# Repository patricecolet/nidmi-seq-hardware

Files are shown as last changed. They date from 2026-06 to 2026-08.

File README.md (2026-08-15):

# NiDMI Seq — Hardware

Cible matérielle du séquenceur **NiDMI Seq**. Design actif (branche
`etude/plexi-capacitif`) : **boîtier plexi + clavier piano capacitif 27 touches +
ruban**, **5 encodeurs** (→ 6 demandés, cf. BOM §3), **8 boutons PB86**, **écran 4,0″ 480×320**, LEDs SK6812,
MIDI (TRS), **CV/Gate**, sur **3× ESP32-S3-WROOM-1-N16R8**.

Le firmware embarquera le moteur `nidmi-sequencer-core` ; ce dépôt ne contient
que l'électronique (schéma, PCB, BOM, fabrication).

## Famille de dépôts

```
repo/
  nidmi-sequencer-core/   ← moteur séquenceur (DSP/logique)
  nidmi-seq-vst/          ← prototype VST/AU/Standalone (présentation + host)
  nidmi-seq-hardware/     ← CE DÉPÔT : carte ESP32-S3
```

## Arborescence

```
kicad/      projet KiCad (.kicad_pro / .kicad_sch / .kicad_pcb)
lib/        symboles & empreintes custom (.kicad_sym / .pretty)
scripts/    automatisation pcbnew (placement de grilles, génération)
docs/       architecture, choix de conception, BOM
```

## Docs (design actif)

- [`docs/VARIANTE_CAPACITIVE.md`](docs/VARIANTE_CAPACITIVE.md) — concept & rationale.
- [`docs/BOM.md`](docs/BOM.md) — **BOM figée** (réfs, cotes, implémentation) = source de vérité composants.
- [`docs/CONNECTEURS_MIDI.md`](docs/CONNECTEURS_MIDI.md) — connecteurs + front-end MIDI.
- [`docs/ETUDE_DIFFUSION_LED.md`](docs/ETUDE_DIFFUSION_LED.md) — étude lumière (chantier ouvert).
- [`mechanical/`](mechanical/) — modèle 3D paramétrique coté (OpenSCAD).
- [`docs/ARCHITECTURE.md`](docs/ARCHITECTURE.md) — *legacy* (ancienne archi MCP23017/PB86-touches).
- Ergonomie (source de vérité) : `nidmi-seq-vst/VISION_ERGO_HARMONIE.md`.

## Statut

🚧 Conception avancée : surface de contrôle + BOM figées, **sauf le nombre
d'encodeurs** — la conception en demande 6 au lieu de 5 (cf. [`docs/BOM.md`](docs/BOM.md) §3).
Électriquement acquis, mécaniquement à recaler. **Autre chantier ouvert** :
étude diffusion LED (cellule touche+LED). Ensuite : schéma KiCad.

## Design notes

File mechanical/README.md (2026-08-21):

# Mécanique — modèles paramétriques

> ## ⚠️ Deux fichiers sont PÉRIMÉS, gardés pour mémoire
> - **`facade.scad`** — implantation d'origine. Noires à espacement **régulier**
>   (ce n'est pas un clavier de piano), 5 encodeurs, écran 4,0″. Remplacé par
>   **`implantation.scad`**. Reste utile pour une seule chose : c'est le seul
>   modèle qui esquisse le **boîtier** (`show_box`).
> - **`cellule_plexi.scad`** — électrode dans une **poche fraisée** du plexi épais,
>   membrane de 1–1,5 mm. Concept **abandonné** : la pollution lumineuse mesurée
>   acceptable a permis de revenir au bloc plein, et l'électrode est passée sur une
>   plaque avant distincte. Remplacé par **`coupe_cellule.scad`**.
>
> Leurs rendus ont été supprimés du dépôt : une image fausse coûte plus cher
> qu'une image absente.

# Modèle d'origine (périmé) — façade plexi capacitive

Modèle **paramétrique OpenSCAD** de l'empilement façade :
**plexi** (couvercle) + **grille espaceur** (puits de lumière) + **PCB**
(électrodes capacitives en anneau + SK6812 centrale). Sert à visualiser
l'intégration LEDs / touch et à exporter STL (impression 3D, découpe).

## Fichier
- `facade.scad` — modèle. Tous les paramètres sont en tête de fichier
  (dimensions façade, pad, pitch, épaisseurs, trou LED, écran, encodeurs).

## Pré-requis
OpenSCAD (installé via `brew install --cask openscad`). Binaire : `openscad`.

## Rendu (images)
```sh
cd mechanical

# Vue de dessus + côtes (layout façade)
openscad -o facade_top.png --imgsize=1900,1050 --projection=p \
  --camera=184,75,0,0,0,0,650 -D 'show_dims=true' -D 'explode=0' facade.scad

# Vue éclatée (montre les 3 couches), sans côtes
openscad -o facade_explode.png --imgsize=1500,1100 \
  --camera=184,72,10,60,0,22,640 -D 'show_dims=false' -D 'explode=26' facade.scad

# Boîtier fermé (parois + fond + connecteurs)
openscad -o facade_box.png --imgsize=1700,1200 \
  --camera=160,80,-6,62,0,205,560 -D 'show_box=true' -D 'show_dims=false' -D 'explode=0' facade.scad

# Vue arrière (connecteurs : USB-C | MIDI IN/OUT | CV GATE CLK RST)
openscad -o facade_rear.png --imgsize=1800,900 \
  --camera=160,150,-8,74,0,180,360 -D 'show_box=true' -D 'show_dims=false' -D 'explode=0' facade.scad
```
`explode` : 0 = assemblé, >0 = écarte les couches en Z.
`show_dims` : true = affiche les côtes paramétriques (auto-lues des variables).
`show_box` : true = ajoute parois + fond + connecteurs (objet fermé).

## Cellule plexi épais (branche etude/plexi-epais-grave)
`cellule_plexi.scad` — coupe d'une cellule touche (électrode dans le plexi).
Deux variantes d'électrode via `elec_mode` :
- `"ring"` — anneau **cuivre** opaque + trou central, LED par le trou (membrane percée).
- `"ito"` — film **ITO transparent pleine surface**, la LED traverse l'électrode
  (membrane pleine, pas de hot-spot) + languette de contact. Cf. `docs/CONCEPT_PLEXI_EPAIS.md`.
```sh
# Coupe — variante anneau cuivre (cellule.png)
openscad -o cellule.png --imgsize=1500,950 \
  --camera=0,0,5,87,0,182,52 -D 'show_dims=false' -D 'elec_mode="ring"' cellule_plexi.scad
# Coupe — variante ITO pleine surface (cellule_ito.png)
openscad -o cellule_ito.png --imgsize=1500,950 \
  --camera=0,0,5,87,0,182,52 -D 'show_dims=false' -D 'elec_mode="ito"' cellule_plexi.scad
```
Params en tête : `plexi_t` (10), `membrane` (1,5), `wall`, `led_win`, `elec_mode`. `cut`=coupe.

## Clavier piano — géométrie de facteur (`clavier_piano.scad`)

Modèle dédié du clavier 27 touches, avec la **vraie irrégularité du piano** —
`facade.scad` plaçait les noires sur la limite entre deux blanches, ce qui n'est
pas un clavier de piano.

**Le modèle** : dans le groupe **do-ré-mi** (3 blanches, 2 noires) les talons de
blanche sont égaux entre eux ; dans le groupe **fa-sol-la-si** (4 blanches,
3 noires) ils le sont aussi, mais d'une *autre* valeur. D'où les décalages des
noires par rapport à la ligne de pas : **−1,25 / +1,25** pour do♯ et ré♯,
**−1,87 / 0 / +1,87** pour fa♯, sol♯ et la♯. Symétriques dans chaque groupe, et
**sol♯ exactement sur la ligne** — c'est la signature d'un clavier juste.

**Empilement modélisé** (cf. `../docs/ETUDE_DIFFUSION_LED.md`) : plaque acrylique
transparente découpée en 16 blanches séparées (chacune guide de lumière) · plaque
plus fine et sombre découpée en 11 noires, posée dessus · PCB de tranche **avant**
(16 LED, injection dans les blanches) · PCB de tranche **arrière**, moins haut
(11 LED, injection dans les noires) · caches avant/arrière masquant les PCB.

```sh
# Vue de dessus + côtes (décalages des noires, talons, largeur)
openscad -o clavier_top.png --imgsize=1900,900 --projection=p   --camera=145,29,0,0,0,0,430 -D 'show_dims=true' -D 'explode=0' clavier_piano.scad

# Vue éclatée (les 5 couches)
openscad -o clavier_explode.png --imgsize=1700,1150   --camera=147,25,12,60,0,22,640 -D 'show_dims=false' -D 'explode=24' clavier_piano.scad
```

### Échelle : format « mini-touches », pas piano réel

À `pitch_w = 18.5`, le clavier fait **294,8 mm** et tient dans les 320 mm de
façade. Au pas piano réel de 23,5 mm il faudrait **376 mm** — impossible ici.

Le facteur d'échelle est donc **0,787**… ce qui tombe précisément sur le format
**mini-touches** des contrôleurs du commerce (Arturia, Novation, Akai : 18–19 mm).
Ce n'est donc pas un compromis bâtard mais un standard établi, avec lequel les
joueurs sont déjà familiers.

**Largeur des noires — attention à la cote.** Une noire de piano est
**tronconique** : ~9,5 mm au sommet (où le doigt se pose) mais **13,7 mm à la
base**. Vue de dessus, et à plus forte raison sur une façade **plate** sans aucun
fruit, c'est la **base** qui fait la largeur apparente. Cotes normalisées :
blanche 23,5 mm, noire 13,7 mm → `black_ratio` = **0,583**. Prendre la cote du
sommet donne des noires visiblement maigres.

**Talons des blanches** (partie étroite entre les noires). Des talons **tous
égaux sont mathématiquement impossibles** : il faudrait résoudre en même temps
`3W = 3w + 2B` (groupe do-ré-mi) et `4W = 4w + 3B` (groupe fa-sol-la-si), ce qui
n'admet de solution que pour `B = 0`, donc sans noires. L'arrangement optimal des
facteurs de piano, et le défaut du modèle :

| | talon |
|---|---|
| do, ré, mi | `W − 2B/3` |
| fa, sol, la, si | `W − 3B/4` |

L'écart entre les deux vaut `B/12` — c'est le minimum atteignable.
Refs : [mathpages](https://www.mathpages.com/home/kmath043.htm) ·
[quadibloc](http://quadibloc.com/other/cnv05.htm) ·
[PianoReport](https://pianoreport.com/piano-key-size/)

`tails = [...]` permet de forcer les sept cotes pour coller à un clavier
particulier.

> **Contrainte** : somme des 7 talons + 5 × largeur de noire = 7 × pas. Sinon les
> talons dérivent par rapport aux faces avant, qui restent à pas égal. Le modèle
> vérifie et le signale par un `echo`.

### Les deux plaques découpées, et le travail que ça représente

```sh
openscad -o plaque_blanches.png --imgsize=2000,560 --projection=o \
  --camera=147,29,60,0,0,0,330 -D 'vue_plan=true' -D 'piece="blanches"' clavier_piano.scad
openscad -o plaque_noires.png --imgsize=2000,560 --projection=o \
  --camera=147,29,60,0,0,0,330 -D 'vue_plan=true' -D 'piece="noires"' clavier_piano.scad
```

| plaque | matière | pièces | longueur de coupe |
|---|---|---|---|
| blanches | acrylique clair **10 mm** | 16 | **4,03 m** (dont 22 encoches de 36,8 mm) |
| noires | acrylique teinté **5 mm** | 11 | **1,03 m** |
| | | **27** | **5,06 m** |

> **Découpe laser, pas Dremel.** Ces 4 mètres sont des **chants optiques** : ce
> sont eux qui font fonctionner le guide de lumière, donc chacun doit être poli.
> Le laser fond la matière au lieu de l'arracher et sort des chants
> **naturellement polis, de qualité optique** — on obtient gratuitement ce que le
> Dremel imposerait de polir à la main sur 4 mètres. Pour un guide de lumière ce
> n'est pas un confort mais une condition de fonctionnement.
>
> Le Dremel reste l'outil de la **gravure au dos**, qui veut au contraire une
> surface diffusante.

## Édition interactive
Ouvrir `facade.scad` dans l'app OpenSCAD → fenêtre de preview, on tourne/zoome,
on modifie un paramètre, F5 = aperçu, F6 = rendu final.

## Export STL (impression / découpe)
```sh
# Plexi seul, à plat, pour découpe laser ou impression
openscad -o plexi.stl -D 'explode=0' facade.scad   # (puis isoler la couche voulue)
```
> Pour exporter une couche isolée, commenter les deux autres appels en bas de
> `facade.scad` (`layer_pcb(); layer_spacer(); layer_plexi();`).

## À garder en tête (cf. `../docs/VARIANTE_CAPACITIVE.md`)
- Le modèle est **illustratif** (proportions justes, pas un fichier de fab).
- Entrefer `spacer_t` = compromis sensibilité capacitive ↔ logement LED.
- Hauteur LED `led_h` à caler sur le boîtier SK6812 réel (3535 ≈ 1,6 mm).
- Layout façade = format compact 4×4 (~170×262) ; modifiable via les paramètres.

## Implantation de façade — deux variantes (`implantation.scad`)

Toutes les cotes de façade sont **calculées depuis les composants** : changer une
dimension de composant recalcule l'objet, et les totaux sortent en `echo`. Le
clavier est **importé** de `clavier_piano.scad`, pas redessiné.

```sh
openscad -o implantation_complete.png --imgsize=1400,1150 --projection=o \
  --viewall --autocenter -D 'variante="complete"' implantation.scad
openscad -o implantation_modeste.png --imgsize=1400,1150 --projection=o \
  --viewall --autocenter -D 'variante="modeste"' implantation.scad
```

| variante | façade | contenu |
|---|---|---|
| **complete** | **328 × 185 mm** | clavier 27 touches, écran, 6 encodeurs, 8 boutons, ruban 136 mm |
| **modeste** | **230 × 141 mm** | idem **sans clavier** — module de bureau, notes par MIDI externe |

**Le 6ᵉ encodeur passe** (décision 🔴 du BOM §3), en **deux rangées de trois** au
pas de 30 mm. En une seule rangée de six au pas de 33 il fallait 306 mm pour 296
disponibles ; en 2×3 la rangée haute ne fait plus que 206 mm de large.

**Le ruban passe de 180 à 136 mm** : boutons + ruban sur une même rangée
demandaient 340 mm pour 296 disponibles.

> **Place disponible pour l'écran : 206 mm de large**, contre 108 pour le module
> 4,0″ actuel. Un **7 pouces** (≈165 × 100 mm) rentre en largeur sans rien
> déplacer ; il coûte ~38 mm de profondeur (façade complète ~223 mm) et remplit
> le quadrant supérieur droit, actuellement vide.

> **Les deux variantes partagent la même rangée haute** (écran + encodeurs,
> 206 × 62). La modeste = la complète moins la rangée clavier — même
> sous-ensemble électronique et même firmware d'interface possibles.

## Plan global d'encombrement — `implantation.scad -D plan=true`

> 🟢 **2026-08-21 — le boîtier peut être dessiné.** Les cotes du CrowPanel
> Advance 7.0-HMI ont été **fournies par l'utilisateur**, qui a passé la commande
> et relevé les dimensions : elles ne figurent ni sur la fiche produit ni sur
> espboards. C'est la référence du projet — **ne pas chercher à les re-sourcer**.

> ⚠️ **Un seul fichier, pas trois.** Le plan a d'abord été écrit dans un
> `encombrement.scad` séparé, et `boite.scad` traînait encore à côté. Résultat :
> **trois modèles avec trois cotes de clavier différentes** (58+5, 52+18, et un
> ruban placé dans une rangée derrière le clavier). Les deux fichiers en trop ont
> été **supprimés** et tout est revenu dans `implantation.scad`.
>
> **Règle qui en sort : on corrige le modèle existant, on n'en ajoute pas un à
> côté.** Un modèle de plus, c'est une cote de plus à tenir à jour, et c'est comme
> ça qu'on fabrique des contradictions.

```sh
# le PLAN (3 vues 2D cotées)
openscad -o encombrement.png --imgsize=1500,2500 --projection=o \
  --camera=175,-15,0,0,0,0,1900 --colorscheme=Tomorrow -D 'plan=true' implantation.scad

# le modèle 3D de la façade (comportement par défaut, inchangé)
openscad -o implantation_complete.png --imgsize=1400,1150 --projection=o \
  --viewall --autocenter -D 'variante="complete"' implantation.scad
```

Chaque vue **nomme son plan de coupe** — c'est le point d'ambiguïté récurrent :

| vue | plan de coupe |
|---|---|
| **A** dessus | aucun — façade de face, tranche arrière rabattue au-dessus |
| **B** coupe longitudinale | vertical, axe avant-arrière, **au milieu** : traverse le clavier **et** l'écran |
| **C** coupe transversale | vertical, gauche-droite, **au droit de la rangée haute** |

Le clavier **en travers** n'est pas repris — `coupe_cellule.scad` le traite.

### Ce que le plan donne

| | cote |
|---|---|
| façade | **337,26 × 226,36 mm** (hors-tout 342,26 × 231,36) |
| hauteur intérieure | **33 mm** — minimale calculée 32,6 |
| hors-tout | **342 × 231 × 36,5 mm** |

**La largeur est imposée par la rangée haute** (313,26 mm), pas par le clavier
(298,8).

### La façade est un cache, et le plexi passe dessous

Décidé le 2026-08-21. La pièce de plexi n'affleure plus : elle est **sous la
façade**, que le doigt atteint par **deux ouvertures** — une pour les touches,
une pour le ruban. La bande de façade entre les deux **masque le dos du peigne
des noires et la zone de contact du film**, et un bord arrière masque la fin du
dos.

> 🔴 **Conséquence : le dos ne pouvait pas rester à 18 mm.** Il ne loge pas que
> le ruban ; il doit aussi donner à la façade de quoi cacher. Décompte :
>
> | | mm |
> |---|---|
> | cache (entre les deux ouvertures) | **6** 🔴 estimé |
> | jeux d'ouverture (3 × 1) | 3 |
> | ruban | 10 |
> | bord arrière | **5** 🔴 estimé |
> | **dos nécessaire** | **24** — il en manquait **6** |
>
> La pièce de plexi passe donc de 70 à **76 mm**, et la façade de 220,36 à
> **226,36**. Les deux valeurs en rouge sont des estimations : la largeur du cache
> devrait être dimensionnée sur l'encombrement réel de la reprise de contact
> (piste d'argent + connecteur ZIF), qui n'est pas encore arrêtée.

> ⚠️ `clavier_piano.scad` porte `Wh` et `dos` **en dur** (`use <>` n'importe pas
> les variables). Ils doivent valoir ce que calcule `implantation.scad` —
> **76 et 24**. Un echo le vérifie et crie `DESYNCHRONISE` sinon : c'est
> exactement le décalage qui, la fois précédente, avait laissé le ruban hors du
> plexi.

> 🔴 **Le poste dimensionnant en hauteur n'est plus l'écran : c'est le PB86.**
> À 20 mm il dépasse les 16 mm du CrowPanel. Or cette cote est **estimée** — le
> BOM note « hauteur/cap non publiés → STEP GrabCAD (`pb86-switches-1`) ». Tant
> qu'elle n'est pas relevée, l'épaisseur de l'instrument n'est pas figée.
>
> Les **~25 mm** du BOM §11 sont périmés : ils dataient du module 4,0″.

> 🟡 **Pas encore placés** : le PCB principal, les deux ESP32 et le câblage. Leur
> volume est réservé (12,6 mm) mais leur position attend le KiCad. Les zones
> **jaunes** sont ce qui reste libre.

### Les cartes, et la place qu'elles ont

Quatre cartes identifiées, plus l'alimentation qui n'est pas placée.

| carte | taille | note |
|---|---|---|
| **latérale gauche** (ESP32-B) | **71,5 × 131,9 mm** — 94 cm² | double face : boutons + molettes devant, ESP32 derrière |
| **latérale droite** (ESP32-C) | idem | idem |
| **LED avant** | 294,8 × 8 mm, verticale | 16 LED, injection en tranche des blanches |
| **LED du dessous** | 294,8 × 56 mm | posée sur le socle, dans la découpe de la mousse |

**Les latérales sont dimensionnées au maximum utilisable**, pas à l'emprise des
commandes. La rangée de boutons et molettes ne fait que 66 × 108,36 (71,5 cm²) ;
en prenant tout ce qui est libre à cette hauteur on obtient **94 cm², soit un
tiers de plus**. Les limites sont réelles, pas arbitraires :

- **en largeur**, jusqu'au bord de l'écran — au-delà, le CrowPanel descend à
  −16 mm alors que la carte est à −9,6 : elle ne peut pas passer dessous ;
- **en profondeur**, de l'arrière du clavier à la paroi arrière — vers l'avant, la
  pièce de plexi descend à −16,3 et barre le passage.

Hauteur disponible : **8 mm au-dessus** de la carte pour les composants
traversants, **23,4 mm en dessous** pour tout le reste. La carte s'arrête à 2 mm
de la paroi arrière, donc l'USB-C et des jacks peuvent y être **en bord de carte**.

**La connectique est en bord de carte**, plus de carte de connectique séparée ni
de fils vers la tranche : les latérales arrivent à 2 mm de la paroi arrière.

| | contenu | occupé / dispo |
|---|---|---|
| **gauche** | USB-C + CV, GATE, CLK, RST | **71** / 71,5 mm |
| **droite** | MIDI IN, MIDI OUT + audio L/R | **62** / 71,5 mm |

La répartition sépare l'**alimentation** (USB-C et les sorties 5 V, à gauche) des
**sorties audio** (à droite, loin du convertisseur à découpage, et du côté où
irait le moteur audio). L'entraxe de 12 mm n'est pas dicté par les embases mais
par le **diamètre des fiches** : une fiche 3,5 fait ~9 mm de corps, il faut
pouvoir la saisir. Le côté gauche est plein à 0,5 mm près.

> ⚠️ **Corrigé au passage** : `n_jack` valait **5** alors que son propre
> commentaire listait six jacks — MIDI IN, MIDI OUT, CV, GATE, CLK, RST. Il
> manquait donc un jack sur la tranche depuis le début.

> 🟡 Reste ouvert : ces deux cartes sont-elles **identiques** ? L'implantation
> étant boutons à l'extérieur et molettes à l'intérieur des deux côtés, la même
> carte tournée de 180° présente le bon ordre de l'autre côté — un seul dessin,
> une seule série. Charger l'une de l'alimentation et l'autre du moteur audio y
> ferait renoncer.

### Trois erreurs de dessin corrigées le jour même

**Les noires étaient tracées en bande pleine.** La position était juste mais la
lecture fausse : la bande coupait le plexi en deux et laissait croire que **la
pièce s'arrêtait avant le ruban**, alors qu'elle est d'un seul tenant — 52 mm de
blanches plus 18 de dos. Les onze noires sont maintenant tracées séparément, aux
décalages de facteur de piano, pour qu'on voie les **talons des blanches** passer
entre elles. C'est l'article 2 du skill `conception-meca` : le relief des noires
est **usiné dans la plaque**, il n'interrompt rien.

**La coupe B montrait un relief de noire qui n'existe pas là.** Prise au milieu,
elle tombe entre **si et do** — deux blanches adjacentes.

**Le clavier était dessiné en un bloc de 16,3 mm**, ce qui le faisait paraître
plus épais que l'écran. Faux : **le plexi ne fait que 10 mm**, donc *moins* que
les 16 de l'écran. Les 6 mm restants sont la **suspension** — mousse et socle.
Les couches sont désormais distinctes et cotées.

### Cotes réconciliées entre les trois modèles

`clavier_piano.scad` portait encore la géométrie d'avant l'architecture arrêtée.
Aligné sur `coupe_cellule.scad` :

| | avant | après |
|---|---|---|
| **pièce entière** (`Wh`) | 58 | **70** |
| dos du peigne (`dos`) | 5 | **18** — il porte le ruban |
| noire (`Bh` / `Lb`) | 36 | **32** |
| noires (`t_noires`) | plaque teintée 5 mm | **relief usiné de 1 mm** |
| caches | affichés | **supprimés** — c'est la boîte qui fait cet office |

> 🔴 **Le piège qui a fait rater le clavier deux fois : `Wh` est la longueur
> TOTALE de la pièce, dos inclus** — et non la partie avant. C'est
> `y_dents = Wh - dos` qui donne la fin des touches. En lisant `Wh` comme « la
> blanche » et en posant `Wh = 52, dos = 18`, on obtient une pièce de **52 mm**,
> pas de 70 : le plexi s'arrête alors **16 mm avant le ruban**, qui flotte dans le
> vide. Bon réglage : `Wh = 70`, `dos = 18`.
>
> Deux conséquences ont dû être corrigées dans la foulée :
> - `by0` mesurait la noire **depuis le fond de la pièce**, donc le dos la
>   rognait — avec un dos de 18 il n'en restait que 14 mm au lieu de 32. La noire
>   part maintenant de `y_dents - Bh` : elle fait `Bh` et **bute sur le dos**.
> - `noires_2d()` **inclut `dos_2d()`**, héritage de l'époque où les noires
>   étaient une plaque teintée rapportée avec son propre dos. Utilisé tel quel, le
>   dos sortait tout noir et le ruban disparaissait dessous. Le modèle 3D appelle
>   donc `blacks_2d()`, qui ne donne que le relief.
>
> 🟡 **Reste à trancher** : `clavier_piano.scad` sépare les blanches sur toute la
> zone de touche (52 mm), alors que `coupe_cellule.scad` arrête le trait de scie à
> **20 mm**. Les deux ne peuvent pas être vrais.

> ⚠️ `use <>` n'importe **que les modules et fonctions, pas les variables**. Les
> décalages des noires sont donc recopiés dans `implantation.scad` (`noires_plan`)
> pour la vue de dessus du plan, et doivent suivre `clavier_piano.scad`.

## Assemblage du clavier (`coupe_cellule.scad`)

> ### 🟢 2026-08-21 — architecture arrêtée en séance de conception
>
> Trois décisions structurent tout le reste. Elles remplacent le clavier plat et
> le peigne rapporté, tous deux abandonnés le même jour.

**1 — Une plaque continue d'acrylique par-dessus l'ITO**, avec le relief des
noires **usiné dedans**. Elle pince le film sur toute sa surface, protège
l'électrode partout et supprime la colle. Le doigt voit 1 mm sur une blanche,
2 mm sur une noire.

> 🔴 **Le seul chiffre qui verrouille le reste : l'aftertouch à 1–2 mm.**
> Mesuré : à travers **0,125 mm** (PET seul) la marge suffit ; à travers **10 mm**
> le contact est détecté mais l'aftertouch est perdu. L'intervalle n'est pas sondé.
> Se pince en un quart d'heure en empilant des chutes de PET sur une électrode et
> en relevant la dynamique entre effleurement et appui franc.
> **Une noire en relief rapporté de 3 mm était condamnée par là** : aftertouch sur
> les blanches et pas sur les noires, intenable sur un clavier.

**2 — Un seul film ITO pour tout**, touches et ruban gravés d'un seul coup. Un
seul calage, figé par le **masque** et non par le montage.

**3 — Trois éclairages indépendants.** Les blanches par la tranche avant, en
lumière guidée, extraite par la gravure. Les **noires et le ruban par en
dessous**, sur une **même carte horizontale**.

> **L'argument optique qui rend le point 3 possible.** Une LED couplée par
> l'**air** n'émet dans le PMMA qu'à **±42°** — exactement l'angle critique. Tout
> sort donc au premier contact et **rien ne passe en mode guidé** : cette lumière
> ne peut pas voyager horizontalement, donc elle n'interagit pas avec la gravure
> des blanches. Deux corollaires à ne jamais oublier :
> - **ne rien coller sous ces LED** — un indice ~1,5 rouvrirait le cône à 90° et
>   l'isolement disparaîtrait ;
> - **satiner le dessous de la plaque**, jamais la face inférieure du bloc, qui
>   renverrait de la lumière en mode guidé.

### Ce qui a été supprimé, et ce que ça rapporte

| supprimé | pourquoi | gain |
|---|---|---|
| cloison transversale + 2ᵉ symbole | l'écran porte le détail | 16 rainures et 16 lamelles en moins |
| lamelle noire des traits de scie | apportait plus de problèmes que de solutions | 15 pièces en moins |
| fente arrière + PCB partagé par la tranche | les LED sont passées dessous | une lame verticale en moins |

Le trait de scie **s'arrête à 20 mm** au lieu de descendre jusqu'à l'arrière :
plus aucun trait sous les noires ni sous le ruban, le bloc reste continu à
l'arrière, et les dents passent de porte-à-faux de 52 mm à des entailles de 20.
Le peigne cesse d'être la pièce fragile du projet.

Ce que portait le 2ᵉ symbole se répartit : **l'écran** prend le détail, la **LED
de la blanche** porte la grille métrique en fond sous l'état actif, et **un trait
de scie sur quatre** marqué donne le repère au doigt — les 16 blanches sont déjà
une rangée de 16 pas uniformes, il suffit de la marquer.

### Les cinq vues

**A** coupe en travers avant (moins de 20 mm du bord : la seule zone fendue) ·
**B** coupe en travers arrière au droit d'une noire (bloc continu, poche et LED
par en dessous) · **C** coupe en long d'une blanche jusqu'au ruban · **D** vue de
dessus du bloc (ce qui est usiné, et où) · **E** le film à plat.

```sh
openscad -o coupe_cellule.png --imgsize=1500,3000 --projection=o \
  --camera=58,-192,0,0,0,0,1080 --colorscheme=Tomorrow coupe_cellule.scad
```

| couche | ép. | rôle |
|---|---|---|
| **plaque acrylique** | 1 mm | la surface touchée · relief des noires usiné dedans (+1 mm) |
| **PET** | 0,125 mm | porteur du film |
| **ITO gravé** | ~0 | îlots d'électrodes ; la **garde est la mer** autour |
| film d'air | ~0,1 mm | le film est **plaqué** par la plaque, pas collé |
| **bloc PMMA** | 10 mm | guide de lumière des blanches · traits de scie sur 20 mm · poches par le dessous |
| fond sombre | ~0,05 mm | absorbe le halo non extrait · **fenêtre** sous chaque noire |
| mousse | 3 mm | **le ressort** — à faible déformation rémanente |
| socle | 2 mm | référence **rigide** des LED |

### Contact de l'électrode

**On ne contacte jamais l'ITO directement.** L'industrie sérigraphie par-dessus
une piste d'**argent** — le liseré sombre au pourtour des dalles tactiles — et
c'est l'argent qu'on contacte. L'encre d'argent fait ~0,01 Ω/□ contre ~100 Ω/□
pour l'ITO, soit des milliers de fois moins : **la distribution peut donc rester
sur le film** et sortir par une queue unique dans un connecteur à charnière.

Deux règles quelle que soit la solution retenue :

- la contrainte sur l'ITO doit être **uniquement perpendiculaire** à la surface.
  Jamais de cisaillement, jamais de traction : il fissure.
- **ancrer le film au niveau du contact** et le laisser flotter à l'autre bout.
  L'acrylique se dilate ~4× plus que le PET — **0,3 mm** sur la longueur du
  clavier pour 20 °C — et un film pincé aux deux bouts se met en tension.

> 🟡 L'argent migre sous tension continue en milieu humide. Parade proportionnée :
> surimpression diélectrique laissant les plages nues, ou vernis de tropicalisation
> sur la jonction. Le risque reste faible ici — plages espacées de millimètres,
> 3,3 V, boîtier clos, et pilotage en charge-décharge plutôt qu'en continu.

### La carte LED du dessous, et la découpe de la mousse

🔴 **La carte LED est POSÉE SUR LE SOCLE, et la mousse est découpée pour elle.**
Point rappelé par l'utilisateur le 2026-08-21 après avoir été perdu une fois —
il ne doit plus l'être. Trois conséquences :

- **Elle ne s'ajoute pas à l'empilement.** Elle vit *dans* l'épaisseur de la
  mousse, pas entre le bloc et elle. Le clavier reste à 16,3 mm sous la face
  touchée.
- **La mousse est le ressort ; la découper lui retire de l'appui** là où la carte
  passe, c'est-à-dire sous les noires et sous le ruban — donc sur presque toute la
  largeur. Il faut vérifier ce qu'il reste comme surface d'appui, et où, sinon le
  bloc s'appuie sur une couronne et fléchit au milieu.
- **La cote tombe juste, mais sans marge** : carte ENIG 0,6–0,8 + SK6812 3535
  ~1,9 = **~2,7 mm** au-dessus du socle, pour **3 mm** de mousse. La LED affleure
  sous le bloc sans entrer dans la poche — l'air est conservé, ce qui est
  exactement ce qu'on veut pour garder le cône à ±42°.

### Serrage

**Ne jamais serrer du rigide sur du rigide** : la pression devient imprévisible et
l'acrylique fissure. La **mousse est le ressort** ; les vis ne fixent qu'une
position, la mousse la convertit en force. Elle pousse le bloc contre la lèvre du
cadre supérieur, ce qui référence la face touchée sur une pièce **rigide** — c'est
ce qui garantit que la distance LED↔surface, donc le **diamètre des taches**,
reste identique d'une touche à l'autre.

On dimensionne donc un **écrasement**, pas un couple. Vis M3 dans des écrous logés
en poches usinées, jamais de taraudage dans l'acrylique, un point tous les 50 à
80 mm, et des **trous de passage surdimensionnés** à cause de la dilatation.

### Ruban

Sur le dos du peigne, même pièce de plexi — 24 mm de profondeur de façade libérés
puisqu'il n'a plus de rangée propre. **5 canaux**, interpolation spatiale, cotes
d'AT11805 : segments de bout **33,75 mm**, de milieu **56,25 mm** sur 180, zone
morte ramenée de 10 % à **3 %**, dents **4 mm** max et **0,25 mm** mini en pointe.

C'est un **témoin**, pas un vu-mètre : peu de LED et **interpolation lumineuse**
entre voisines, le recouvrement des halos faisant glisser la tache. Critère de
choix du pas : **pas ≤ largeur du halo**, à mesurer au banc. Le fondu ne sera pas
linéaire (le PWM l'est, la perception non) — la courbe se règle à l'œil.

> 🟡 **`clavier_piano.scad` modélise encore les noires en plaque teintée de 5 mm**
> — à réconcilier quand les cotes seront figées.

## Coupe d'une cellule (`coupe_cellule.scad`) — ⛔ **VERSION PÉRIMÉE, gardée pour mémoire**

> ⛔ **Ce qui suit décrit l'architecture d'AVANT le 2026-08-21** : deux plaques séparées
> par un entrefer de 1,5 mm, plaque avant de 2 mm, noires en relief rapporté de 3 mm,
> 18,7 mm d'empilement. **Remplacée** par « Assemblage du clavier » plus haut — plaque
> continue de 1 mm, relief usiné dedans, film plaqué sur le bloc.
>
> 🟡 **Un point de cette section reste ouvert et n'a pas été rejugé** : l'argument optique
> qui justifiait l'entrefer. L'ITO plaqué contre la face du guide met celui-ci en
> **réflexion totale frustrée** (l'indice du PET est proche de celui du PMMA) — la lumière
> sortirait sur tout le trajet au lieu de sortir aux points gravés. L'architecture actuelle
> a ramené l'entrefer à un **film d'air de ~0,1 mm**. Est-ce suffisant ? **À trancher.**

Coupe **en travers du clavier** : deux blanches et la noire posée à cheval.
Dessinée **explicitement en 2D** plutôt que découpée dans un modèle 3D — ce qu'on
voit est exactement ce qu'on a voulu montrer.

```sh
openscad -o coupe_cellule.png --imgsize=2000,900 --projection=o \
  --camera=50,-10,0,0,0,0,142 coupe_cellule.scad
```

| couche | ép. | rôle |
|---|---|---|
| plaque avant PMMA | 2 mm | surface touchée, rainures peu profondes côté doigt |
| ITO + bus bar | 0,125 mm | **électrode, découpée par touche** + garde à la masse |
| **entrefer** | 1,5 mm | garde la réflexion totale **et** loge les fils de bus bar |
| guide de lumière | 10 mm | LED en tranche, gravure (points, gradient) au dos |
| fond sombre | ~0,05 mm | absorbe le halo non extrait → contraste + anti-pollution |
| mousse | 3 mm | répartit la pression vers l'avant |
| plaque arrière | 2 mm | vissée **en périphérie** — aucune fixation visible |
| | **18,7 mm** | + 3 mm de relief pour les noires |

**Pourquoi deux plaques et pas un bloc.** Le guide ne fonctionne que si ses faces
sont au contact de l'**air**, et le capacitif veut l'électrode **près du doigt**.
Deux arrangements plus simples ont été écartés :

- **électrode derrière le guide** (doigt → 10 mm) : 1 % de signal mesuré, pas
  d'aftertouch, et l'ITO plaqué contre la face gravée met le guide en réflexion
  totale frustrée — la lumière sort partout au lieu de sortir aux points ;
- **électrode sur la face avant du guide** : capacitif excellent, mais l'indice du
  PET est proche de celui du PMMA → la lumière s'échappe sur tout le trajet.

L'entrefer résout les deux : il maintient la réflexion totale et sépare l'ITO de
la face gravée. Il sert en plus de logement aux fils de bus bar.

**Ce que la coupe montre au droit d'une noire.** L'électrode de la noire (violet)
est **dans le même plan** que celles des blanches : un seul film ITO porte le
**dessin complet du clavier**. Et les électrodes des blanches **s'arrêtent de part
et d'autre** — c'est l'équivalent électrique exact du talon de blanche sur un
piano. Sans cette troncature, toucher une noire déclencherait les deux blanches
sous elle. La géométrie de facteur de piano n'est donc pas qu'une affaire
d'apparence : **c'est le dessin de l'électrode**.

La noire est par ailleurs **son propre guide de lumière**, gravure sur sa face
inférieure, injection par la tranche arrière (invisible en coupe transversale).

> ⚠️ **Les noires sont pénalisées deux fois** : le doigt est à **5 mm** au lieu de
> 2 (3 mm de relief + 2 de plaque), **et** l'électrode est plus petite (~8,4 × 36
> contre ~16 × 45). Le signal variant en gros comme surface/distance, une noire
> est de l'ordre de **six fois moins sensible** qu'une blanche. La détection passe
> largement — seuils par canal, marge de plusieurs centaines. L'**aftertouch**, lui,
> devient douteux sur les noires.
>
> L'épaisseur de la plaque teintée n'est donc **pas** un simple choix
> d'approvisionnement, c'est un **paramètre capacitif** : à 2 mm au lieu de 3, le
> rapport tombe de 6 à ~4,5.

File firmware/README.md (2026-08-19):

# firmware — bancs de test

Croquis Arduino de mesure, pas de code produit. Compilés avec `arduino-cli`
(core `esp32:esp32` 3.3.1, IDF 5.5).

## `test_touch_ito/` — sensibilité capacitive d'une électrode ITO

Lit N canaux *touch*, calibre une ligne de base + son bruit au démarrage, puis
sort en continu du CSV `t_ms,ch,raw,delta,snr` sur le port série à 115200.
`delta` est normalisé **positif au toucher** sur les deux générations de touch
(v1 ESP32 : la valeur descend ; v2 S2/S3 : elle monte).

Broches par défaut (à ajuster en tête du `.ino`) :

| Cible | Canaux | GPIO |
|---|---|---|
| ESP32-S3 (touch v2) | TOUCH4–7 | 4, 5, 6, 7 |
| ESP32 classique (v1) | T0, T4, T6, T7 | 4, 13, 14, 27 |

Sur S3 tout GPIO1–14 est touch-capable ; on évite 0 / 45 / 46 (strapping).

### Compiler et téléverser

```sh
cd firmware/test_touch_ito

# ESP32-S3-WROOM-1 N16R8, via le port USB-UART de la carte
arduino-cli compile -b esp32:esp32:esp32s3:PSRAM=opi,FlashSize=16M .
arduino-cli upload  -b esp32:esp32:esp32s3:PSRAM=opi,FlashSize=16M -p /dev/cu.usbXXXX .

# variante : port USB natif du S3 (série sur l'USB de la puce)
arduino-cli compile -b esp32:esp32:esp32s3:PSRAM=opi,FlashSize=16M,CDCOnBoot=cdc .

# ESP32 classique
arduino-cli compile -b esp32:esp32:esp32 .
```

Trouver le port : `ls /dev/cu.usb*` (ou `arduino-cli board list`).

### Lire les mesures

```sh
arduino-cli monitor -p /dev/cu.usbXXXX -c baudrate=115200   # brut
scripts/touch_log.py --secs 10 --out mesures/ito_25mm_plexi15.csv \
                     --label "ITO 25x25 / membrane 1,5 mm"   # + résumé stats
```

Commandes série : `b` = refaire la ligne de base (main éloignée), `h` = aide.

### Observer en direct pendant un test

```sh
scripts/touch_scope.py --port /dev/cu.usbmodemXXXX   # puis http://localhost:8765
```

Sert une page locale qui se rafraîchit toute seule : **histogramme** des valeurs
brutes (vue principale), chronogramme, stats par canal, et un bouton qui envoie
la recalibration à la carte.

L'histogramme est la bonne vue ici, et pas la moyenne : un contact intermittent
apparaît comme **plusieurs pics séparés** — broche nue / électrode au repos /
doigt posé — là où une moyenne afficherait une valeur intermédiaire qui ne
correspond à aucun état réel. C'est ce qui a permis de voir que l'électrode
décrochait, et pas seulement qu'elle était « bruitée ».

**Le scope redémarre la carte en s'y connectant**, et c'est nécessaire : sur l'USB
natif du S3, une carte déjà en marche dont l'hôte précédent s'est déconnecté
**n'émet plus rien** pour le suivant. Le reset garantit aussi une entête (donc la
correspondance canal→GPIO) et une ligne de base fraîches. Compter ~10 s de
préchauffage et de calibration, main éloignée. `--no-reset` pour s'attacher sans
perturber une mesure en cours — mais la carte peut alors rester muette.

> Un seul programme à la fois peut ouvrir le port série : arrêter `touch_log.py`
> avant de lancer `touch_scope.py`, et inversement. Le scope reprend tout seul
> si la carte est débranchée puis rebranchée.

> Commandes série du croquis : `b` = recalibrer · `i` = réimprimer l'entête
> canal→GPIO (sans toucher à la ligne de base) · `h` = aide.

Protocole d'essai complet : [`docs/ESSAI_ITO_ESP32.md`](../docs/ESSAI_ITO_ESP32.md).

## `banc_cellules/` — cellule complète : 4 touches + 4 LED appairées

Le banc à utiliser pour tester une implantation réelle. Reprend la mesure tactile
de `test_touch_ito` (même format CSV, donc `touch_scope.py` et `touch_log.py`
fonctionnent tels quels) et y ajoute 4 LED, **une par canal**.

| | broches |
|---|---|
| électrodes | GPIO **8, 9, 10, 12** |
| LED | GPIO **15, 16, 17, 18** → `100 Ω` → anode ; cathodes au GND commun |

**Modes LED** (boutons dans le client, ou touche série) : `t` tactile — la LED *n*
s'allume quand la touche *n* est touchée · `r` rampe 5 s · `c` clignotement ·
`f` fixe · `x` éteint. Luminosité au curseur (ou `L0`…`L255` en série).

Détection : seuil = `max(8σ, 150 counts)` au-dessus de la ligne de base, avec
**hystérésis à 60 %** pour éviter le battement quand le doigt effleure la limite.
Les seuils calculés sont affichés à la calibration, et chaque passage touché ⇄
relâché est annoncé sur le port série.

> **Les oranges, rouges et vertes traditionnelles (seuil ~2 V) se pilotent
> directement depuis un GPIO** en 3,3 V : (3,3 − 2,0)/100 = ~13 mA. Une **bleue**
> ou une **blanche** (seuil ~3 V) n'y arriverait pas — ~2 mA, invisible. Pour
> celles-là, rail 5 V et montage où le GPIO tire le courant (logique inversée).

## `scan_touch/` — quelles broches touch sont réellement utilisables

À passer **avant** de figer un brochage, et à chaque recâblage. Fait deux choses :

1. **Intégrité électrique** de GPIO1–14 (`INPUT_PULLUP` puis `INPUT_PULLDOWN`) :
   `pu=1 pd=0` = broche libre · `pu=1 pd=1` = tirée au 3V3 · `pu=0 pd=0` = à la
   masse. Une broche tirée d'un côté ou de l'autre **ne peut pas mesurer** : le
   pad ne se charge plus et le canal part en timeout.
2. **Balayage touch** des 14 canaux. Un canal qui rend `4194303` (0x3FFFFF) ne
   mesure pas — ce n'est pas une capacité énorme, c'est une mesure qui n'aboutit
   pas. Compter ~2 s par canal en échec.

**GPIO4 et GPIO5 sont le bus I2C de la carte** (SDA/SCL), avec leurs pull-ups de
10 kΩ montées d'origine — mesuré 9 kΩ vers 3V3, carte hors platine, contre 500 kΩ
sur GPIO6. Elles ne peuvent pas servir au tactile, et le BOM les réserve déjà à
l'I2C (MCP23017, MCP4728).

Mesuré sur la carte ESP32-S3-WROOM-1 N16R8 du proto : seules **GPIO8, 9, 10, 12**
donnent des valeurs exploitables (~30 000 counts, bruit σ = 8 à 104). Les autres
saturent, y compris des broches électriquement libres. Ne pas supposer qu'une
broche marche parce que la doc la dit touch-capable.

> Le message `touch_sensor_trigger_oneshot_scanning: Wait for measurement done
> timeout` du core 3.3.1 apparaît sur **tous** les canaux, y compris ceux qui
> rendent ensuite des valeurs valides. Ce n'est pas un critère d'échec.

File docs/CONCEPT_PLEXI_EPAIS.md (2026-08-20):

# Concept — électrodes DANS le plexi épais (proto Dremel)

> **Branche `etude/plexi-epais-grave`.** Alternative à la branche capacitive
> `etude/plexi-capacitif` (où l'électrode, portée par un PCB sous l'entrefer des
> encodeurs + 2 PCB, était à **5-9 mm** du doigt → capacitif trop faible).
> Ici l'électrode est **portée par le plexi lui-même**, à ~1,5 mm de la surface.
> Le reste de l'archi (3× ESP32-S3, écran, MIDI, CV, encodeurs, PB86, LED) est
> **réutilisé** depuis la branche capacitive ([`BOM.md`](BOM.md)).

## Problème résolu
Capacitif : sensibilité ∝ **surface électrode / épaisseur diélectrique**. Avec un
PCB loin sous le plexi, le diélectrique = entrefer (air) + plexi → trop épais.
→ On amène l'électrode **juste derrière la face avant**, dans le plexi.

## Principe
- **Plexi épais** (~**8-12 mm**, acrylique coulé) = panneau **et** substrat. Se
  perce / fraise / rainure **à la Dremel** (rotary tool), sans CNC.
- Au **dos**, par cellule : **poche fraisée** laissant une **membrane avant ~1-1,5 mm**.
- **Électrode** = feuille / ruban **cuivre** (ou peinture conductrice) collée au
  **fond de la poche** → ~1,5 mm du doigt → capacitif sensible.
- **LED** SK6812 dans une poche/perçage, éclaire via une zone **dépolie**.
- **Rainures** au dos pour le **câblage** (fils → pins *touch* ESP32).
- **Électronique** (3 ESP32, écran, expandeurs, alim…) sur une **petite carte** au
  dos, câblée aux électrodes (pas de grand PCB de façade).

## Coupe (principe)
```
   doigt
 ───────────────────────  face avant (lisse)
 ▓ membrane ~1,5 mm ▓▓▓▓   plexi (diélectrique fin devant l'électrode)
 ▓▓▓▒▒▒▒▒▒▒▒▒▒▒▒▓▓▓▓▓▓▓   ← électrode cuivre au fond de la poche
 ▓▓▓                 ▓▓▓   poche fraisée (Dremel) + rainure câblage
 ▓▓▓   ~8-12 mm plexi épais (structure)   ▓▓▓
 ═══════════════════════  dos → carte électronique câblée
```

## Ce qui change vs la branche capacitive
- **Plus de "spacer" ni de double PCB** pour les touches : le plexi est le support.
- Encodeurs / boutons PB86 / écran : **traversent** le plexi (perçages Dremel).
- LED : poches dans le plexi (au lieu de puits dans une grille espaceur).

## À tester sur proto (outils main)
- Sensibilité capacitive à travers **1-1,5 mm** de membrane (la valider en premier).
- **Précision Dremel à la main** : profondeur de poche régulière → gabarit/guide de
  profondeur ? fraise sur colonne ?
- Diffusion LED à travers plexi dépoli.
- Tenue de l'électrode (adhésif cuivre vs peinture conductrice) + fiabilité du contact câblé.

## Électrode transparente (ITO) — option pleine surface
Une électrode cuivre est **opaque** → elle force l'anneau + trou central (point chaud
au centre, électrode amputée). Alternative : **film ITO sur PET** (transparent conducteur,
~80 % de transmission, 5–100 Ω/□). On colle une électrode **pleine cellule** au dos de la
membrane → max de surface capacitive **et** la LED RGB **traverse** l'électrode (plus de
trou, plus de hot-spot). Se **coupe aux ciseaux** ; **ne se soude pas**.

### Procédure de contact ITO → circuit
On ne soude jamais sur l'ITO (couche de qqs 100 nm, détruite par la chaleur, l'étain ne
mouille pas). On fait un contact méca/adhésif sur une **languette** d'ITO, et on soude le
fil sur le **métal rapporté**.

1. Découper l'ITO avec une **languette d'amenée** au bord de la cellule (vers la rainure
   de câblage du dos).
2. Presser du **ruban cuivre à adhésif _conducteur_** (3M 1181 — pas du cuivre à adhésif
   isolant courant !) sur la languette, **surface généreuse** (R de contact ∝ 1/aire).
3. **Renforcer** le joint d'un point de **peinture/époxy argent** (anti-arrachement + baisse R).
4. **Souder le fil sur le cuivre**, jamais sur l'ITO. Vérifier la continuité ITO↔fil à
   l'ohmmètre : dizaines/centaines d'Ω = **normal et suffisant** pour le tactile.

> **L'ITO se fissure si on le plie.** C'est une couche céramique de quelques centaines de
> nanomètres sur un PET souple : le support plie, la couche conductrice non. Une pliure ou une
> marque d'ongle sur la languette crée des micro-fissures et un contact **intermittent** — le
> défaut se manifeste comme des décrochages francs vers la valeur « broche nue », pas comme du
> bruit. Garder la languette **plate**, y compris dans la pince.

### Contact de banc (sans matériel spécifique)
Avant d'avoir le 3M 1181, un contact provisoire suffisant pour mesurer :
souder le fil sur un **bout de feuille de cuivre** (ou de tresse à dessouder aplatie) **d'abord**,
loin du film ; poser ce cuivre **à plat** sur la face conductrice de la languette ; **serrer à la
pince** (pince double-clip, crocodile, ou bornier à vis avec le cuivre en interposition).
Vérifier à l'ohmmètre fil ↔ électrode : **dizaines/centaines d'Ω**, et **stable quand on remue
la jonction** — c'est la stabilité qui compte, pas la valeur.

> Ruban cuivre **ordinaire** (adhésif isolant) : la colle ne conduit pas. Le replier **par-dessus
> le bord** de la languette pour que le cuivre touche l'ITO directement, la colle ne servant qu'à
> tenir mécaniquement. Le 3M 1181, lui, conduit à travers l'adhésif — d'où son intérêt.

> **Pourquoi ça marche** : le self-cap (ESP32-S3) tolère **plusieurs kΩ** en série → la R
> de contact ITO n'est pas critique. Mais l'ITO est résistif (5–100 Ω/□) → **garder l'ITO
> limité à l'électrode**, repartir en **cuivre** dans les rainures vers les pins *touch*.

```
   ┌──── électrode ITO pleine cellule (dos de la membrane, LED traverse) ────┐
   └──── languette ITO ──┐
                         │  ← ruban cuivre adhésif CONDUCTEUR (3M 1181)
                         │     + renfort époxy/peinture Ag
                         ●  ← fil soudé SUR LE CUIVRE
                         └──→ rainure de câblage (dos) → pin touch ESP32
```

Variante **démontable** (carte au dos déconnectable) : languette ITO + **ruban Z-axis
3M 9703** + pad sur la carte, pincés par pression — aucune soudure sur la cellule.

### Réfs à commander (échantillons proto)
| Rôle | Réf | Format / note |
|---|---|---|
| **Film ITO/PET** | Adafruit #1309 | 100×200 mm, découpe ciseaux, ~80 % transm. |
| Film ITO (alt. plus grand) | MTI 14 Ω/□ (115 nm) · Thorlabs · Huanyu (Amazon) | 300×1000 mm si besoin de surface |
| **Ruban cuivre adhésif _conducteur_** | 3M 1181 | largeurs 6,35 / 50,8 mm × 16,5 m (~5–60 € selon largeur) |
| **Époxy argent** (joint robuste) | MG Chemicals 8331S | seringue 14 g, bi-composant |
| **Peinture argent** (renfort/rattrapage) | MG Chemicals 842AR | pot 15/150 ml, ou **stylo 842AR-P** 8,6 g |
| Ruban Z-axis (option démontable) | 3M 9703 | conduction par pression, axe Z uniquement |

> Distributeurs EU : RS, Digi-Key, shop-sks (DE). Prix indicatifs à confirmer à la commande.

## Bascule de design (2026-08-19, après mesure)

La mesure a validé le capacitif **avec une marge telle** que la contrainte d'origine tombe :
repos 47 000 → doigt 300 000, soit **×6,4**, sur un contact provisoire à la pince croco
(détail dans [`ESSAI_ITO_ESP32.md`](ESSAI_ITO_ESP32.md)). On n'a donc plus besoin que le plexi
serve de diélectrique mince.

**Nouvelle direction** : électrode ITO **près de la surface** sous un revêtement transparent fin,
**pourtour métallique** autour de chaque touche, et le **plexi dédié à la LED** (diffusion) plutôt
qu'au capacitif. Ça supprime le point le plus risqué du concept : la poche fraisée au Dremel avec
une membrane régulière à 1–1,5 mm, dont la faisabilité à la main restait douteuse.

**Le revêtement est déjà là.** L'ITO est déposé sur un **PET de ~0,125 mm**. En orientant le film
**PET vers le doigt, ITO vers l'intérieur**, le PET fait revêtement de protection : le doigt ne
touche jamais la couche conductrice, et le diélectrique ajouté est négligeable devant le ×6,4
mesuré. (Inverse la consigne « face conductrice vers le doigt », qui ne valait que pour compenser
l'épaisseur de plexi.)

**Pourtour métallique = bus bar de l'électrode** (pas une garde). C'est la technique standard des
dalles ITO et des panneaux EL : ceinturer l'électrode d'un conducteur en laissant le centre libre
pour la lumière. Deux effets :

- **Résistance de contact effondrée** : elle varie en 1/surface, et un pourtour complet en offre
  bien plus qu'une languette. Plus de point de fragilité unique, plus de languette à plier — donc
  plus de fissuration de l'ITO, la cause des décrochages mesurés.
- **Uniformité du potentiel** : l'ITO fait 5–100 Ω/□. Alimenté par un seul coin, le centre de la
  cellule voit plusieurs centaines d'ohms ; alimenté par tout le pourtour, la distance maximale au
  bus tombe à la moitié de la cellule. C'est la raison d'être des bus bars argent sérigraphiés.

**Il s'emboîte avec l'orientation PET-vers-le-doigt** : l'ITO étant tourné vers l'intérieur, le
pourtour se pose sur la face interne → **caché derrière le film, inaccessible au doigt** (plus de
souci d'ESD ni d'abrasion sur du métal exposé), et sans contrainte d'affleurement.

> **Conséquence à ne pas manquer** : ce pourtour est **au potentiel de mesure**, il fait partie de
> l'électrode. Le métal se couplant bien mieux que l'ITO, le **cross-talk se joue entre pourtours
> voisins** — c'est l'écart entre cadres, et non entre zones ITO, qui fixera le pas du clavier.
> Si l'écart seul ne suffit pas, prévoir une **piste de masse distincte entre les cellules**
> (là serait la vraie garde).

Réalisation proto : cadre au **ruban cuivre conducteur 3M 1181**, tracé au **stylo argent
842AR-P**, ou **broches de résistance** logées dans des rainures fraisées au Dremel (cf. coupon
ci-dessous). Vérification : résistance fil ↔ **centre** de l'électrode, à comparer au montage à
languette unique — c'est là que le gain doit se voir.

## Coupon d'essai 3 cellules (rainures Dremel + broches de résistance)

Cadres et garde réalisés en **broches de résistance** logées dans des rainures fraisées au dos du
plexi. Conductivité largement suffisante : même en acier cuivré, la broche est négligeable devant
les 5–100 Ω/□ de l'ITO. **Décaper les broches** (papier de verre fin) — vernis ou oxyde suffisent
à ruiner un contact par pression.

> ⚠️ **Deux conducteurs de nature opposée, physiquement semblables, dans des rainures voisines :**
> le **cadre** de chaque cellule est **au potentiel de mesure** (→ broche touch) ; la **broche
> entre cellules** est **à la masse** (la vraie garde). Les inverser sur une cellule la rend
> muette, et le symptôme imite un défaut de contact plutôt qu'une erreur de câblage.

**Contact fil rond sur film plat = une ligne, pas une surface.** Remède géométrique : creuser la
rainure **moins profonde que le diamètre du fil**, pour que la broche dépasse de 0,1–0,2 mm. Le
film plaqué par-dessus est alors pressé contre le fil sur tout le pourtour. Cadre plus simple à
réaliser en **4 segments droits soudés aux angles** qu'en rectangle plié, fil de liaison soudé sur
un coin.

### Assemblage : pression par l'arrière (aucune fixation visible)

**Contrainte dominante : l'esthétique.** Une plaque de serrage vissée en face avant, avec des vis
entre les touches, est mécaniquement correcte et visuellement inacceptable sur un contrôleur.
→ La pression vient de **derrière**, la face avant reste une plaque continue sans perçage.

```
   doigt
 ─────────────────────────   face avant = plaque plexi CONTINUE, sans perçage
 ▓▓▓▓▓▓▓▓▓▓▓▓▓▓▓▓▓▓▓▓▓▓▓▓▓   (1,5–2 mm : la surface qu'on voit et qu'on touche)
 ░░░░░░░░░░░░░░░░░░░░░░░░░   film ITO, couche ITO tournée vers l'arrière
 ══╡                   ╞══   cadres en broches, dans les rainures du support
 ▓▓▓▓▓▓▓▓▓▓▓▓▓▓▓▓▓▓▓▓▓▓▓▓▓   mousse de repartition
 ═════════════════════════   plaque arriere, vissee EN PERIPHERIE, dans le boitier
```

- **Aucune fixation visible** : les vis passent au pourtour de la façade, à l'intérieur du boîtier.
- **Le PET n'est plus la surface de contact** — c'est le plexi. Le problème de rayure disparaît,
  et avec lui la raison d'être d'une plaque de serrage frontale.
- **La mousse répartit la pression** bien mieux que des vis ponctuelles (montage classique des
  claviers à membrane) et absorbe les tolérances d'un usinage à la main.
- **Les rainures Dremel vont dans le support arrière**, que personne ne voit : la précision
  d'usinage n'est plus un enjeu esthétique.

> **Conséquence : plus besoin de plexi épais sculpté.** Le bloc épais n'était nécessaire que
> lorsqu'il devait être structure **et** diélectrique mince. Ici la face avant est une simple
> plaque plate de 1,5–2 mm : **la poche fraisée à membrane régulière — le point le plus risqué du
> concept — disparaît**.

**Cadres visibles par transparence → impression en seconde surface.** Décor imprimé ou peint au
**dos** de la plaque avant : un bandeau opaque dessinant le contour de chaque touche, avec des
fenêtres claires pour la LED. Les broches et les bords du film se cachent derrière ce bandeau,
l'encre est protégée par le plexi lui-même, la face avant reste parfaitement lisse — c'est la
construction des façades d'appareils du commerce. Alternative assumée : laisser les cadres
visibles comme un liseré net autour de chaque touche (sur un clavier piano, une séparation
franche entre touches peut être un parti pris).

Mise en œuvre :

- **Fil dépassant de 0,1–0,2 mm**, pas plus : sous une plaque rigide la pression se concentre sur
  les lignes de fil (ce qu'on veut) sans tendre le film au point de le marquer.
- **Cyano aux angles des rainures seulement**, jamais dans la zone de contact — de la colle entre
  fil et ITO et le contact est mort.
- **Ne pas serrer fort** : au-delà du contact établi la pression n'apporte plus rien. Serrer en
  surveillant l'histogramme du scope : dès que le pic « broche nue » disparaît, c'est bon.
- **Centre des cellules libre** de colle et de vis : c'est le chemin de la LED.

> Alternative **permanente** pour la version finale : **adhésif optique transparent** (3M 468MP /
> OCA) laminant le film au dos de la plaque avant — c'est la construction des écrans de téléphone.
> La question de la pression disparaît pour le film ; il ne reste qu'à plaquer les broches contre
> l'ITO par la mousse arrière.
>
> À éviter : simple **ruban adhésif en périphérie**. Pression faible et inégale au niveau des
> fils = retour des décrochages.

**Trois mesures à tirer du coupon :**

1. **Écarts inégaux entre cellules** (p. ex. 2 / 5 / 10 mm) plutôt qu'uniformes → c'est le
   cross-talk qui fixera le **pas du clavier 27 touches**, donc la largeur de façade.
2. **Coût de la garde** : Δ avec la broche de masse connectée, puis débranchée. Elle capte des
   lignes de champ qui allaient au doigt et ajoute de la capacité à la ligne de base — l'A/B dit
   ce qu'elle coûte en sensibilité pour ce qu'elle rapporte en cross-talk.
3. **Budget d'épaisseur en façade** : empiler des chutes transparentes sur le coupon et relever le
   Δ à chaque épaisseur. La question n'est plus « est-ce que ça passe » (réglé, ×6,4) mais
   « combien d'épaisseur puis-je m'offrir avant de descendre sous SNR 10 ». Nécessaire parce que
   **le PET exposé se raiera** sous les doigts — un clavier, ça se joue.

**Protection ESD.** Avec 0,125 mm de diélectrique au lieu de 1,5 mm de plexi, une décharge
statique atteint bien plus facilement la broche. Le self-cap tolérant plusieurs kΩ en série, une
**résistance série de 1–10 kΩ par canal** ne coûte rien en signal → à porter au schéma KiCad.

## Points ouverts
- **Électrode** : **ITO/PET transparent pleine surface** (cf. section ci-dessus) ·
  ruban cuivre adhésif · feuille cuivre · peinture conductrice (Bare/MG) ?
- **Membrane** : épaisseur mini fiable au Dremel (1 mm risqué à la main ?).
- **Fixation** de la carte électronique au dos + passage des fils.
- Garde de masse / blindage entre cellules (éviter le cross-talk) — faisable en cuivre aussi.

---

# Technique d'électrode — arrêtée le 2026-08-21

Aboutissement de la séance : le montage tient en **une feuille et un bloc**.

## Le principe : graver le motif, ne pas découper le support

**Une seule feuille d'ITO/PET continue** couvre tout le clavier. Pour séparer deux électrodes,
il suffit d'**interrompre la couche d'ITO** (~100 nm) ; le PET reste entier. C'est la
construction des dalles tactiles du commerce : un substrat, un conducteur **gravé en motif**.

**Les électrodes sont des îlots, la garde est la mer.** On ne grave que des **traits fins** ;
tout ce qui reste autour forme la garde, avec **une seule liaison à la masse**. Minimum de
gravure, couverture de garde maximale entre cellules.

> ⚠️ **Contrepartie** : une garde étendue près des électrodes **charge le capteur** (capacité
> permanente vers la masse) et dégrade le rapport signal/ligne de base. Le paramètre d'arbitrage
> est la **largeur du trait de séparation** — étroit protège mais charge, large fait l'inverse.
> Ordre de grandeur courant : ~1 mm. **À mesurer sur le banc** (deux cellules, deux écarts).

## Orientation : PET vers le doigt

Le film est posé **PET vers le doigt, ITO vers le plexi**. Le PET (0,125 mm) devient la
protection : la couche conductrice n'est jamais touchée. Trois bénéfices d'un seul geste —
protection contre l'**abrasion** (une rayure coupe le conducteur), barrière **ESD** de plusieurs
kV vers la broche de l'ESP32, et surface qui se **nettoie**.

✅ **Aftertouch vérifié à travers le PET** : la marge reste suffisante (essai 2026-08-21).

## Séparation entre touches : trait de scie + lamelle noire

Trait de scie **traversant** entre blanches, bloc uni dans la partie cachée (peigne).
Mesuré : trait nu → « un tout petit peu » de lumière passe ; **trait + lamelle noire → rien**.
Détails et théorie : `ETUDE_DIFFUSION_LED.md`.

**Placer les traits de gravure de l'ITO juste au-dessus des coupes de scie.** Un motif d'ITO
gravé reste légèrement visible en lumière rasante (la réflectance change là où le conducteur a
disparu — d'où les couches d'adaptation d'indice des dalles du commerce). En faisant coïncider
les deux, le problème disparaît sans traitement.

## Comment graver

| voie | procédé | note |
|---|---|---|
| **Masque + chimie** *(recommandée)* | masque adhésif découpé à la CNC, puis **HCl dilué ~5 %, ~1 min** à température ambiante. Variante au pinceau : pâte **zinc + HCl** | le PET n'est pas attaqué |
| Ablation laser | tracé direct des lignes, sans masque ni chimie | développée précisément pour éviter la photolitho |

Contrôle : **ohmmètre** de part et d'autre d'un trait. Infini = gravé ; quelques kΩ = pont restant.
Sécurité : ventilation, gants, lunettes ; zinc + HCl dégage de l'**hydrogène**.
Réfs : [Tech Briefs](https://www.techbriefs.com/component/content/article/2552-ksc-12828) ·
[laser scribing ITO, ScienceDirect](https://www.sciencedirect.com/science/article/abs/pii/S016943321001158X)

### Précision requise — ce n'est pas là qu'on croit

- **XY : ±0,1 mm largement suffisant.** Les traits font ~1 mm, le plus petit détail (largeur
  d'une noire) fait ~8 mm.
- 🔴 **Z : ne pas piloter en profondeur.** Retirer 100 nm d'ITO sans entamer 125 000 nm de PET,
  c'est un rapport de 1 à 1250 — ni le film ni la plaque ne sont plats à ce niveau. Il faut une
  **pression contrôlée** (outil sur ressort, principe du couteau traînant), pas une cote de
  profondeur. **La voie masque + chimie est totalement insensible au Z** : c'est ce qui la rend
  recommandable.
- 🔴 **La vraie difficulté est le REPÉRAGE.** Les traits gravés doivent tomber au-dessus des
  coupes de scie : il faut faire coïncider film et bloc à mieux de **0,5 mm sur 300 mm**. Ce
  n'est pas une affaire de précision machine mais de **références de montage** — perçages de
  repérage communs, ou usinage des deux pièces dans le même bridage. C'est classiquement là que
  ce type d'assemblage échoue : chaque pièce est juste, et elles ne se superposent pas.

## Tenue mécanique du film : pincé, pas collé

**Le pourtour du film est capturé sous les caches** avant et arrière. Un bord pincé ne se décolle
pas — il n'y a plus d'arête où un ongle s'insère, et c'est toujours par là que ça commence.
L'adhésif ne fait que positionner.

**Bénéfice décisif : le film devient un consommable.** Deux vis, on change la pièce d'usure. Sur
un instrument joué des années, ça vaut mieux que de chercher la colle parfaite.

**La colle nuit par deux mécanismes distincts :**

1. **Capillarité dans les fentes** — aspirée dans le trait de scie, elle en fait un milieu
   d'indice voisin du PMMA et **pontifie optiquement** les deux touches. → **la lamelle noire
   bloque aussi la colle** : deux fonctions pour une pièce.
2. **Adaptation d'indice sur la face avant** — une colle acrylique (~1,4–1,5) supprime la
   réflexion totale et la lumière ressort **partout** au lieu de sortir aux points de gravure.
   → **ne coller qu'au pourtour et dans la zone cachée**, laisser un film d'air sur les zones
   tactiles.

> **Dilatation différentielle** : PMMA ~70 × 10⁻⁶/K contre nettement moins pour le PET. Sur
> 300 mm et 20 K, ~0,2 mm de différentiel. Un film rigidement collé sur tout son pourtour
> **gondole** — cloques au milieu, là où le doigt se pose. Capture mécanique + adhésif **souple**
> (mousse acrylique) pour absorber le glissement.
>
> Le **PET non traité est une surface à basse énergie** : face arrière traitée corona ou primaire,
> sinon la tenue est de quelques mois.
>
> Usure : seule vraie parade, le **PET traité anti-rayure**.

## Résistance des liaisons

Chaque électrode rejoint son contact dans la zone cachée, **en ITO**, donc résistif. Une piste de
2 mm × 100 mm = 50 carrés ≈ **5 kΩ** à 100 Ω/□. Le self-cap l'encaisse (il tolère plusieurs kΩ),
mais c'est le haut de la fourchette → **pistes aussi larges que la place le permet**, contacts
**regroupés au plus près**.

Rappel utile : une électrode de blanche alimentée par un seul bout ne fait que ~2,8 carrés, soit
**~280 Ω**. **Un seul contact par touche suffit** — pas de cadre périphérique.

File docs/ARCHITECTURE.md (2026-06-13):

# Architecture matérielle — NiDMI Seq

> ⚠️ **LEGACY / divergente.** Ce doc décrit l'**ancienne** archi (boutons mécaniques
> PB86 lus en MCP23017, 4 encodeurs, 5 transport, pads 4×4 silicone), antérieure à la
> refonte ergo 2026-06. Le **design actif** = clavier piano **capacitif** + ruban +
> 5 encodeurs + 8 PB86 + écran 4,0″ : voir [`VARIANTE_CAPACITIVE.md`](VARIANTE_CAPACITIVE.md)
> (concept) et [`BOM.md`](BOM.md) (specs figées). Garder ce doc pour l'historique et la
> section Écran (à jour). Ne pas s'y fier pour la surface de contrôle.

> Document vivant. Décisions actées avec l'utilisateur ; certaines restent à
> trancher (marquées **À FIGER**).

## Schéma bloc

```
                              ┌─────────────────────────┐
                              │      ESP32-S3            │
                              │  (dual-core, USB natif)  │
                              └─────────────────────────┘
        I2C (2 fils) ────────────┤ SDA/SCL          SPI ├──── TFT 4,0″ 480×320 ILI9488 (SCK,MOSI,CS,DC,RST,BL)
             │                   │                       │
    ┌────────┼────────┐          │              UART TX ├──── MIDI OUT (TRS-A ou DIN5)
    │        │        │          │              UART RX ├──── MIDI IN (via opto 6N138/H11L1)
 MCP23017 MCP23017 MCP23017      │                       │
  (0x20)   (0x21)   (0x22)       │           1 GPIO data├──── SK6812 RGB (1 bus, ≥16 → 27+)
   37 entrées (sur 48)           │                       │
    │        │        │          │     8 GPIO (PCNT A/B) ├──── 4 encodeurs (quadrature)
 28 touches  5 transport         │                       │
 (16+11+⇧)   4 push-encodeurs    └── INT ────────────────┘  (réveil sur appui)
```

## Décisions actées

### Module : ESP32-S3-WROOM-1-N16R8 (16 Mo flash + 8 Mo PSRAM octale)
- **La PSRAM additionnelle est non-négociable** (banque de patterns, cahier §11.2) :
  s'en passer risquerait de bloquer le projet. On garde donc les **8 Mo**.
- 8 Mo ⇒ **PSRAM octale (R8)** ⇒ réserve en interne **GPIO 26-37** (flash + PSRAM).
- **Sans conséquence ici** : les 37 boutons sont sur I2C, donc seuls ~20 GPIO sont
  requis pour ~25 exploitables sur le N16R8 → marge confortable (voir budget GPIO).

### Budget GPIO ESP32-S3 (N16R8, pins 26-37 réservés exclus)
| Fonction | GPIO | Nb |
|---|---|----|
| I2C (3× MCP23017) | SDA, SCL | 2  |
| TFT SPI | SCK, MOSI, CS, DC, RST, BL | 6  |
| MIDI UART | TX, RX | 2  |
| SK6812 data | 1 ligne | 1  |
| Encodeurs quadrature A/B  | 4× (A+B) | 8  |
| MCP INT (chaîné) | 1 ligne | 1  |
| **Total requis** | | **20** |
| USB-MIDI | D-/D+ (19,20 natifs) | (2)|
| **Exploitables N16R8** | hors 0/3/45/46 (strap), 19/20 (USB), 43/44 (UART0) | **~25** |

Affectation provisoire (à figer avec le contrôleur TFT exact) — éviter strapping
(0,3,45,46), flash/PSRAM (26-37), USB (19,20) :
- I2C : SDA=8, SCL=9 · TFT(FSPI) : SCK=12, MOSI=11, CS=10, DC=13, RST=14, BL=21
- MIDI : TX=17, RX=18 · SK6812 : 47 · INT MCP : 38
- Encodeurs A/B : 1,2,4,5,6,7,15,16 · USB-MIDI : 19,20

### Lecture des touches : expandeurs I2C MCP23017 (×3)
- Bus I2C = 2 fils ; jusqu'à 8 MCP23017 (adr. 0x20→0x27 via leurs broches A0/A1/A2).
- **3× MCP23017 = 48 entrées** pour 37 boutons → marge confortable (0x20/0x21/0x22).
- **Pull-ups internes** → boutons câblés `pin → bouton → GND`, zéro composant externe.
- Broche **INT** → l'ESP32 ne fait pas de polling, réveil sur changement d'état.
- **NKRO natif** (cf. §10.6 cahier) : 1 broche dédiée par bouton → lecture du port
  complet, **16 touches simultanées sans ghosting, sans diodes**. Mieux que la
  « matrice de scan » évoquée au cahier (qui imposerait des diodes anti-ghosting).

### Touches : boutons-poussoirs PB86, on/off (pas de vélocité au doigt)
- **PB86** : poussoir rond panel-mount (~12 mm, écrou), momentané. Stock dispo en
  **A0 (sans LED)**, **A1 (LED mono)**, **A2 (LED bi-couleur)**.
- Câblage MCP23017 `pin → bouton → GND` (pull-up interne) ; pas d'ADC, pas de matrice.
- `StepData.velocity` reste **éditable à l'encodeur** (réglage par pas), pas joué.
  → à refléter dans le cahier des charges du VST.

#### Affectation variante PB86 → rôle (piloté par cahier §10.3–10.5)
- **16 blanches (pas)** → **A0 (sans LED)** + SK6812 RGB séparées. Le §10.5 **exige**
  du RGB adressable (4 couches × couleur + pas actif + sub) ; les LED intégrées
  A1/A2 ne savent pas le faire. Mettre A1/A2 ici = gâchis.
- **11 noires + Shift + 5 transport** → état à peu de valeurs. **Reco : A0 + SK6812**
  partout (1 seul bus, firmware uniforme). Option : A1/A2 ici pour valoriser le
  stock, mais ajoute un 2ᵉ chemin de pilotage LED (driver courant constant) → +complexité PCB.
- A1/A2 conservés en **réserve** / variante simplifiée du produit.

### Budget entrées (cf. §11.3 cahier)
| Bloc | Lignes |
|---|---|
| 16 blanches + 11 noires | 27 |
| Shift | 1 |
| 5 transport (Play/Stop/Rec/Vue/Export) | 5 |
| 4 push-encodeurs | 4 |
| **Total boutons** | **37** |
| 3× MCP23017 | 48 |
| **Libres** | **11** |
- Push-encodeurs sur MCP (pas critique en vitesse) → libère des GPIO ESP32.
- Quadrature A/B des encodeurs **pas** sur MCP (voir Encodeurs).

### Encodeurs — quadrature sur GPIO ESP32-S3 (PCNT), push sur MCP
- Quadrature **A/B = 8 GPIO directs** lus par le périphérique **PCNT** (comptage
  matériel, zéro perte de pas même en rotation rapide). Ne pas mettre A/B sur I2C.
- **Push (4)** → déportés sur MCP23017 (pas critique) → économise 4 GPIO ESP32.

### Pads « pas » (16 blanches) — FIGÉ : galette silicone + SK6812 CMS
Décision : **Famille 1** (pad silicone translucide + LED RGB adressable sous le PCB),
le geste « groovebox » (MPC/Push/Launchpad). Remplit le §10.5 (couleur par pas).
- **Bouton = galette silicone élastomère 4×4** (Adafruit #1611 ; pack 2 #4021 ;
  équiv. eMagTech). 16 pas = 1 galette. Boutons 10 mm, course 3 mm, silencieux.
  **0 soudure** : se pose sur le PCB, contact par pastilles conductrices → vu comme
  un bouton NO normal → câblé sur MCP comme les autres.
- **LED = SK6812 CMS** (obligatoire : la galette loge une LED plate/3 mm, la 5 mm THT
  ne rentre pas ; l'adressable n'existe pas proprement en 3 mm THT). Reste sur le
  **bus 1-fil** SK6812 du §10.5.
- **Géométrie figée par la galette** : 4×4, ~60×60 mm, ~11,5 mm de haut.
- PCB : dessiner les **pastilles de contact interdigitées** (layout documenté Trellis)
  + 1 SK6812 centrée par cellule.

#### Assemblage — À FIGER (différé : décider avec PCB/échantillon en main)
- **1a (reco)** : PCB custom + 16 SK6812 **posées en PCBA** (~20 € fixe) → section pad
  quasi sans soudure manuelle (tu poses juste la galette). S'intègre à l'archi finale.
- **1b (proto rapide)** : module **NeoTrellis #3954** (16 SK6812 pré-soudées, I2C,
  même bus) — 0 soudure, ~40 €, mais ajoute une puce *seesaw* et diverge de l'archi finale.
- **1a-main** : souder les 16 SK6812 soi-même (fer fin+flux / air chaud) — économise
  le PCBA, plus difficile pour petites mains.
- À FIGER aussi : 5V/3.3V (level-shifter data si 5V), budget courant (SK6812 ≈ 50 mA
  à blanc plein → 16 pas ≈ 0,8 A crête ; dimensionner l'alim 5V).

### Écran — FIGÉ : TFT 4,0″ 480×320, ILI9488, SPI, non tactile
- **Source : cahier VST §10.1** — l'écran est **le hub d'édition** (Vues PATTERN
  multi-row, PIANO ROLL tuplet-aware, HARMONIE, AUTO, GLOBAL, SONG).
- **Résolution 480×320 (3:2), contrôleur ILI9488, bus SPI** (~6 fils : SCK, MOSI,
  CS, DC, RST, BL) — module simple, dispo partout, **piloté directement par le
  cerveau** (pas de puce écran dédiée). Refresh fluide en *partial refresh*.
- **Diagonale 4,0″** (zone active ~85×56 mm, paysage) : 480×320 **dépasse** la cible
  320×240 du cahier ; le 4,0″ donne des pixels plus gros que le 3,5″ → plus lisible.
- **Non tactile** : les modules ILI9488 embarquent souvent une couche tactile
  (XPT2046 résistif) — **non utilisée** (le tactile est sur les touches), broches NC.
- Note perf : ILI9488 en SPI = 18 bpp (pas de RGB565 4-fils) → un peu plus lent que
  **ST7796** ; OK en partial refresh. ST7796 480×320 = alternative plus rapide si dispo.

### MIDI
- OUT : UART TX + driver de ligne.
- IN : **opto-coupleur obligatoire** (6N138 ou H11L1) pour isolation (norme MIDI).
- À FIGER : connecteurs DIN5 classiques ou TRS (type A) ?

### Alimentation
- USB-C 5V → régulateur 3.3V pour ESP32 + logique.
- TFT / WS2812 possiblement 5V → vérifier datasheets.

## BOM à figer avant le schéma
- [x] Module : **ESP32-S3-WROOM-1-N16R8** (16 Mo flash + 8 Mo PSRAM octale). PSRAM
      non-négociable ; GPIO 26-37 réservés mais sans impact (budget GPIO OK).
- [x] **Écran TFT 4,0″ 480×320, ILI9488, bus SPI, non tactile** (cf. cahier VST §10.1).
      Module commerce simple (~6 fils SPI), tactile XPT2046 éventuel non utilisé.
      ST7796 = alternative plus rapide si dispo.
- [ ] Encodeurs : modèle, détente, push intégré.
- [ ] PB86 : confirmer A0 pour les 27 touches ; statuer A0-vs-A1/A2 sur transport/Shift.
- [ ] Connecteurs MIDI : **TRS type A** (cahier penche TRS) vs DIN5.
- [x] Pads pas : **galette silicone 4×4 (Adafruit #1611) + SK6812 CMS** (Famille 1).
      À FIGER : assemblage (1a PCBA / 1b NeoTrellis / 1a-main), réf. SK6812 exacte,
      5V/3.3V, level-shifter data, budget courant alim 5V.
- Note : tact 12×12 THT + cap translucide reste pertinent pour les **11 noires** (fonctions).

## Flux de travail KiCad
1. Figer la BOM (ci-dessus).
2. Claude génère `.kicad_pro` + `.kicad_sch` (schéma fonctionnel).
3. Utilisateur ouvre KiCad → lance **ERC** → renvoie les erreurs → itération.
4. Placement/routage : scripts `pcbnew` pour les grilles régulières (touches, LEDs) ;
   ajustement visuel + **DRC** côté utilisateur.

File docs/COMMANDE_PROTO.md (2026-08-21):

# Ce qu'il faut pour le prototype du clavier

> Liste établie le **2026-08-21**, après la séance de conception qui a arrêté
> l'architecture (plaque acrylique continue · un seul ITO · trois éclairages
> indépendants dont deux par en dessous). Détail et justifications :
> [`../mechanical/README.md`](../mechanical/README.md) et [`BOM.md`](BOM.md).
>
> **C'est un prototype** : partout où deux solutions existent, la liste retient
> celle qui se fait à l'atelier, et signale en encadré la voie « série » à viser
> ensuite. Colonnes Qté / Fournisseur / Prix à remplir au moment de commander.

## 0. Déjà en stock — ne pas recommander

| item | état |
|---|---|
| Acrylique coulé **10 mm** | le bloc guide de lumière, déjà en main |
| **Film ITO sur PET** (Adafruit #1309) | reçu, déjà testé au banc |
| **78 LED CMS orange** | récupération — suffisent à tous les essais optiques |
| **ESP32-S3-WROOM-1-N16R8** + platine d'essai | banc capacitif opérationnel |
| **CrowPanel Advance 7.0-HMI** | commandé |

## 1. Acrylique

| ✓ | Item | Pour quoi | Prio | Qté | Fournisseur | Prix |
|---|---|---|---|---|---|---|
| ☐ | Acrylique **coulé transparent 1 mm** | **La plaque continue** — surface touchée. C'est la pièce neuve la plus importante. | **Essentiel** | | | |
| ☐ | Acrylique **coulé transparent 2 mm** | Variante d'épaisseur, si l'essai d'aftertouch dit que 1 mm est trop fin | **Essentiel** | | | |
| ☐ | Acrylique **teinté sombre 1 mm** (chute) | Essai : les noires par la teinte plutôt que par l'impression | Recommandé | | | |
| ☐ | Acrylique **satiné / dépoli 1 mm** (chute) | Essai du satinage local sous la bande du ruban | Recommandé | | | |

> ⚠️ **Coulé, pas extrudé.** L'extrudé fond et bavoche à l'usinage, le coulé se
> fraise proprement et se polit. Pour la plaque, c'est ce qui décide de l'aspect.

## 2. Contact de l'électrode

| ✓ | Item | Réf | Prio | Qté | Fournisseur | Prix |
|---|---|---|---|---|---|---|
| ☐ | **Encre / stylo argent conducteur** | MG Chemicals **842AR** ou **842AR-P** | **Essentiel** | | | |
| ☐ | **Ruban Z-axis** (conducteur dans l'épaisseur seulement) | 3M **9703** | **Essentiel** | | | |
| ☐ | **Époxy argent** (reprise, réparation) | MG Chemicals **8331S** | Recommandé | | | |
| ☐ | **Connecteur élastomère « zébra »** | pas de conduction 0,1–0,5 mm | Optionnel | | | |
| ☐ | **Ruban cuivre à adhésif _conducteur_** | 3M **1181** | Optionnel | | | |
| ☐ | **Vernis de tropicalisation** acrylique | encapsulation de la jonction argent | Recommandé | | | |

> **Jamais de soudure sur l'ITO**, et jamais de contact direct dessus : on passe
> par l'argent. Le ruban Z-axis colle toutes les plages d'un coup sans les
> court-circuiter — c'est la solution proto qui demande le moins d'outillage.
>
> Voie **série** : queue de film sérigraphiée au pas d'un connecteur à charnière
> (FFC/ZIF), rigidifiée par un renfort. Rien à acheter maintenant.

## 3. Éclairage

| ✓ | Item | Pour quoi | Prio | Qté | Fournisseur | Prix |
|---|---|---|---|---|---|---|
| ☐ | **SK6812 3535** RGB | Blanches (tranche avant) + noires (par en dessous) | **Essentiel** | ~30 | | |
| ☐ | **74AHCT125** | Adaptation 3,3 → 5 V du bus 1-fil | **Essentiel** | | | |
| ☐ | Bande SK6812 **60 LED/m** | Ruban — le pas grossier est le bon si le halo est large | Recommandé | | | |
| ☐ | Bandes 96 et 144 LED/m (chutes) | Comparer le pas au halo mesuré | Optionnel | | | |

> Le pas des LED du ruban ne se choisit pas au catalogue : **pas ≤ largeur du
> halo**, à relever au banc sur le bloc de 10 mm.

## 4. Serrage — la mousse est le ressort

| ✓ | Item | Note | Prio | Qté | Fournisseur | Prix |
|---|---|---|---|---|---|---|
| ☐ | **Mousse polyuréthane microcellulaire 3 mm** (type Poron) ou silicone | **Faible déformation rémanente obligatoire** | **Essentiel** | | | |
| ☐ | Visserie **M3** + écrous | dans des poches usinées, jamais taraudé dans l'acrylique | Essentiel | | | |
| ☐ | Entretoises métal | fixer une hauteur de pile déterministe | Recommandé | | | |

> De la mousse d'emballage ordinaire garde l'empreinte en quelques mois : la
> pression tombe et les contacts deviennent erratiques sans qu'on comprenne pourquoi.

## 5. Cartes

| ✓ | Item | Note | Prio | Qté | Fournisseur | Prix |
|---|---|---|---|---|---|---|
| ☐ | PCB **carte horizontale sous le bloc** | 294,8 × 56 mm — LED des noires **et** du ruban ; **posée sur le socle**, dans la **découpe de la mousse** | **Essentiel** | 1 | | |
| ☐ | PCB **tranche avant** | 294,8 × 8 mm, verticale — 16 LED, injection dans les blanches | **Essentiel** | 1 | | |
| ☐ | PCB **latéral** (double face) | **71,5 × 131,9 mm** — 4 PB86 + 3 EC11 devant, ESP32-S3 au dos, connecteurs en bord de carte | **Essentiel** | 2 | | |
| ☐ | Finition **or chimique (ENIG)**, ép. 0,6–0,8 mm | plat et non oxydable — indispensable pour un contact par pression | **Essentiel** | | | |
| ☐ | Connecteur **FFC/ZIF** | si la queue de film est retenue | Optionnel | | | |

## 6. Banc de mesure — la question qui verrouille tout

| ✓ | Item | Pour quoi | Prio |
|---|---|---|---|
| ☐ | **Chutes de PET / feuilles minces** à empiler | 🔴 **Balayage de l'aftertouch en fonction de l'épaisseur** : 0,25 · 0,5 · 1 · 2 mm. Mesuré : 0,125 mm passe, 10 mm ne passe pas. L'intervalle décide de l'épaisseur de la plaque. | **Essentiel** |
| ☐ | Jeu de **résistances série** (470 Ω → 22 kΩ) | Mesurer le vrai plafond de résistance d'un canal tactile, au lieu du 470 Ω–2 kΩ du BOM qui est une valeur de protection | Recommandé |

## 7. Usinage et consommables

| ✓ | Item | Note | Prio |
|---|---|---|---|
| ☐ | Fraises CNC pour acrylique (monodent) | plaque, relief des noires, poches borgnes | **Essentiel** |
| ☐ | Lame de scie fine | traits de scie entre blanches, arrêtés à 20 mm | Essentiel |
| ☐ | Fraise à graver / pointe Dremel | trame d'extraction au dos du bloc | Essentiel |
| ☐ | Film adhésif sombre | fond absorbant, avec fenêtre sous chaque noire | Essentiel |
| ☐ | Abrasifs fins + pâte à polir | chants optiques | Recommandé |

---

## Ordre d'attaque conseillé

1. **L'essai d'aftertouch** — il ne coûte rien et il décide de l'épaisseur de la plaque.
2. **La largeur du halo** d'une LED sous 10 mm de bloc — elle fixe le pas des LED du ruban.
3. Une **cellule complète** : plaque + film + bloc + LED dessous, pour mesurer le
   cross-talk, la dérive et la latence.

**Total estimé :** _(à remplir)_

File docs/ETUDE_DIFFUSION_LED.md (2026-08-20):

# Étude — diffusion / diffraction de la lumière (touches + boutons RGB)

> But : trouver l'empilement qui donne une **cellule qui glow de façon homogène**
> (pas de point chaud, pas de bavure sur la voisine) à travers le plexi, tout en
> gardant la **sensibilité capacitive**. Étude empirique sur échantillons.
>
> Vocabulaire : **diffusion** = étaler la lumière (glow homogène, le besoin).
> **Diffraction** = réseau qui sépare les couleurs (effet arc-en-ciel, optionnel/déco).

## Variables à tester

| Variable | Valeurs à essayer |
|---|---|
| **Matière overlay** | acrylique transparent · acrylique **dépoli/sablé** · acrylique **opale/diffusant** |
| **Film ajouté** | aucun · film **diffuseur** (feuille LCD) · film **diffraction** (réseau, effet déco) |
| **Épaisseur plexi** | 1,5 · 2 · 3 mm |
| **Entrefer LED→plexi** | 0 (collé) · 2 · 3 · 5 mm |
| **Cloison de cellule** | sans · avec paroi opaque (puit de lumière, anti-bavure) |
| **Type LED** | SK6812 **3535** (front-fire) · **MINI-E** (à travers découpe PCB) |
| **Électrode au-dessus de la LED** | anneau (trou central) · hachure · fenêtre |

## Ce qu'on observe / mesure
- **Homogénéité** : point chaud central vs glow uniforme sur toute la cellule.
- **Bavure** : la lumière déborde-t-elle sur la cellule voisine ? (→ cloison).
- **Mélange RGB** : le blanc (R+G+B) est-il uniforme ou irisé en bord ?
- **Luminosité** : perte due au diffuseur (plus c'est diffus, plus ça perd).
- **Sensibilité capacitive** : l'entrefer qui aide la diffusion **dégrade** le tactile
  → trouver le compromis (entrefer mini + diffuseur, ou pad collé + poche LED).

## Compromis clé à arbitrer
- **Diffusion veut de la distance** (entrefer, plexi épais, diffuseur) ;
- **Capacitif veut la proximité** (pad près du doigt, peu d'air).
- → tester les deux stacks : **(A) pad collé au plexi + LED en poche** (capacitif fort,
  diffusion via plexi dépoli) vs **(B) entrefer 2-3 mm uniforme** (diffusion facile,
  capacitif à compenser par pads plus grands + tuning seuil).

## Échantillons à se procurer
- Chutes acrylique : transparent, dépoli, opale (2 mm prioritaire).
- 1 feuille **film diffuseur** (récup écran LCD HS) ; option : 1 **film diffraction**.
- 2-3 **SK6812** (3535 + MINI-E) sur une mini-carte ou breakout pour piloter le RGB.
- (Pilotage test : un ESP32 + lib NeoPixel/FastLED suffit.)

## Décisions que cette étude débloque
- SK6812 **3535 vs MINI-E** (BOM §2, décision #6).
- Stack de cellule **A vs B** (entrefer) → impacte `spacer_t` et la sensibilité.
- Finition plexi (dépoli/opale) + film éventuel.
- Géométrie électrode (anneau/hachure/fenêtre) → routage PCB des touches.

## Source de test : LED bleues de récupération (2026-08-19)

Lot de LED CMS 2 pattes identifiées au banc `firmware/test_led` : **bleues monochromes**
(seuil ~3 V), encoche = cathode. Identification faite avec le mode auto (LED entre deux GPIO,
polarité alternée, un éclair long vs trois clignotements pour lire le sens).

**Lot inventorié (2026-08-19)** : **76 oranges, 7 vertes, 3 bleues** (86 au total).
Provenances probablement différentes → ne pas généraliser une observation d'une couleur à l'autre.

**Méthode imposée par la répartition** : mettre au point la géométrie de poche avec les
**oranges** (abondantes, sacrifiables au fil des essais Dremel), puis **valider la géométrie
retenue avec une bleue** — seulement 3 en stock, à ne pas gaspiller en tâtonnements.

**Vertes : famille à déterminer.** Vert traditionnel (seuil ~2,1 V) → brille comme les oranges.
Vert **InGaN** (~3,2 V) → se comporte comme une bleue, quasi éteint en 3,3 V, rail 5 V obligatoire.
La sonde `m` de `firmware/test_led` tranche en une mesure.

> **76 oranges > 27 touches** : de quoi monter une **maquette de façade complète illuminée** sans
> rien acheter. Le choix RGB étant acté (BOM §2), elle ne sert plus à trancher monochrome/RGB mais
> à répondre à une question indépendante de la couleur : **la lumière d'une cellule déborde-t-elle
> sur sa voisine ?**
>
> ⚠️ **Débordement lumineux et cross-talk capacitif contraignent tous deux le pas du clavier.**
> Les mesurer sur le **même coupon**, avec les mêmes écarts entre cellules (2 / 5 / 10 mm) — cf.
> `ESSAI_ITO_ESP32.md`. Fixer l'entraxe sur le seul capacitif exposerait à découvrir ensuite que
> les halos se chevauchent.

**Repère d'anode (à revalider par couleur)** : inscription sur le flanc du boîtier, lue **cellule
vers le haut → anode à gauche**. Vérifié au banc en mode sens. Comme le lot est mélangé, revalider
sur un échantillon de chaque couleur avant de s'y fier pour un montage en série. Vérifier aussi
que l'encoche et l'inscription latérale désignent bien le même côté.

**Pour l'étude, utiliser les BLEUES** : c'est le cas le plus défavorable (seuil le plus haut donc
courant le plus faible à montage donné, longueur d'onde la plus courte donc diffusion la plus
marquée). Une géométrie de poche qui donne un halo homogène en bleu le donnera dans toutes les
couleurs ; valider sur une rouge bien lumineuse donnerait un résultat trop optimiste. Garder une
rouge pour comparer dans la **même** poche : l'écart dira si la teinte influe sur l'homogénéité
perçue, utile avant de figer la géométrie pour du SK6812 RGB.

**À alimenter en 5 V + 100 Ω (≈ 20 mA) pour tout essai de diffusion.** En 3,3 V il ne reste que
0,1–0,3 V aux bornes de la résistance → ~2 mA, un dixième du nominal : assez pour identifier la
LED, pas pour juger d'un halo. Corollaire : **une LED bleue ou blanche ne se pilote pas depuis
une broche d'ESP32** (3,3 V ≈ son seuil) — il lui faut le rail 5 V, que le BOM prévoit déjà pour
les SK6812.

> Ces bleues servent à étudier la **géométrie** (profondeur de poche, dépoli, homogénéité du
> halo), pas le rendu final : le BOM prévoit du SK6812 RGB. Conclure sur les formes et les
> distances, pas sur l'intensité ni la teinte perçues — le bleu diffuse un peu plus que le rouge
> à géométrie égale.

## Résultat : guide de lumière à éclairage latéral (2026-08-20)

**Principe validé au proto.** LED sur la **tranche** ; la lumière se propage dans le plexi par
réflexion totale interne et ne sort qu'où la surface est perturbée. La **gravure Dremel** joue le
rôle de structure d'extraction — même principe que les rétroéclairages de dalles LCD.

**Gravure au DOS, pas en face avant** (comparé au proto) : la face avant reste lisse, donc la
réflexion totale y est préservée et la lumière rebondit jusqu'à trouver la gravure ; on regarde un
halo diffus **à travers** de l'acrylique poli, plus net qu'une surface dépolie côté spectateur.
Bénéfices annexes : façade lisse (pas de rainures à crasse ni à rayures), et **la gravure masque
l'électrode** → l'impression en seconde surface envisagée pour cacher le bus bar devient inutile.

**Cross-talk optique : faible.** Une gravure s'allume nettement en face de sa LED et « presque
pas » à côté. C'est la réponse à l'une des deux contraintes qui fixaient le pas du clavier
(l'autre étant le cross-talk capacitif, cf. `ESSAI_ITO_ESP32.md`).

**Deux leviers, qui s'opposent** : la *densité et la profondeur de gravure* règlent la quantité de
lumière extraite (plus creusé = plus lumineux, mais diffuse aussi vers les voisines) ; la
*distance LED↔gravure et l'angle du faisceau* règlent la sélectivité. Chercher le point où la
touche est lisible sans que sa voisine s'éclaire.

**Renfort possible** : une **rainure entre cellules** fait barrière optique à la lumière rasante.
Elle tombe au même endroit que la broche de garde à la masse et les vis de fixation — trois
fonctions dans une zone déjà perdue pour l'optique comme pour le capacitif.

### ⚠️ Tension avec le capacitif — à mesurer

Le guide ne fonctionne que tant que ses faces sont **au contact de l'air**. Plaquer le film ITO
contre la face arrière met le système en **réflexion totale frustrée** : l'indice du PET (~1,57)
est proche de celui de l'acrylique (~1,49), donc la lumière sort **partout où le film touche**, et
plus seulement au niveau de la gravure → perte de la sélectivité. Le capacitif, lui, veut
l'électrode au plus près. Les deux exigences s'opposent.

**La marge permet de trancher en faveur de l'optique** : ×5,3 dans le cas défavorable, 840× le
seuil. Une lame d'air de quelques dixièmes de mm ne coûte qu'une fraction de cette marge.

**Mesure à faire** (banc `firmware/banc_cellules`) : relever le Δ **film plaqué** puis **film
légèrement décollé**, et vérifier à chaque fois si la gravure voisine s'allume. On obtient ce que
l'entrefer coûte en capacitif contre ce qu'il rapporte en sélectivité optique.

> Montage : **l'ITO se fissure sous contrainte** et une arête de gravure est un point dur. Ne pas
> presser le film contre la face gravée avec un appui ponctuel.

### Conséquence pour la décision BOM #6 (SK6812 3535 vs MINI-E)

Le critère change : il ne s'agit plus d'éclairer *depuis l'arrière* mais d'**injecter dans la
tranche** du guide. La question devient celle du couplage LED→tranche (position, angle, logement
fraisé), pas celle de l'émission frontale.

## Touches noires : teinte, puissance et pilotage (points ouverts)

Constat de départ : une plaque **teintée dans la masse** absorbe sur toute la longueur du guide
— à l'aller **et** sur le trajet d'extraction. Augmenter la puissance de la LED ne fait que
compenser une perte volontairement introduite, au prix du courant et de la chaleur.

**Piste privilégiée : guide en acrylique CLAIR + masque noir opaque** (peinture ou film au dos,
sauf au droit de la gravure). La touche est franchement noire à l'arrêt — plus qu'un teinté — le
guide garde son rendement, et à l'allumage c'est la **gravure qui s'illumine sur fond noir**. Sur
une touche de fonction, un symbole lumineux apparaissant dans le noir a plus d'allure qu'une
touche entièrement éclairée.

**Mesure préalable à toute commande** : la **transmission de la plaque candidate** (LED derrière,
comparée à du clair). Un facteur 5 de perte ne se rattrape avec aucune LED raisonnable.

**Monochrome pour les noires — à confronter à la VISION.** En vue PATTERN les noires portent les
**fonctions**. Sans couleur il reste luminosité et clignotement pour distinguer leurs états
(inactive / armée / active). Probablement suffisant pour 11 touches de fonction, contrairement aux
16 pas où l'on distingue accent, swing et durée — mais à vérifier dans la VISION avant de figer.

> ⚠️ **Conséquence BOM** : 11 LED blanches hors du bus SK6812 = **second circuit de pilotage**.
> Les MCP23017 déjà présents ne font que du tout-ou-rien (pas de PWM) → il faudrait un driver LED
> dédié sur l'I2C. **Avant d'accepter ce coût, tester si un SK6812 piloté en blanc plein suffit** :
> un seul bus, une seule référence, un seul firmware. Test de dix minutes.

## Essais de gravure — trois résultats (2026-08-20)

**Pollution lumineuse entre touches : acceptable.** Mesuré sur le proto. C'est ce qui autorise
le **bloc plein** (pas de découpe des touches) — cf. `CONCEPT_PLEXI_EPAIS.md` et
`mechanical/clavier_piano.scad` (`separation = "rainure"`).

**1. Gradient d'extraction — reliefs peu profonds près de la LED, de plus en plus prononcés en
s'éloignant.** C'est le principe fondamental du guide latéral : chaque motif prélève de la
lumière, donc le flux décroît le long du trajet. Une extraction **croissante avec la distance**
compense et donne une luminosité uniforme. Même principe que les motifs des rétroéclairages de
dalles LCD, clairsemés près des LED et denses à l'autre bout.

**2. Les points extraient mieux qu'une rainure continue.** Deux raisons : un point diffuse dans
toutes les directions là où une rainure renvoie surtout perpendiculairement ; et la **densité de
points** se module finement, ce qui est le levier naturel pour réaliser le gradient du point 1
— bien plus praticable au Dremel que de faire varier la profondeur de gravure.

**3. Un fond sombre optimise le rendu.** Il *réduit* le flux total émis mais absorbe le halo
parasite non extrait : les points ressortent nettement au lieu d'être noyés dans un fond diffus.
C'est un gain de **contraste**, pas de flux. Bénéfice secondaire : il absorbe aussi la lumière
rasante qui partirait vers les touches voisines — le fond sombre est donc en même temps un
traitement **anti-pollution lumineuse**. Confirme la piste « guide clair + masque noir »
envisagée pour les noires : elle vaut pour toute la façade.

### Numéro de pas gravé — idée à arbitrer

Graver le numéro de pas dans le motif d'extraction : le chiffre devient la légende **et**
l'émetteur, il s'allume au lieu d'être imprimé. Deux réserves :

- **Surface d'extraction faible** : un chiffre extrait bien moins qu'une plage de points, donc
  il sera plus sombre. Combiné au gradient, les chiffres éloignés de la LED devront être plus
  gras ou plus densément pointillés.
- ⚠️ **Une gravure reste visible éteinte** (elle diffuse en lumière ambiante). Or la VISION fait
  changer le sens des touches selon la vue : en ROLL les blanches sont un clavier chromatique,
  pas des pas. Un « 12 » gravé en permanence sur une touche qui joue parfois un ré est une
  légende fausse la moitié du temps. → soit chiffre discret assumé comme décor, soit légende
  reportée sur l'écran.

## Cloisons entre touches — mesuré (2026-08-21)

**Montage retenu : trait de scie traversant entre blanches**, bloc uni dans la partie cachée
(peigne), film transparent collé par-dessus. Le film **unifie la surface et bloque la poussière**
— une fente ouverte sur un instrument joué se remplit de crasse et devient inintéressable.

**Résultat d'essai :**

| cloison | lumière qui passe |
|---|---|
| trait de scie **nu** | « un tout petit peu » |
| trait de scie + **lamelle noire** | **rien du tout** |

**Deux prédictions théoriques corrigées par la mesure :**

1. **Une lame d'air nue ne réfléchit PAS la lumière guidée.** La normale d'une paroi verticale
   est horizontale, or la lumière guidée voyage presque à l'horizontale : elle frappe la cloison
   bien sous l'angle critique (42° pour PMMA/air) et la traverse. Seuls les rayons les plus
   inclinés (> 42° du plan de la plaque) sont réfléchis, et ils sont minoritaires.
   → **C'est l'ABSORPTION qui fait la barrière**, pas la réflexion totale. Elle agit à tous les
   angles.

2. **Mais l'atténuation nue est bien meilleure que la théorie ne le laissait craindre**, parce
   qu'un trait de scie n'est pas une paroi optique : c'est une surface **dépolie**. Elle diffuse
   au lieu de transmettre — ce qui traverse ne repart plus en faisceau guidé et s'éteint.
   → ⚠️ **La rugosité est un ATOUT ici, pas un défaut.** Corrige un conseil antérieur (« polir
   les parois de cloison ») qui ne valait que pour un mécanisme de réflexion totale inapplicable.
   **Aucun polissage n'est requis dans les fentes.**

> **La tranche d'INJECTION reste l'exception** : elle doit être nette. Une face dépolie à
> l'entrée disperse le flux avant qu'il n'entre dans le guide.

**Ce qui compte pour une cloison** : sa **profondeur** (elle doit occuper une bonne part de
l'épaisseur du guide), pas sa largeur — une interface n'a pas d'épaisseur. Fine et profonde,
jamais large et superficielle. Une découpe traversante est donc le cas idéal, et elle permet en
plus de **glisser une lamelle noire** dans le trait, ce qu'une rainure borgne ne permet pas.

> Point restant à vérifier : **le film continu collé par-dessus peut lui-même conduire un peu de
> lumière** d'une touche à l'autre. Au droit d'une fente il a de l'air dessus et dessous, donc il
> devient localement un mini-guide qui enjambe la coupure. Effet probablement faible (film très
> mince) mais à mesurer, pas à supposer.

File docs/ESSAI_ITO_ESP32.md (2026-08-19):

# Essai — électrode ITO derrière membrane plexi, mesurée à l'ESP32-S3

Valide la question n°1 de [`CONCEPT_PLEXI_EPAIS.md`](CONCEPT_PLEXI_EPAIS.md) :
**une électrode ITO pleine cellule, derrière 1–1,5 mm de plexi, donne-t-elle un
signal capacitif exploitable ?** Tant que ce point n'est pas mesuré, la géométrie
de cellule (donc le KiCad, donc l'usinage) reste en suspens.

Banc : [`firmware/test_touch_ito`](../firmware/test_touch_ito) +
[`scripts/touch_log.py`](../scripts/touch_log.py).

## Matériel

- **ESP32-S3-WROOM-1 N16R8** sur platine d'essai — c'est **la puce cible du BOM**,
  et son *touch v2* est celui du produit final : les chiffres mesurés ici sont
  directement transposables (ce ne serait pas le cas d'un ESP32 classique, dont
  le *touch v1* a une polarité et une sensibilité différentes).
- Film **ITO/PET**, découpé aux ciseaux.
- **Ruban cuivre à adhésif conducteur** (3M 1181) pour la reprise de contact.
- Chutes de **plexi** de plusieurs épaisseurs (ou empilage de fines, bien pressées).
- Ohmmètre.

## Précautions de câblage (platine d'essai, dupont, borniers à vis)

Le montage volant est la principale source d'erreur de mesure — pas l'ITO.

- **Le fil fait partie de l'électrode.** 20 cm de dupont ajoutent une capacité
  parasite qui s'additionne à la ligne de base et *écrase le Δ relatif*.
  → fils **les plus courts possible** (< 10 cm si faisable), et **la même
  longueur pour tous les canaux comparés**.
- **Ne jamais comparer deux essais câblés différemment.** Changer un dupont
  invalide la comparaison : refaire la ligne de base (`b`) et re-mesurer la
  référence à vide.
- **Mesure de référence à vide d'abord** : fil branché sur le GPIO, **rien au
  bout**. Ça donne la contribution parasite du câblage seul, à retrancher
  mentalement de tout le reste.
- Ne pas faire courir les fils *touch* en parallèle serrés : ils se couplent
  entre eux (faux cross-talk qui n'existera pas sur PCB).
- Borniers à vis : serrer franchement, et **ne pas visser sur l'ITO** —
  seulement sur le cuivre rapporté ou sur le fil.
- **Garder les mains loin de la platine** pendant la calibration et pendant la
  lecture des canaux voisins.

## Précautions d'alimentation (effet réel et souvent ignoré)

La sensibilité du *self-cap* dépend du couplage de la masse de l'ESP32 à la
terre. Un portable **sur secteur** (donc relié à la terre) donne un Δ nettement
plus fort que le même montage sur **batterie**.

→ **Figer la configuration d'alim pour toute la campagne** et la noter dans le
tableau. Si la cible finale est une alim isolée, refaire au moins une mesure
dans cette condition avant de conclure.

## Préparation de l'échantillon ITO

1. **Trouver la face conductrice** : ohmmètre, deux pointes à ~1 cm.
   Face conductrice = dizaines à centaines d'Ω. Face PET = infini.
2. Découper une électrode **avec sa languette d'amenée** (cf. schéma du concept).
3. **Face conductrice contre le plexi** : elle doit être au plus près du doigt.
   Le PET (~0,125 mm) se retrouve derrière, sans conséquence.
4. Presser le **ruban cuivre conducteur** sur la languette, surface généreuse,
   puis souder le fil **sur le cuivre**. Vérifier la continuité ITO↔fil :
   dizaines/centaines d'Ω = normal et suffisant.
5. **Tout entrefer d'air fausse la mesure vers le bas.** Pour l'essai, presser
   fermement l'ITO contre le plexi (poids, pince, ou adhésif transparent fin).
   Noter la méthode de plaquage dans le tableau — elle fait partie du résultat.

## Déroulé

Pour chaque configuration, main éloignée → `b` (recalibration) → puis :

```sh
scripts/touch_log.py --secs 10 --out mesures/<config>.csv --label "<config>"
```

Pendant les 10 s : **doigt posé à plat, appui normal**, immobile. Le résumé
donne `d moy`, `d max` et `SNR max`.

### Séquence de mesures

| # | Configuration | Ce qu'on cherche |
|---|---|---|
| 0 | Fil seul, rien au bout | base parasite du câblage |
| 1 | ITO nu, doigt direct dessus | Δ plafond de l'électrode |
| 2 | ITO + membrane **1 mm** | sensibilité vs épaisseur |
| 3 | ITO + membrane **1,5 mm** (cible) | **le point de décision** |
| 4 | ITO + membrane **2 mm** | marge si le Dremel dérape |
| 5 | ITO + membrane **3 mm** | pente de dégradation |
| 6 | Électrode **15×15** vs **20×20** vs **25×25** mm, membrane 1,5 mm | surface mini viable |
| 7 | Contact cuivre seul vs cuivre + époxy Ag | le contact limite-t-il ? (attendu : non) |
| 8 | 2 électrodes voisines, écarts 2 / 5 / 10 mm | **cross-talk** : toucher l'une, lire l'autre |
| 9 | Idem 8 + bande de cuivre à la masse entre les deux | efficacité de la garde |
| 10 | Config 3 relue après 10 min de chauffe | **dérive** thermique |

### Critères de réussite

- **SNR max ≥ 10** (Δ ≥ 10× le bruit au repos) sur la config 3 → détection
  robuste avec un simple seuil.
- SNR entre 5 et 10 → exploitable mais demande un suivi de ligne de base
  (baseline tracking) dans le firmware final.
- **SNR < 5 → la piste ITO/1,5 mm ne passe pas** : revoir l'épaisseur de
  membrane avant de figer la mécanique.
- **Cross-talk** : Δ sur le canal voisin non touché < 1/5 du Δ du canal touché.
  Sinon → garde de masse obligatoire entre cellules (config 9).
- **Dérive** sur 10 min < 1/3 du Δ d'un doigt, sinon baseline tracking obligatoire.

## Choix des broches (mesuré, à ne pas supposer)

GPIO1–14 sont annoncées touch-capables ; sur la carte du proto **seules GPIO8, 9,
10 et 12 mesurent réellement**. Les autres rendent `4194303` (0x3FFFFF) avec un
bruit nul — signature d'une mesure qui n'aboutit pas, pas d'une grosse capacité.
**GPIO4 et GPIO5 sont le bus I2C** de la carte, avec pull-ups de 10 kΩ d'origine
(9 kΩ mesurés vers 3V3, carte hors platine, contre 500 kΩ sur GPIO6) : une broche
tenue à un potentiel fixe ne peut pas se charger/décharger, donc ne peut pas
mesurer. Passer `firmware/scan_touch` avant tout nouveau brochage.

## Résultats

Carte : ESP32-S3-WROOM-1 N16R8, alim par USB natif depuis le portable.
Électrode sur **GPIO8**. Bruit de référence d'un canal stable : σ ≈ 11 (GPIO9).

| # | Config | base | Δ (doigt) | Δ relatif | Note |
|---|---|---|---|---|---|
| 0 | broches libres, rien au bout | 28 100 – 31 600 | — | — | σ de 8 à 104 selon le canal |
| 1 | **ITO nu, doigt direct** | **249 500** | **+391 600** | **+157 %** | max 793 900 · **contact intermittent** |
| 1b | **ITO nu, contact pince croco** | **47 000** | **+253 000** | **×6,4** | contact stable, plus de décrochages |
| 1c | ITO, **opérateur relié à la terre** | 47 500 | +1 950 000 | ×42 | pic ~2 M |
| 1c′ | ITO, **opérateur flottant** | 47 500 | +202 000 | ×5,3 | plafond 250 k — **cas de conception** |
| 3 | membrane 1,5 mm | | | | sans objet si le design bascule (cf. concept) |

**Mesure 1 — détail.** Distribution trimodale sur 57 s : broche nue 32 900
(32,5 % des échantillons), électrode au repos 249 500 (45,9 %), doigt posé
641 100 (18,2 %). Le signal capacitif est donc très largement suffisant, mais
**19 décrochages** vers l'état « broche nue » trahissent un contact intermittent
(suspect n°1 : la jonction ITO ↔ ruban cuivre, qui ne se soude pas). Ces
décrochages polluent aussi la ligne de base : σ mesuré à 8 850 au lieu de ~11.
→ Fiabiliser le contact **avant** de mesurer à travers le plexi, sinon la
comparaison entre épaisseurs de membrane n'aura aucun sens.

**Mesure 1b — contact repris.** Une pince croco serrant l'électrode donne un
contact stable : repos 47 000, doigt 300 000, **×6,4**. Le capacitif est donc
validé avec une marge très large, et c'est ce qui autorise la bascule de design
décrite dans [`CONCEPT_PLEXI_EPAIS.md`](CONCEPT_PLEXI_EPAIS.md) (électrode près
de la surface sous revêtement fin, plexi réservé à la LED). Les mesures 2 à 5
« à travers la membrane » perdent alors leur objet ; restent pertinentes la
**taille d'électrode** (6), le **cross-talk** (8-9) et la **dérive** (10).
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

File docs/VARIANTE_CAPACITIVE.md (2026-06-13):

# Concept — boîtier plexi + touches capacitives + 3× ESP32-S3

> **Design actif** (branche `etude/plexi-capacitif`). Ce doc = **concept &
> rationale**. Les **specs figées** (réfs, cotes, implémentation) sont dans
> [`BOM.md`](BOM.md) ; le **modèle 3D coté** dans [`../mechanical/`](../mechanical/) ;
> l'**ergonomie** dans `nidmi-seq-vst/VISION_ERGO_HARMONIE.md` (source de vérité).
> L'ancienne archi MCP23017/PB86-touches est dans [`ARCHITECTURE.md`](ARCHITECTURE.md)
> (**legacy**, divergente).

## Idée directrice

Façade **plexiglas** : les **27 touches piano** et le **ruban** sont des **électrodes
capacitives** sous l'overlay acrylique (le doigt est détecté à travers le plexi).
LEDs **SK6812** diffusées sous le plexi → rendu groovebox, peu d'usure mécanique.
Le geste continu du ruban complète une machine sinon entièrement quantifiée.
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

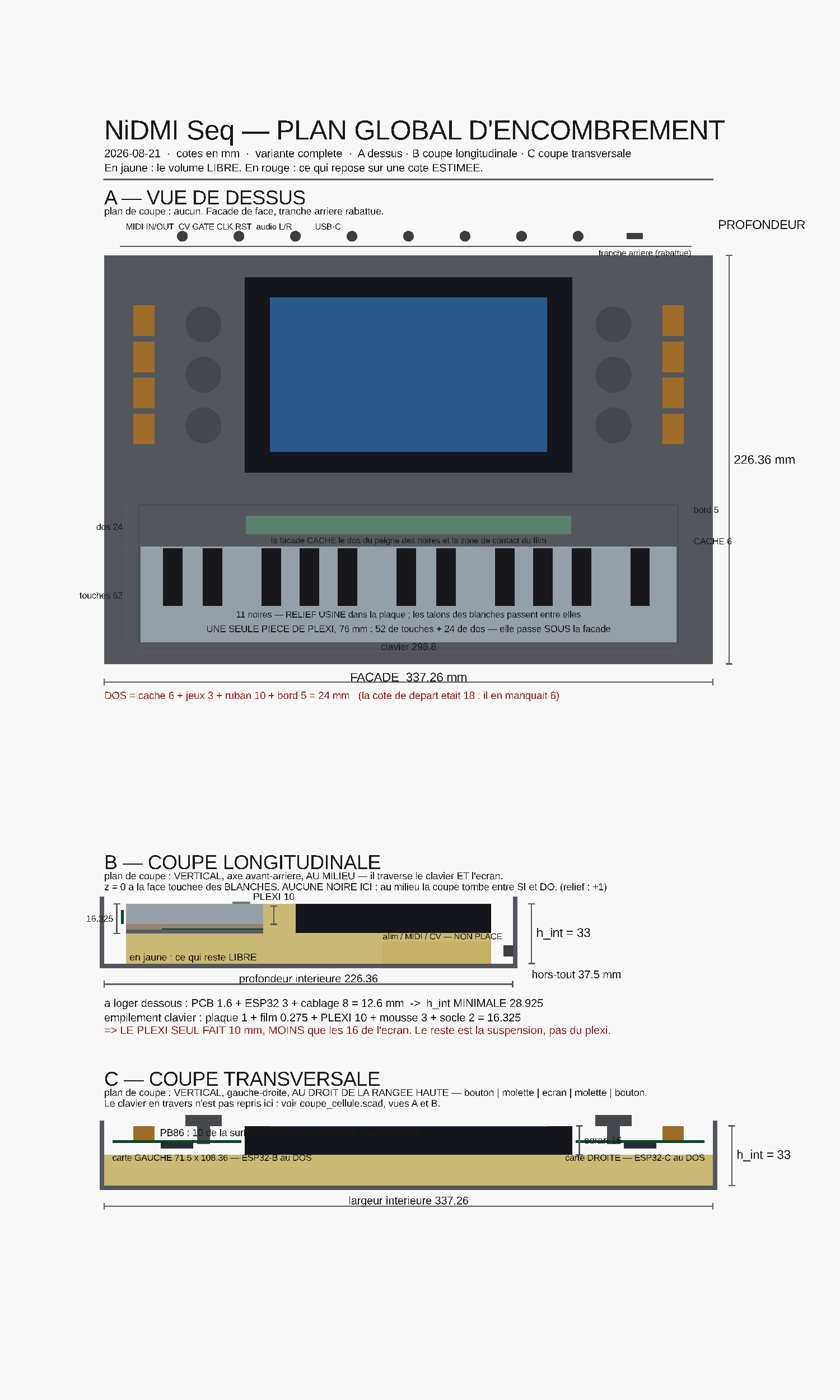
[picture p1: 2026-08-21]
mechanical/encombrement.png

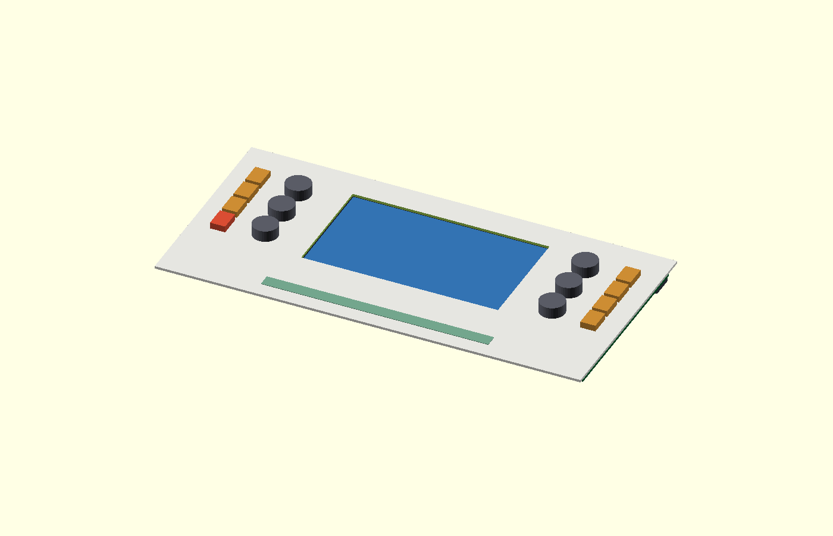
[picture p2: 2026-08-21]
mechanical/implantation_modeste.png

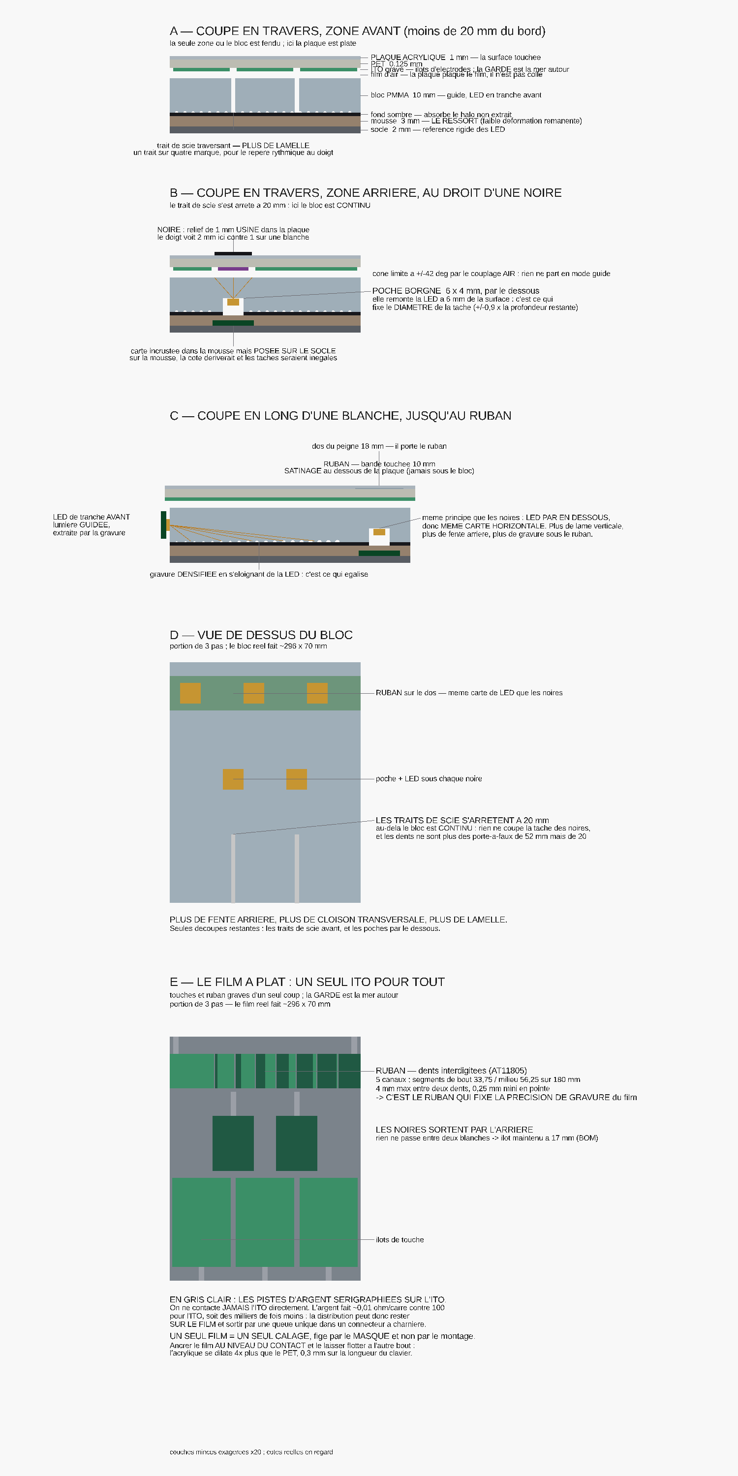
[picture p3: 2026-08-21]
mechanical/coupe_cellule.png

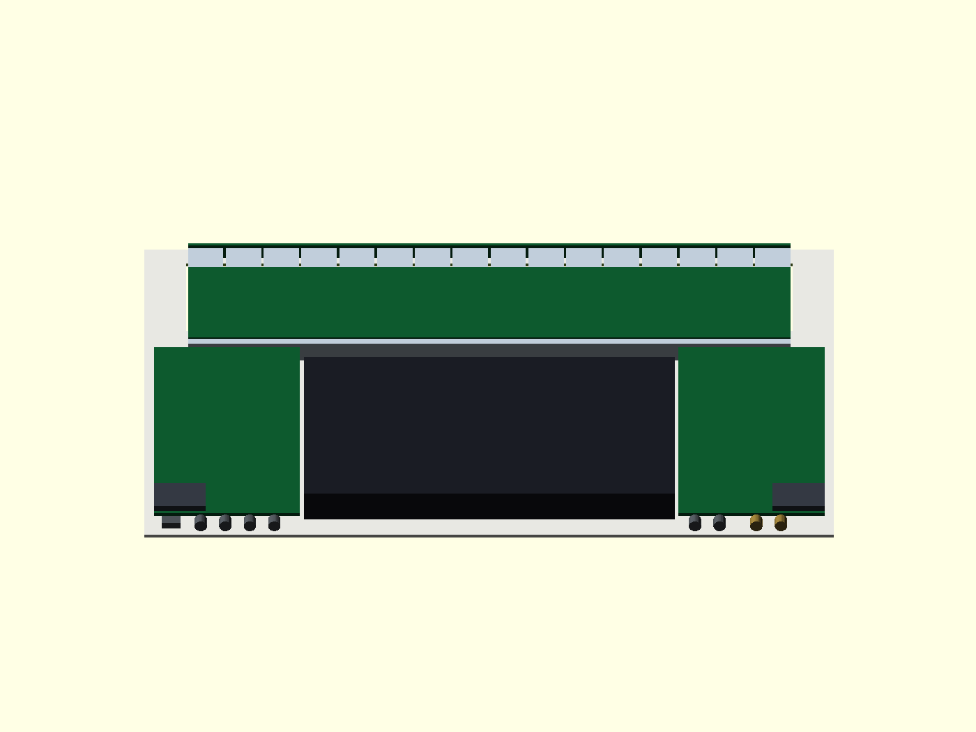
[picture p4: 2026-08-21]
mechanical/implantation_complete.png

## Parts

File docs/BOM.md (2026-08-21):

# BOM — NiDMI Seq (variante plexi capacitive)

> **Source de vérité composants.** Le hardware doit correspondre exactement :
> chaque pièce est définie ici (réf + cotes + implémentation). Le **boîtier suit
> les composants** (modèle `mechanical/facade.scad` paramétrique). Si une pièce
> sourcée diffère, on met à jour la cote → le boîtier se recalcule.
>
> Statuts : 🟢 décidé · 🟡 réf à sourcer/confirmer · 🔴 décision ouverte

## 1. Calcul — 3× ESP32-S3-WROOM-1-N16R8 🟢
- Module 18 × 25,5 × 3,1 mm, castellated/SMD sur PCB.
- Rôles : **A = cerveau** (séquenceur, MIDI, USB, SPI écran, bus LED, comms) ·
  **B + C = tactile** (27 touches + ruban répartis) + lecture encodeurs/boutons.
- *touch* natif = 14 canaux/puce ; 27 touches + ruban (~5) = ~32 / 42 dispo.

## 2. Clavier piano — touches capacitives (27) 🟢 / LED 🟡
- **Électrodes** : cuivre sur PCB (pas de composant). 16 blanches notchées **17 mm**
  + 11 noires **12 mm**, anneau/garde de masse, **R série 470 Ω–2 kΩ / canal**.
- 🟢 **2026-08-21 — PLAQUE ACRYLIQUE CONTINUE, relief usiné dedans.** Une plaque
  de **1 mm** par-dessus l'ITO, avec le relief des noires (**+1 mm**) usiné dans la
  masse. Elle pince le film sur toute sa surface, protège l'électrode partout,
  supprime la colle. Deux options écartées le même jour : le **clavier lisse**
  (pas de repère au doigt, refusé) et le **relief rapporté de 3 mm** (l'aftertouch
  passe à travers 0,125 mm et pas à travers 10 — à 3 mm les noires l'auraient
  perdu alors que les blanches l'auraient gardé).
  🔴 **À mesurer avant de figer : l'aftertouch à 1–2 mm.** C'est le chiffre dont
  dépend toute l'architecture. Détail : `mechanical/README.md`.
- 🟢 **2026-08-21 — contact par piste d'ARGENT sérigraphiée**, jamais sur l'ITO nu.
  ~0,01 Ω/□ contre ~100 pour l'ITO, donc la distribution reste **sur le film** et
  sort par une queue unique dans un connecteur à charnière. Contrainte
  **perpendiculaire uniquement**, et film **ancré au niveau du contact** (dilatation
  différentielle acrylique/PET : 0,3 mm sur la longueur du clavier).
- 🟢 **2026-08-21 — éclairage des noires PAR EN DESSOUS**, une LED par touche sur
  une carte horizontale posée sur le socle. Le trait de scie s'arrête à **20 mm**,
  donc le bloc est continu sous les noires. Supprimés : cloison transversale et
  2ᵉ symbole, lamelles noires, fente arrière. Le 2ᵉ symbole est reporté sur l'écran.
- **LED RGB par touche** : **27× SK6812 3535** (top-emit, 3,5 × 3,5 × ~1,5-1,9 mm),
  bus 1-fil 800 kbps GRB, **~60 mA/LED** à blanc plein. Variante reverse **MINI-E**
  (3,2 × 2,8 mm) si éclairage par découpe PCB. 🟡 figer 3535 vs MINI-E selon cellule.
- **Level-shifter data 3,3→5 V : 74AHCT125** (SK6812 VIH ≥ 3,4 V → 3,3 V hors spec).
- 🟢 **2026-08-19 — RGB confirmé, alternative monochrome écartée.** Une LED unicolore par touche
  aurait divisé la consommation par ~6 et supprimé le 74AHCT125 et le bus 800 kbps, à budget IO
  constant (driver matriciel type IS31FL3731 sur l'I2C déjà présent). **Écartée quand même** : la
  couleur est le seul canal **catégoriel** disponible, or les 27 touches changent de sens selon la
  vue et Shift bascule note↔fonction — sans couleur il ne reste que luminosité et clignotement,
  soit 6 à 8 états distinguables, et le clignotement fatigue sur une grille. Différencier pas,
  accents et swings demande la couleur.
- Les **1,6 A crête** ci-dessus correspondent au **blanc plein** (3 puces à fond). Une palette de
  travail en allume rarement plus d'une ou deux à luminosité modérée : le plafonnement reste sage,
  mais la marge réelle est confortable.

## 3. Encodeurs — 5× EC11 (avec push) 🟡 → **6 demandés** 🔴

> 🔴 **2026-08-15 — la conception en demande SIX.** `nidmi-seq-vst/CONCEPTION.md` §2
> donne une molette dédiée à chacun des deux niveaux de navigation, `Row` et `Pas`,
> qui ne sont jamais prêtées. Sans elles, changer de niveau demandait un raccourci à
> deux mains pour un geste qu'on fait sans arrêt en composant.
>
> **Électriquement, ça passe** : PCNT offre 4 unités par puce et les encodeurs sont
> répartis sur B et C, soit 8 places pour 6 — voir la répartition ci-dessous, à
> recalculer en B(3)/C(3).
>
> **Mécaniquement, à recaler** : le pas de 33 mm entre encodeurs sur une façade de
> 320 mm de large, et la fenêtre plexi. C'est le seul point ouvert.
- Réf : **Bourns PEC11R-4220F-S0024** (datasheet sûr, arbre 20 mm) *ou* **Alps
  EC11E18244AU** (LCSC C202365) *ou* générique EC11 5-pin 20 mm.
- Cotes (CAD) : corps **12,4 × 13,4 × ~6,5 mm**, bossage **M7×0,75 Ø7 × 5 mm**,
  arbre **Ø6 × 15/20 mm**, pattes ~3-3,5 sous PCB, **total ~31-32 mm** (arbre 20).
  Perçage panneau Ø7 + ergot anti-rotation. Bouton Ø15-20, alésage Ø6.
- Élec : A/C/B quadrature (PCNT) + SW/GND push. **Détentes : générique 20/20,
  Alps 15 PPR, Bourns 24** → 🔴 confirmer le ratio avant commande (impact firmware).
- PCNT = 4 unités/puce → **répartir les encodeurs** sur B+C : 5 en B(3)/C(2), ou **6 en B(3)/C(3)** si la demande ci-dessus est retenue.

## 4. Boutons de fonction — 8× PB86 🟡
- ROW · HARMONY · PROJET · SHIFT · PLAY · STOP · REC · EXPORT.
- 🟢 **PLAY + REC = PB86-A2** (bi-couleur rouge/vert, 8 pins) ; **6 autres = PB86-A1**
  (mono, 6 pins). → LED : 2×bi (4 lignes) + 6×mono (6 lignes) = **10 lignes**.
- Cotes : corps **12,4 × 17,0 mm**, course 2 mm, force 170 gf, SPDT, LED 1,8-2,4 V
  / 20 mA.
- 🟢 **2026-08-21 — HAUTEUR CONNUE : 10 mm** entre la **surface du PCB** et la
  **surface visible du cache** (relevé par l'utilisateur). Le PB86 n'est donc
  **pas** le poste dimensionnant : il passe derrière l'écran (16) et le clavier
  (16,3). Une estimation antérieure à 20 mm était fausse du double.
  Le constructeur (**Honyone**) publie un dessin sans cotes ; la seule source
  publique trouvée est [Adafruit](https://www.adafruit.com/product/5517) —
  **17 × 12 × 14 mm**, capuchon compris. Autres cotes relevées : course
  **2,0 ± 0,4 mm**, force **170 ± 50 gf**, **200 000 cycles** — à surveiller sur
  PLAY et STOP, qui prendront l'essentiel des appuis.
- 🔴 **IO** : 8 switches + LED bi-couleur (16 lignes) = ~24 IO → via **expandeur
  I2C (MCP23017 ×1-2)** ou driver LED dédié. À figer. LED PB86 **hors** bus SK6812.
- **Diodes 🟢 → finalement AUCUNE** : les 16 lignes de LED imposent des **MCP23017**
  (voir §12) ; les 8 switches se câblent donc **en direct** sur l'expandeur (1 broche
  chacun) → **pas de matrice → pas de ghosting → pas de diode**. (La table « diode sur
  Shift/Play/Rec » ne s'appliquait qu'à une matrice scannée, abandonnée.)

## 5. Ruban capacitif — slider tactile natif 🟢
- Électrode PCB ~**180 × 10 mm** (motif triangulaire/interdigité), **~5 canaux**
  *touch* ESP32-S3, sous plexi. **Rôle : assignable** (choisi à l'écran). Pas de
  composant externe (R série éventuelle).

### 🟢 2026-08-20 — géométrie d'interpolation, d'après AT11805

Source : **AT11805 — Capacitive Touch Long Slider Design with PTC** (Atmel-42479B, 07/2015).
<http://ww1.microchip.com/downloads/en/AppNotes/Atmel-42479-Capacitive-Touch-Long-Slider-Design-with-PTC_AT11805_ApplicationNote.pdf>

**Ce qui ne s'applique PAS ici.** La note plafonne le slider *self-cap* à **3 canaux et
20–60 mm**, au motif que de grandes électrodes saturent la plage de mesure du périphérique
**PTC d'Atmel**. C'est une limite de *leur* puce et de *leur* bibliothèque, pas de la physique,
et nous n'utilisons ni l'une ni l'autre. Sur notre matériel : ligne de base mesurée
**~47 000 counts pour un plafond à 4 194 303**, soit 1 % de la plage ; et une électrode de ruban
à 5 canaux fait **~360 mm²** contre **~720 mm²** pour une blanche — **plus petite que ce qui
mesure déjà avec des centaines de fois la marge**. Aucun risque de saturation.
(cf. `docs/ESSAI_ITO_ESP32.md`)

**Ce qui s'applique — c'est de la géométrie, donc indépendant du fabricant.**

- **Interpolation spatiale** (dents entrelacées) : praticable **jusqu'à 200 mm**. Nos 180 mm
  passent, sans grande marge. Au-delà la note bascule sur l'interpolation résistive
  (diviseurs entre sous-électrodes, R totale 2–10 kΩ, 300 mm en deux couches, 350 en une).
- **Cotes de dents** : **4 mm maximum** entre deux dents consécutives, **0,25 mm minimum en
  pointe**. Sous 0,25, la surface sous le doigt s'effondre en bord de segment → décrochage
  du signal au passage d'un segment à l'autre.
- **Linéarité** : en tout point, la surface perdue par une électrode doit être exactement celle
  gagnée par sa voisine. C'est ce qui rend la position lisible.
- **Épaisseur de façade admise : 0,5 à 2 mm.** Notre PET fait 0,125 mm → large. (Constantes
  diélectriques tabulées : PMMA 2,8 · Mylar 3 · FR-4 5,2 · verre 7,8.)

**Découpage retenu — 5 canaux sur 180 mm.** N canaux → **N−1 segments**, dont 2 de bout et
N−3 de milieu. Formules de la note (vérifiées sur son propre exemple 240 mm / 7 canaux → 50 et
20 mm) :

    longueur_segment_milieu = (L × 1,25) / (N − 1)
    longueur_segment_bout   = [L − longueur_segment_milieu × (N − 3)] / 2

→ **segments de bout 33,75 mm · segments de milieu 56,25 mm** (2 × 33,75 + 2 × 56,25 = 180).
Des segments de bout plus courts que ceux du milieu, c'est ce qui ramène la **zone morte de
10 % à 3 %** : **~5,4 mm** à chaque extrémité au lieu de 18.

**Ce que les 5 canaux apportent sur 3** : à 3 canaux il n'y a que **deux segments de 90 mm**, et
la linéarité doit tenir sur toute cette longueur. À 5, chaque segment fait 56 mm → **~14 dents
au lieu de ~28**, motif ITO plus simple à graver et linéarité à tenir sur deux fois moins de
longueur. (À 7 canaux : segments de 37,5 mm, ~9 dents — mais 7 canaux tactiles à trouver.)

**Sans effet sur la décision broches** : à 5 canaux le ruban ne tient toujours pas sur les 5
broches libres du CrowPanel sans supprimer l'UART. La migration vers l'ESP32-B ou C reste acquise.

### 🟡 2026-08-20 — piste CrowPanel 7,0″ (écran + ESP32-S3 intégrés)

L'implantation de façade (`mechanical/implantation.scad`) libère la place d'un **7 pouces** :
avec 3 molettes de chaque côté de l'écran et les boutons en colonnes, la rangée haute fait
303,8 mm. Le **CrowPanel ESP32-S3 7,0″** (Elecrow, 800×480, actif 153,84 × 85,63 mm) embarque
la puce **et** l'écran, ce qui supprimerait la nappe FPC 40 broches et le routage des ~20
lignes RGB — l'obstacle qui avait fait écarter un 5″ RGB au profit du 4,0″ SPI.

⚠️ **Deux modèles, et la différence est décisive :**

| | broches libres | verdict |
|---|---|---|
| **CrowPanel 7.0** (24,90 $) | aucun connecteur de broches — Crowtail seulement : 2× I2C, IO38, UART0 | **ne peut pas être le cerveau** |
| **CrowPanel Advance 7.0** | ~10 libres, dont IO2/IO4/IO5/IO6 ; l'écran prend ~20 broches (16 data + DE IO42, HSYNC/VSYNC IO40/41, PCLK IO39) ; I2C sur GPIO15/16 | **candidat crédible** |

Une dizaine de broches suffit au cerveau : I2C (2× MCP23017 + MCP4728), UART vers B et C
plus MIDI, et le ruban tactile.

### Modèle retenu : CrowPanel **Advance 7.0-HMI ESP32 AI Display** — 34,90 $

<https://www.elecrow.com/crowpanel-advance-7-hmi-esp32-ai-display-800x480-ai-ips-touch-screen.html>

**ESP32-S3, 8 Mo PSRAM, 16 Mo flash** = exactement le **N16R8** déjà spécifié pour les trois
puces du projet. Aucun changement de plateforme. 800×480 IPS tactile capacitif (GT911).

⚠️ **Les « 11 broches libres » annoncées sont trompeuses** — « libre » y signifie *sans rôle de
démarrage*, pas *inutilisée* :

| broches | réalité |
|---|---|
| IO7, IO17, IO18, IO21 | **lignes de données de l'écran** → indisponibles |
| IO15, IO16 | **bus I2C**, partagé avec GT911, RTC PCF8563 (0x51), contrôleur rétroéclairage (0x30) |
| **IO2, IO4, IO5, IO6, IO8** | **réellement disponibles** — au prix du haut-parleur I2S, du micro, de la microSD et du buzzer (sans usage ici) |

**Bilan cerveau :**
- **I2C : passe.** Bus partagé, mais aucune collision d'adresse avec MCP23017 (0x20-0x27) ni
  MCP4728 (0x60-0x67).
- **Conflit sur les 5 broches restantes** : le **ruban** demande ~5 canaux tactiles et l'**UART**
  vers B et C en demande 2 à 4. Les deux ne tiennent pas. (IO2/4/5/6/8 sont bien dans la plage
  tactile du S3, donc le ruban serait faisable — mais alors plus rien pour l'UART.)

> 🟢 **2026-08-21 — mise à jour.** Le ruban vit sur le **dos du peigne**, même
> pièce de plexi que les touches, et ses LED sont **sous le bloc** sur la même
> carte horizontale que celles des noires. Il n'y a plus de PCB de tranche partagé.
> Côté canaux tactiles, la décision ci-dessous est inchangée : 5 canaux ne tiennent
> pas sur les broches libres du CrowPanel sans supprimer l'UART.

→ **Décision : le ruban migre sur l'ESP32-B ou C**, ce qui libère les 5 broches pour la liaison
inter-puces. Le repli identifié devient la solution de base.

🟢 **2026-08-21 — encombrement de la carte : COTES FOURNIES par l'utilisateur**, qui a passé
la commande et relevé les dimensions. Elles ne figurent ni sur la fiche produit ni sur
espboards : ne pas les « re-sourcer » sur le web, c'est ici la référence.

| | cote |
|---|---|
| carte | **181,26 × 108,36 × 16 mm** |
| zone active | **153,84 × 85,63 mm** |
| bordure | 13,71 mm en largeur · 11,37 mm en hauteur (**non symétrique**) |

Les 16 mm d'épaisseur font de l'écran le **composant dimensionnant du boîtier**, devant le
clavier (10 mm de guide + 1 de plaque). C'est cette cote qui fixe la hauteur intérieure.
Le blocage « pas de boîtier sans les cotes de l'écran » est **levé**.

Réf. broches : espboards.dev/esp32/elecrow-crowpanel-advance-7-esp32-s3/

🔴 **Point de risque restant : le ruban.** Il demande ~5 canaux tactiles, et seules 4 des broches
libres nommées tombent dans la plage tactile du S3. Surtout, **on a mesuré (2026-08-19) que
« touch-capable » ne veut pas dire « mesure » : sur 14 canaux annoncés d'une carte S3, 4
seulement rendaient des valeurs exploitables** (cf. `docs/ESSAI_ITO_ESP32.md`, `firmware/scan_touch`).
→ Passer `scan_touch` sur la carte réelle avant de figer, et prévoir que le ruban puisse
migrer vers l'ESP32-B ou C.

Refs : espboards.dev/esp32/elecrow-crowpanel-advance-7-esp32-s3/ · elecrow.com/wiki

## 5b. Moteur audio interne — OPTION RÉSERVÉE 🟡 (2026-08-20)

**Décision : place réservée dans le boîtier, réalisation reportée.** Le but initial reste de
piloter des machines externes en MIDI ; le moteur audio ferait de l'instrument un autre objet.

**Matériel visé** (celui du XVA1 de René Ceballos, déjà en possession) :

| | réf | cotes |
|---|---|---|
| FPGA | **Digilent Cmod A7-35T** (Xilinx Artix-7 35T, DIP 48 broches) | 17,78 × 69,85 mm, ~12 mm avec support |
| DAC | **PCM5102A** — *pas* l'UDA1334A du XVA1 | ~40 × 25 × 7 mm |

**Pourquoi le PCM5102A** : il **ne demande pas de MCLK** (il la régénère du BCLK), ce qui évite
de produire et router une horloge à 256×fs côté FPGA. 112 dB de SNR, 32 bits/384 kHz, sortie
**2,1 V RMS** — vrai niveau ligne pour attaquer un étage symétrique. Éviter les modules bon
marché : décalage de niveau incorrect et découplages absents, décrochage au-dessus de 48 kHz.

**Réservation** : volume de **62 × 70 mm, 12 mm de haut** en cavité arrière. En plan la façade
est saturée — la réservation est un volume, pas une surface.

**Sortie audio symétrique, 2 canaux.** Deux conséquences :
- **Étage de sortie** : driver différentiel (DRV134, THAT1646, ou paire d'AOP), ou sortie
  *impedance-balanced* (point froid à la masse via résistance de même valeur) — presque aussi
  efficace contre le mode commun, pour deux résistances.
- 🟢 **DÉCIDÉ 2026-08-21 : jack 3,5 mm.** Le TRS 6,35 mm aurait fait ~14 mm de diamètre et
  **25-30 mm de profondeur**, devenant le composant le plus profond de l'instrument devant le
  CrowPanel (16 mm), et commandant donc l'épaisseur du boîtier. En 3,5 mm (PJ-320A, ~5 mm de
  profondeur), **le CrowPanel redevient le poste dimensionnant**. La sortie reste
  électriquement **symétrique** — seul le format de connecteur change.

**Sur le multitimbral** : sur un moteur multiplexé dans le temps, il coûte de la **mémoire, pas
des multiplieurs** — chaque voix lit les paramètres de sa partie, c'est un index de plus. Les
voix restent **partagées** entre parties. Le poste cher est l'**effet par partie** (d'où les
départs vers effets globaux). Une seule architecture de synthèse, plusieurs patchs : c'est ça
qui reste gratuit.

## 6. Écran — 4,0″ 480×320 SPI ⛔ **PÉRIMÉ**

> ⛔ **Cette section décrit l'écran ABANDONNÉ.** L'écran retenu et **commandé** est le
> **CrowPanel Advance 7.0-HMI** — voir §5 ci-dessus, qui porte les cotes de référence.
> Section gardée pour mémoire : elle documente pourquoi un module SPI séparé a été écarté
> (nappe FPC, routage RGB), et son « impact boîtier » n'a plus cours.

- **Contrôleur** : 🟢 **ILI9488** (choix utilisateur ; 18 bpp, OK en *partial
  refresh*). ST7796 = alternative plus rapide (même PCB) si jamais dispo.
- Cotes : **PCB 61,74 × 108,04 mm**, **actif 55,68 × 83,52 mm**, ép. 1,6 mm,
  verre +3-4 mm, **header 14 broches** sur petit bord, trous M3 aux coins (à mesurer).
- Pilotage : **cerveau, SPI ~6 fils** (SCK MOSI CS DC RST + LED PWM), 3,3 V logique.
  Tactile XPT2046 du module **non câblé**.
- ⚠️ **Impact boîtier** : le **PCB fait 108 × 62 mm** (≫ fenêtre 84 × 56) → il faut
  dégager les contrôles au-delà de ce footprint → **revoir le bandeau haut / élargir
  la façade** (actuellement W=320). Fenêtre plexi ≈ 57 × 85 mm.

## 7. MIDI — voir [`CONNECTEURS_MIDI.md`](CONNECTEURS_MIDI.md) 🟡
- IN : opto **H11L1** (reco, sortie logique 3,3 V) + 220 Ω + 1N4148.
- OUT : buffer **74HC14**, R série 220/220 Ω @5 V (ou 33/10 Ω @3,3 V) 🔴.
- 🟢 **TRS type-A** (Ring=+, Tip=signal, Sleeve=shield).

## 8. CV / Gate / Clock / Reset — sous-système analogique 🟢 0–5 V (nouveau)
- **CV** : **MCP4728** (DAC quad 12-bit I2C, MSOP-10, addr 0x60, **0 GPIO** — sur
  l'I2C existant). 4 CV.
- **Mise à l'échelle 1V/oct, 0–5 V 🟢** : DAC Vref interne ×2 (0–4,096 V) → AOP
  **rail-to-rail 5 V** (MCP6022 / MCP6V07), gain ~1,25 (Rf 2,5 k / Rg 10 k) → 0–5,12 V.
  **Pas de rail +12 V** (alim simplifiée). Vref précision ADR4540 optionnelle (accordage).
- **Gate/Clock/Reset** : 5 V via **74HCT125** (3,3→5 V), Eurorack = gate +5 V.
  **3 GPIO** (proposition : 40/41/42).
- Protection/jack : R série 1 kΩ, clamp **BAT54S**, 100 pF. **LDO 5 V propre**
  (MCP1700-5002) dédié DAC/Vref.

## 9. Connectique 🟢 — **en bord de carte** (2026-08-21)

> 🟢 **Plus de carte de connectique séparée, ni de fils vers la tranche.** Les
> deux cartes latérales arrivent à 2 mm de la paroi arrière : les connecteurs y
> sont soudés en bord de carte et traversent la paroi.
>
> | carte | contenu | occupé / dispo |
> |---|---|---|
> | **gauche** (ESP32-B) | USB-C + CV, GATE, CLK, RST | **71** / 71,5 mm |
> | **droite** (ESP32-C) | MIDI IN, MIDI OUT + audio L/R | **62** / 71,5 mm |
>
> La répartition sépare l'**alimentation** (USB-C, sorties 5 V) des **sorties
> audio**, tenues loin du convertisseur à découpage. L'entraxe de **12 mm** est
> dicté par le diamètre des **fiches** (~9 mm de corps), pas par les embases.
>
> ⚠️ **Corrigé** : `n_jack` valait 5 alors que la liste en compte **six** — MIDI
> IN, MIDI OUT, CV, GATE, CLK, RST. Il manquait un jack sur la tranche.
>
> 🟡 Les quatre CV sont du côté alimentation, donc côté bruit de découpage. Le CV
> est le signal le plus sensible de l'instrument (12 bits, tension continue) : le
> LDO 5 V dédié était déjà prévu, la proximité physique est à regarder au routage.

- **USB-C** : **GT-USB-7010ASV** 16-pin (LCSC C2988369), 8,9 × 7,35 × 3,26 mm.
  **2× CC 5,1 kΩ** (Rd), TVS **USBLC6-2SC6**, polyfuse 0,5-1 A. D+/D- → GPIO19/20.
- **Jacks 3,5 mm** : **PJ-320A** (THT, board-edge, Ø6 panneau, 12 × 5 × 5 mm) pour
  MIDI IN/OUT + CV/GATE/CLK/RST.

## 10. Alimentation 🟡
- Entrée **USB-C 5 V** → **buck 3,3 V 2 A** (AP63203/MP2315) pour 3× ESP32 + logique.
- **74AHCT125** (level-shift LED). Bulk **1000 µF** sur 5 V LED, découplage.
- Budget LED : 27× SK6812 ≈ 1,6 A crête → **plafonner luminosité** (USB-C 15 W).
- CV en **0–5 V** → pas de rail +12 V. **LDO 5 V propre** dédié DAC/Vref (anti-bruit).

## 11. Mécanique — ⚠️ **chiffres périmés, voir `mechanical/implantation.scad -D plan=true`**

> 🟢 **2026-08-21 — PLAN GLOBAL D'ENCOMBREMENT établi**, puis affiné en séance.
> Modèle : `mechanical/implantation.scad` (3D par défaut, planche cotée avec
> `-D plan=true`). Détail et justifications : `mechanical/README.md`.
>
> | | cote |
> |---|---|
> | façade | **337,26 × 226,36 mm** |
> | hors-tout | **342,26 × 231,36 × 37,5 mm** (façade 2 + intérieur 33 + fond 2,5) |
> | hauteur intérieure | 33 mm — minimale calculée **28,9** |
> | poste dimensionnant | **le clavier**, 16,3 mm, devant l'écran à 16 |
>
> ⚠️ Les **25 mm** annoncés ci-dessous sont **périmés** : ils dataient du module
> 4,0″ SPI. Le CrowPanel fait 16 mm d'épaisseur.
>
> 🟢 **La façade fait CACHE.** La pièce de plexi et l'écran passent **dessous** ;
> le doigt les atteint par des ouvertures. Conséquence : le dos du peigne passe de
> 18 à **24 mm** (cache 6 + jeux 3 + ruban 10 + bord arrière 5), donc la pièce de
> plexi de 70 à **76 mm**.
>
> 🟢 **Pas d'inclinaison** — étudiée puis écartée pour le prototype : trop longue
> à mettre au point pour ce qu'elle apporte. Les quatre directions examinées et ce
> qui les départage sont dans `mechanical/README.md`.

- Empilement (haut→bas) : plexi **2 mm** · **entrefer avant 7 mm** (dégage le corps
  EC11 ~6,5 + PB86 + module écran) · PCB **1,6 mm** · **cavité 12 mm** (3× ESP32 ~3 +
  connecteurs) · fond **2,5 mm**. → **profondeur totale ≈ 25 mm.**
- ⚠️ **2 PCB** : sous-couche **électrodes capacitives** près du plexi (touches + ruban,
  gap ~2-3 mm pour la sensibilité) **+ PCB principal** en bas (encodeurs, électronique,
  connecteurs). L'entrefer 7 mm = dégagement du corps des encodeurs entre les deux.
- Jacks **PJ-320A board-edge** (~5 mm) + USB-C sur la **tranche arrière**, au niveau du
  PCB principal. Boîtier parois **2,5 mm**.

## 12b. Les cartes 🟢 (2026-08-21)

**Quatre cartes**, plus l'alimentation dont la position n'est pas décidée.

| carte | taille | contenu |
|---|---|---|
| **latérale gauche** | **71,5 × 131,9 mm** (94 cm²) | double face : 4 PB86 + 3 EC11 devant, **ESP32-B** derrière |
| **latérale droite** | idem | idem, **ESP32-C** |
| **LED avant** | 294,8 × 8 mm, verticale | 16 LED, injection en tranche des blanches |
| **LED du dessous** | 294,8 × 56 mm, ENIG 0,6–0,8 | 11 LED des noires + celles du ruban ; **posée sur le socle**, dans la découpe de la mousse |

Les latérales sont dimensionnées **au maximum utilisable** (94 cm²), pas à
l'emprise des commandes (71,5 cm²) — un tiers de plus. Limites : en largeur le
CrowPanel descend à −16 alors que la carte est à −9,6 ; en profondeur le plexi
descend à −16,3. Hauteur disponible : **8 mm au-dessus**, **23,4 en dessous**.

**Les modules ESP32 sont au bord extérieur, couchés.** Trois raisons : ils ne
coupent plus la carte en deux, leur **antenne PCB** se retrouve au bord du
boîtier comme la note Espressif le demande, et le gain de surface (4,6 cm²) est
accessoire. ⚠️ Si le sans-fil doit servir, la matière du boîtier compte — un
capot métallique tue l'antenne.

> 🟡 **Ouvert : ces deux cartes sont-elles identiques ?** L'implantation étant
> boutons à l'extérieur / molettes à l'intérieur des deux côtés, la **même carte
> tournée de 180°** présente le bon ordre de l'autre côté — un seul dessin, une
> seule série, une seule relecture. Charger l'une de l'alimentation et l'autre du
> moteur audio y ferait renoncer. Le moteur audio (Cmod A7 + DAC, 62 × 70) ne
> tient de toute façon pas à plat entre les colonnes de commandes ; il demanderait
> une carte fille dans les 23 mm sous la carte.

## 12. Budget IO / répartition 3 puces 🟡
**Tactile = 32 canaux (27 touches + ruban ~5) → les 3 puces en font** :

| Ressource | A (cerveau) | B | C |
|---|---|---|---|
| Touch (canaux) | **5** (ruban) | **14** (touches) | **13** (touches) |
| Écran SPI (6) · MIDI (2) · USB (2) · LED SK6812 (1, RMT) · I2C master (2) | ✓ | | |
| Gate / Clock / Reset (3 GPIO) | ✓ | | |
| Encodeurs A/B (PCNT) | | 3 enc | 2 enc |
| Comms inter-puces | maître | ✓ | ✓ |

- **I2C (cerveau)** : 2× **MCP23017** (0x20/0x21) + **MCP4728** (0x60). Les MCP23017
  portent **8 switches PB86 (direct) + 10 lignes LED (2 bi + 6 mono) + 5 push encodeurs**
  = **23 / 32 IO** (marge confortable). CV (DAC) = 0 GPIO.
- **PCNT** = 4 unités/puce → 5 encodeurs répartis B(3)/C(2). **1 cran = 1 cycle
  quadrature** (générique 20/20 ou Bourns 24/24) pour 1 clic = 1 pas.
- 🟢 **Lien inter-puces = UART dédié** (latence basse pour le jeu des touches).
- Cerveau : ribbon (5) + gate/clk/rst (3) sur GPIO 1-14 ; écran/MIDI/LED/I2C sur
  GPIO >14 (12 dispo) ; USB 19/20. **Tient, mais serré** → pinout exact à valider au schéma.

## Décisions (récap)
- ✅ Écran = **ILI9488 4,0″ 480×320 SPI**.
- ✅ **CV 0–5 V** (pas de rail +12 V).
- ✅ MIDI = **TRS type-A**.
- ✅ Encodeurs = **1 cran = 1 cycle quadrature** (20/20 ou 24/24).
- ✅ Lien inter-puces = **UART dédié** (latence basse).
- ✅ Boutons : **PLAY/REC = PB86-A2 bi-couleur**, 6 autres = **A1 mono** ; switches en
  direct sur 2× MCP23017 → **aucune diode**.
- 🟡 **LED touches (SK6812 3535 vs MINI-E)** + dessin de cellule → **étude diffusion**
  en cours (voir [`ETUDE_DIFFUSION_LED.md`](ETUDE_DIFFUSION_LED.md)).
- 🟡 Driver MIDI OUT 5 V vs 3,3 V (mineur).

## Implications boîtier
- ✅ **Écran PCB 108 × 62 mm** intégré au modèle (fenêtre active 84×56, contrôles
  reculés à droite du PCB ; enc pitch 33 / boutons 20 → tient en W=320).
- Profondeur cavité à recaler sur encodeurs (~32 mm) + jacks PJ-320A board-edge.

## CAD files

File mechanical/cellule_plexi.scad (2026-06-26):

// =====================================================================
//  NiDMI Seq — Étude d'UNE cellule touche dans le plexi épais
//  (branche etude/plexi-epais-grave)
//
//  Électrode au fond d'une poche fraisée au dos ; membrane fine devant ;
//  LED au centre. But : valider les épaisseurs à l'œil.
//
//  Deux variantes d'électrode (elec_mode) :
//    "ring" = anneau cuivre opaque + trou central, LED par le trou.
//    "ito"  = film ITO transparent PLEINE surface, la LED traverse
//             l'électrode (pas de trou, pas de hot-spot central) +
//             languette de contact vers la rainure (cf. CONCEPT_PLEXI_EPAIS).
//
//  cut = true  -> coupe (montre la section : membrane / poche / électrode / LED)
//  Rendu : openscad -o cellule.png --imgsize=1400,1000 \
//            --camera=0,0,5,68,0,40,90 cellule_plexi.scad
//  Variante ITO : ajouter  -D 'elec_mode="ito"'  (sortie cellule_ito.png).
// =====================================================================

/* [Cellule] */
cell      = 20;    // côté de la cellule (touche)
plexi_t   = 10;    // épaisseur du plexi
membrane  = 1.5;   // membrane avant (devant l'électrode)
wall      = 3;     // paroi plexi entre cellules / autour de la poche
led_win   = 6;     // fenêtre LED centrale (membrane percée — mode "ring")
elec_t    = 0.2;   // épaisseur électrode (cuivre ou ITO)
chan_w    = 3;     // rainure de câblage (au dos)

/* [Électrode] */
elec_mode = "ito"; // "ito" (pleine surface transparente) | "ring" (anneau cuivre)

/* [Affichage] */
cut       = true;  // coupe pour voir la section
show_dims = true;

led_sz = 3.5; led_h = 1.6;
$fn = 56;

pocket = cell - 2*wall;          // côté de la poche
pdepth = plexi_t - membrane;     // profondeur de poche (depuis le dos)

C_PLEXI  = [0.60,0.78,0.95,0.35];
C_COPPER = [0.80,0.55,0.20];
C_ITO    = [0.55,0.85,0.95,0.22];   // film ITO : quasi transparent (la LED traverse)
C_LED    = [0.95,0.95,0.85];
C_DIM    = [0.85,0.10,0.10];

is_ito = (elec_mode == "ito");

module cell_assembly() {
    // --- PLEXI ---
    color(C_PLEXI) difference() {
        translate([-cell/2,-cell/2,0]) cube([cell, cell, plexi_t]);
        // poche fraisée depuis le dos (z=0) jusqu'à pdepth
        translate([-pocket/2,-pocket/2,-0.01]) cube([pocket, pocket, pdepth+0.01]);
        // fenêtre LED : membrane percée au centre — uniquement en mode "ring"
        // (en "ito" la membrane reste PLEINE, la LED traverse l'ITO transparent)
        if (!is_ito)
            translate([0,0,pdepth-0.01]) cylinder(d=led_win, h=membrane+0.02);
        // rainure de câblage (bord -> poche, au dos)
        translate([-cell/2-0.01, -chan_w/2, 0]) cube([wall+0.02, chan_w, chan_w]);
    }
    // --- ÉLECTRODE (au sommet de la poche, derrière la membrane) ---
    if (is_ito) {
        // ITO PLEINE surface + languette de contact vers le bord (-x)
        color(C_ITO) translate([0,0,pdepth-elec_t]) linear_extrude(elec_t) {
            square([pocket, pocket], center=true);
            translate([-cell/2, -chan_w/2]) square([cell/2, chan_w]); // languette
        }
    } else {
        // anneau cuivre (trou central = passage LED)
        color(C_COPPER) translate([0,0,pdepth-elec_t]) linear_extrude(elec_t)
            difference() {
                square([pocket, pocket], center=true);
                circle(d=led_win+2);
            }
    }
    // --- LED au centre (émet vers la membrane) ---
    color(C_LED) translate([-led_sz/2,-led_sz/2, pdepth-led_h]) cube([led_sz, led_sz, led_h]);
}

// --- côtes (sur la face de coupe, plan XZ à y=0) ---
module dimZ(z1,z2,x,s) {
    color(C_DIM) {
        translate([x, 0, z1]) rotate([90,0,0]) cylinder(d=0.4, h=0.4);
        translate([x, 0, z2]) rotate([90,0,0]) cylinder(d=0.4, h=0.4);
        translate([x, 0.3, (z1+z2)/2]) rotate([90,0,0]) linear_extrude(0.4)
            text(s, size=1.6, halign="center", valign="center");
    }
}

if (cut) difference() {
    cell_assembly();
    translate([-cell, 0.001, -1]) cube([2*cell, cell+1, plexi_t+2]);   // enlève la moitié y>0
} else cell_assembly();

if (show_dims && cut) {
    dimZ(pdepth, plexi_t, cell/2+2, str("memb ", membrane));
    dimZ(0, plexi_t, -cell/2-2, str("plexi ", plexi_t));
    dimZ(pdepth-elec_t, pdepth, cell/2+5, is_ito ? "ITO" : "elec");
}

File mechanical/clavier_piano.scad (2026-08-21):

// =====================================================================
//  NiDMI Seq — Clavier piano 27 touches, géométrie de facteur de piano
//  16 blanches + 11 noires (do → ré, 2 octaves + 1 ton)
//
//  Empilement étudié ici (cf. docs/ETUDE_DIFFUSION_LED.md) :
//    - plaque ACRYLIQUE TRANSPARENTE découpée en 16 blanches séparées,
//      chacune servant de guide de lumière (gravure au dos, LED en tranche)
//    - plaque plus FINE et plus SOMBRE posée dessus, découpée en 11 noires
//    - PCB de tranche AVANT   : 16 LED, injection dans les blanches
//    - PCB de tranche ARRIÈRE : 11 LED, injection dans les noires (moins haut)
//    - caches avant / arrière : masquent les PCB et donnent l'illusion clavier
//
//  Rendus : voir README.md
// =====================================================================

/* [Affichage] */
explode       = 0;     // [0:40] 0 = assemblé ; >0 = écarte les couches en Z
show_dims     = true;
show_blanches = true;
show_noires   = true;
show_pcb      = true;
// 2026-08-21 : plus de caches — c'est la BOITE qui fait cet office (commit 18aa29c).
show_caches   = false;
vue_plan      = false; // true = vue a plat lisible : blanches OPAQUES, noires
                       // noires, sans PCB ni caches. Sert a verifier a l'oeil que
                       // les proportions sont celles d'un vrai piano.
// UNE SEULE PIECE PAR PLAQUE : les touches restent reliees par un DOS plein a
// l'arriere (peigne), au lieu d'etre 27 pieces separees. Divise le nombre de
// pieces par plus de deux et supprime tout probleme d'alignement au montage.
//
// !! Le dos est un CHEMIN DE LUMIERE. Il doit etre a l'OPPOSE de l'injection :
//    LED en tranche AVANT, dos ARRIERE. Relier les touches du cote des LED
//    repartirait la lumiere dans le dos et eclairerait toutes les touches a la
//    fois — exactement la selectivite qu'on cherche a preserver.
//    Le dos partage quand meme un peu de lumiere entre touches voisines : le
//    garder AUSSI ETROIT que la tenue mecanique le permet, et mesurer.
plaques_entieres = true;
// 2026-08-21 : ALIGNE SUR L'ARCHITECTURE ARRETEE (coupe_cellule.scad). Le dos
// porte LE RUBAN : c'est la meme piece de plexi que les touches.
// !! 24 et non 18 : le dos ne loge pas que le ruban, il doit aussi laisser a la
//    FACADE de quoi CACHER le dos du peigne des noires et la zone de contact du
//    film. Repartition calculee dans implantation.scad (kb_dos_mini) :
//      cache 6 + jeux 3 + ruban 10 + bord arriere 5 = 24.
//    Wh et dos DOIVENT suivre implantation.scad — l'echo le verifie.
dos              = 24;

// SEPARATION DES TOUCHES — "rainure" (defaut) ou "decoupe".
//
// Sur un clavier CAPACITIF, ce qui separe les touches c'est le dessin de
// l'ELECTRODE et les gardes, pas la matiere. Rien ne bouge : decouper le plexi
// sous les noires n'a aucune justification mecanique, et cree au contraire des
// porte-a-faux et des amorces de fissure dans une matiere cassante.
//
// L'Arturia MicroFreak fait exactement cela : clavier capacitif plat, blanches
// separees par de simples reliefs peu profonds ("shallow ridges"), noires
// portees par une couche legerement surelevee.
//   refs : soundonsound.com/reviews/arturia-microfreak, musicradar.com
//
// "rainure" : bloc PLEIN, rainures peu profondes cote face avant. Solide, et le
//             creux sert en meme temps de LOGEMENT DE POSITIONNEMENT pour la
//             plaque des noires, qui s'auto-aligne au collage.
// "decoupe" : touches reellement separees. Ne se justifie que si les essais
//             montrent que la pollution lumineuse d'une touche a l'autre est
//             redhibitoire — a MESURER avant de s'y engager.
separation = "rainure";
rainure_p  = 1.0;   // profondeur des rainures (et du logement des noires)

piece         = "tout"; // "tout" | "blanches" | "noires" — isole une plaque pour
                        // juger le travail de decoupe, ou pour exporter un DXF
coupe         = false; // true = coupe transversale : seul moyen de voir les PCB
                       // de tranche et les caches, qui sont justement faits pour
                       // etre invisibles une fois assembles.

/* [Géométrie clavier] */
white_n     = 16;      // blanches (do → ré sur 2 octaves + 1 ton)
pitch_w     = 18.5;    // PAS des blanches (entraxe). Piano réel : 23.5
gap_w       = 1.2;     // trait de découpe entre blanches
// 2026-08-21 : cotes de l'architecture arretee (coupe_cellule.scad).
// !! Wh est la longueur TOTALE DE LA PIECE, DOS INCLUS — pas la partie avant.
//    C'est y_dents = Wh - dos qui donne la fin des touches. Confondre les deux
//    raccourcit la piece et le ruban se retrouve DANS LE VIDE, derriere le plexi.
Wh          = 76;      // PIECE ENTIERE : 52 de zone de touches + 24 de dos
Bh          = 32;      // longueur d'une noire (coupe_cellule.scad Lb)
// LARGEUR DES NOIRES — attention a la cote choisie. Une noire de piano est
// TRONCONIQUE : ~9.5 mm au sommet (ou le doigt se pose) mais 13.7 mm a la base.
// Vue de dessus, et a plus forte raison sur une facade PLATE ou il n'y a aucun
// fruit, c'est la BASE qui fait la largeur apparente.
//   Cotes normalisees : blanche 23.5 mm, noire 13.7 mm -> rapport 0.583.
// (Prendre 0.404, la cote du sommet, donne des noires visiblement maigres.)
black_ratio = 0.583;
// TALONS DES BLANCHES (partie etroite entre les noires), do re mi fa sol la si.
//
// Des talons TOUS EGAUX sont mathematiquement IMPOSSIBLES : il faudrait resoudre
// en meme temps 3W = 3w + 2B (groupe do-re-mi) et 4W = 4w + 3B (groupe
// fa-sol-la-si), ce qui n'admet de solution que pour B = 0, donc sans noires.
//
// L'arrangement optimal retenu par les facteurs de piano, et le defaut de ce
// modele (tails = undef) :
//     do, re, mi        talon = W - 2B/3
//     fa, sol, la, si   talon = W - 3B/4
// L'ecart maximal entre les deux vaut B/12 — c'est le minimum atteignable.
// Refs : mathpages.com/home/kmath043.htm, quadibloc.com/other/cnv05.htm
//
//   tails = [...] -> sept cotes explicites si l'on veut coller a un clavier
//                    particulier, mesurees puis mises a l'echelle.
//
// CONTRAINTE : somme des 7 talons + 5 x Wb = 7 x pitch_w, sinon les talons
// derivent par rapport aux faces avant (qui restent a pas egal). Verifie par echo.
tails = undef;
key_clr     = 0.8;     // garde autour des noires (creusée dans les blanches)

// SOLIDITE — l'acrylique est CASSANT : il ne se deforme pas, il fissure. Tout
// angle interne vif est une amorce de rupture, et la piece ne casse pas au
// montage mais des mois plus tard.
//   conge_r   : congé dans les angles internes des encoches (36.8 mm de
//               profondeur : c'est l'entaille la plus dangereuse du dessin)
//   arret_d   : TROU D'ARRET en fond de fente entre dents. Une fente terminee en
//               angle vif propage une fissure depuis son extremite ; un trou plus
//               large que la fente l'arrete. Technique d'atelier standard.
conge_r     = 1.2;
arret_d     = 2.4;     // diametre ; doit etre > gap_w pour servir a quelque chose

/* [Épaisseurs] */
t_blanches  = 10;      // guide de lumière
// 2026-08-21 : les noires ne sont plus une plaque rapportee mais un RELIEF DE
// 1 mm USINE dans la plaque acrylique de 1 mm. La valeur ci-dessous ne sert plus
// qu'a les rendre visibles en 3D.
t_noires    = 1;       // relief usine, pas une piece
t_pcb       = 1.6;
t_cache     = 2;

/* [PCB de tranche] */
pcb_h_blanc = 8;       // hauteur du PCB avant (dans les 10 mm du guide)
pcb_h_noir  = 3.5;     // hauteur du PCB arrière (moins large : plaque fine)
pcb_gap     = 1.0;     // jeu entre PCB et tranche (couplage LED)
led_size    = 3.5;     // SK6812 3535
led_h       = 1.6;
cache_ov    = 6;       // recouvrement du cache

/* [Repère] */
kb_x0 = 0;
kb_y0 = 0;

// ---------------- COULEURS ----------------
C_ACRYL = (vue_plan || coupe) ? [0.90, 0.93, 0.92] : [0.80, 0.88, 0.95, 0.35];
C_NOIR  = (vue_plan || coupe) ? [0.08, 0.08, 0.09] : [0.13, 0.13, 0.16, 0.92];
C_PCB   = [0.05, 0.35, 0.18];
C_LED   = [1.00, 0.75, 0.25];
C_CACHE = [0.22, 0.22, 0.24];

// ---------------- GÉOMÉTRIE PIANO ----------------
// Sur un piano les noires ne sont PAS sur la limite entre deux blanches.
// Dans le groupe do-ré-mi (3 blanches, 2 noires) les talons de blanche sont
// égaux entre eux ; dans le groupe fa-sol-la-si (4 blanches, 3 noires) ils le
// sont aussi, mais d'une AUTRE valeur. D'où l'irrégularité : do# est décalé à
// gauche de sa limite, ré# à droite, sol# tombe exactement dessus.
Wb   = black_ratio * pitch_w;
tal1 = (3*pitch_w - 2*Wb) / 3;
tal2 = (4*pitch_w - 3*Wb) / 4;
Ww   = pitch_w - gap_w;

// Talons effectivement utilises : table mesuree si fournie, sinon modele groupes
T = is_undef(tails) ? [tal1, tal1, tal1, tal2, tal2, tal2, tal2] : tails;
somme_T = T[0]+T[1]+T[2]+T[3]+T[4]+T[5]+T[6];
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

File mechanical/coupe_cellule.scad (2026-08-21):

// =====================================================================
//  NiDMI Seq — ASSEMBLAGE DU CLAVIER
//
//  Etat au 2026-08-21, apres la seance de conception. Cinq vues :
//    A — coupe en travers AVANT   : les blanches, traits de scie, gravure
//    B — coupe en travers ARRIERE : au droit d'une noire, LED par en dessous
//    C — coupe en long d'une blanche, jusqu'au ruban
//    D — vue de dessus du BLOC    : ce qui est usine et ou
//    E — le FILM a plat           : un seul ITO pour tout
//
//  Dessins de PRINCIPE, traces explicitement en 2D.
//  !! COUCHES MINCES EXAGEREES ; cotes reelles en regard.
//
//  ---- LES TROIS DECISIONS QUI STRUCTURENT TOUT ----------------------
//  1. PLAQUE CONTINUE d'acrylique par-dessus l'ITO, relief des noires USINE
//     dedans. Elle pince le film sur toute sa surface, protege l'electrode
//     partout, supprime la colle. Son epaisseur EST le parametre d'aftertouch.
//  2. UN SEUL FILM ITO pour les touches ET le ruban, grave d'un seul coup :
//     un seul calage, fige par le masque.
//  3. TROIS ECLAIRAGES INDEPENDANTS. Blanches par la tranche avant, en lumiere
//     guidee. Noires et ruban PAR EN DESSOUS, sur une meme carte horizontale.
//     Une LED couplee par l'AIR n'emet dans le PMMA qu'a +/-42 deg, exactement
//     l'angle critique : tout sort au premier contact, rien ne passe en mode
//     guide. D'ou l'isolement, et deux corollaires :
//        - NE RIEN COLLER sous ces LED (un indice ~1,5 ouvre le cone a 90 deg)
//        - SATINER LE DESSOUS DE LA PLAQUE, jamais la face inferieure du bloc.
// =====================================================================

etiquettes = true;
exag_mince = 20;

/* [Empilement — cotes reelles en mm] */
e_plaque = 1.0;    // PLAQUE ACRYLIQUE continue — la surface touchee
relief_n = 1.0;    // relief de la noire, USINE dans la plaque
e_pet    = 0.125;  // PET porteur du film
e_ito    = 0.05;   // ITO grave en motif
e_air    = 0.10;   // le film n'est plaque que par la plaque au-dessus
e_bloc   = 10.0;   // bloc PMMA — guide de lumiere des blanches
e_fond   = 0.05;   // fond sombre absorbant, FENETRE sous chaque noire
e_mousse = 3.0;    // LE RESSORT : pousse tout contre la levre du cadre
e_socle  = 2.0;    // socle rigide — c'est LUI la reference des LED

// !! LA CARTE LED EST POSEE SUR LE SOCLE, ET LA MOUSSE EST DECOUPEE POUR ELLE.
//    (rappele par l'utilisateur le 2026-08-21 ; ne pas le reperdre)
//    Consequences :
//      - la carte LED ne s'AJOUTE PAS a l'empilement : elle vit DANS l'epaisseur
//        de la mousse. Le clavier reste a e_plaque+...+e_mousse+e_socle.
//      - la mousse est le RESSORT : la decouper lui retire de la surface d'appui
//        la ou elle passe, c'est-a-dire sous les noires et sous le ruban. Il faut
//        donc verifier ce qui reste comme appui, et ou.
//      - carte (0,6-0,8 ENIG) + LED (SK6812 3535, ~1,9) = ~2,7 mm au-dessus du
//        socle, pour 3 mm de mousse : la LED affleure sous le bloc sans entrer
//        dans la poche. L'air est conserve — c'est ce qu'on veut (cone a +/-42 deg).
decoupe_mousse = true;   // la mousse est evidee au droit de la carte LED

/* [Decoupes du bloc] */
larg_coupe = 1.2;  // trait de scie entre blanches
p_scie     = 20;   // PROFONDEUR du trait : il s'arrete a 20 mm, donc il n'y a
                   // AUCUN trait sous les noires ni sous le ruban. Le bloc
                   // reste continu a l'arriere -> beaucoup plus solide.
poche_p    = 4.0;  // poche borgne sous la noire, PAR LE DESSOUS
poche_l    = 6.0;
p_grav     = 0.6;  // gravure d'extraction, face inferieure, blanches seulement

/* [Geometrie] */
pas_w      = 18.5;
larg_noire = 10.8;
n_pas      = 3;
L          = n_pas * pas_w;
Lk         = 52;   // longueur utile d'une blanche
Lb         = 32;   // longueur d'une noire, posee a l'arriere
dos        = 18;   // dos du peigne — porte le RUBAN
Lt         = Lk + dos;
ruban_l    = 10;

e_pcb = 1.6;  led_c = 3.5;  jeu_led = 1.0;

C_PMMA=[0.80,0.88,0.93]; C_PLQ=[0.86,0.91,0.95]; C_PET=[0.95,0.95,0.90];
C_ITO=[0.30,0.72,0.52];  C_ITO_N=[0.60,0.30,0.70]; C_NOIRE=[0.10,0.10,0.12];
C_FOND=[0.12,0.12,0.14]; C_MOUS=[0.75,0.65,0.55]; C_SOC=[0.45,0.47,0.50];
C_PCB=[0.05,0.35,0.18];  C_LED=[1.00,0.75,0.25];  C_TXT=[0.15,0.15,0.15];
C_RAY=[0.95,0.60,0.10];  C_SAT=[0.70,0.78,0.84];

function ep(e) = e < 0.5 ? e * exag_mince : e;

y_bloc_b = -e_bloc;
y_fond_b = y_bloc_b - ep(e_fond);
y_mou_b  = y_fond_b - e_mousse;
y_soc_b  = y_mou_b - e_socle;
y_ito_b  = ep(e_air);
y_pet_b  = y_ito_b + ep(e_ito);
y_plq_b  = y_pet_b + ep(e_pet);
y_plq_h  = y_plq_b + e_plaque;

module txt(p,s,t=1.6,al="left") color(C_TXT) translate(p) text(s,size=t,halign=al,valign="center");
module trait(a,b) color([0.55,0.55,0.58]) hull(){translate(a) circle(0.07,$fn=8); translate(b) circle(0.07,$fn=8);}
module rayon(a,b) color(C_RAY) hull(){translate(a) circle(0.07,$fn=8); translate(b) circle(0.07,$fn=8);}

// Empilement du dessous, commun aux coupes en travers
module dessous(x0, w, fenetre=[]) {
    difference() {
        color(C_FOND) translate([x0,y_fond_b]) square([w,ep(e_fond)]);
        for (f=fenetre) translate([f[0],y_fond_b-0.1]) square([f[1],ep(e_fond)+0.2]);
    }
    color(C_MOUS) translate([x0,y_mou_b]) square([w,e_mousse]);
    color(C_SOC)  translate([x0,y_soc_b]) square([w,e_socle]);
}

// ---------------------------------------------------------------- A
// COUPE EN TRAVERS, ZONE AVANT (moins de 20 mm du bord) : c'est la seule
// zone ou le bloc est fendu. Les blanches y sont des guides independants.
module coupe_avant() {
    color(C_PMMA) difference() {
        translate([0,y_bloc_b]) square([L,e_bloc]);
        for (i=[1:n_pas-1])
            translate([i*pas_w-larg_coupe/2, y_bloc_b-0.1]) square([larg_coupe, e_bloc+0.2]);
        for (x=[2:2.4:L-2]) translate([x,y_bloc_b]) circle(d=p_grav*1.6,$fn=16);
    }
    dessous(0, L);

    j = 2.0;
    for (i=[0:n_pas-1])
        color(C_ITO) translate([i*pas_w+j/2, y_ito_b]) square([pas_w-j, ep(e_ito)]);
    color(C_PET) translate([0,y_pet_b]) square([L, ep(e_pet)]);
    color(C_PLQ) translate([0,y_plq_b]) square([L, e_plaque]);

    if (etiquettes) {
        xr = L + 3;
        for (l = [
          [y_plq_b+e_plaque/2,   str("PLAQUE ACRYLIQUE  ", e_plaque, " mm — la surface touchee")],
          [y_pet_b+ep(e_pet)/2,  str("PET  ", e_pet, " mm")],
          [y_ito_b+ep(e_ito)/2,  "ITO grave — ilots d'electrodes ; la GARDE est la mer autour"],
          [y_ito_b/2,            "film d'air — la plaque plaque le film, il n'est pas colle"],
          [y_bloc_b+e_bloc/2,    str("bloc PMMA  ", e_bloc, " mm — guide, LED en tranche avant")],
          [y_fond_b+ep(e_fond)/2,"fond sombre — absorbe le halo non extrait"],
          [y_mou_b+e_mousse/2,   str("mousse  ", e_mousse, " mm — LE RESSORT (faible deformation remanente)")],
          [y_soc_b+e_socle/2,    str("socle  ", e_socle, " mm — reference rigide des LED")]
        ]) { trait([L,l[0]],[xr-0.8,l[0]]); txt([xr,l[0]],l[1]); }

        trait([pas_w,y_bloc_b],[pas_w,y_bloc_b-5]);
        txt([pas_w,y_bloc_b-9.5], str("trait de scie traversant — PLUS DE LAMELLE"),1.6,"center");
        txt([pas_w,y_bloc_b-11.7], "un trait sur quatre marque, pour le repere rythmique au doigt",1.6,"center");
        txt([0, y_plq_h+7], "A — COUPE EN TRAVERS, ZONE AVANT (moins de 20 mm du bord)", 2.6);
        txt([0, y_plq_h+3.6], "la seule zone ou le bloc est fendu ; ici la plaque est plate", 1.6);
    }
}

// ---------------------------------------------------------------- B
// COUPE EN TRAVERS, ZONE ARRIERE, AU DROIT D'UNE NOIRE.
// Le trait de scie s'est arrete a 20 mm : le bloc est CONTINU ici. Rien ne
// coupe la tache de la LED, et le relief de la noire est usine dans la plaque.
module coupe_arriere() {
    x_n  = pas_w - larg_noire/2;
    x_po = pas_w - poche_l/2;
    color(C_PMMA) difference() {
        translate([0,y_bloc_b]) square([L,e_bloc]);
        translate([x_po, y_bloc_b-0.1]) square([poche_l, poche_p+0.1]);
        for (x=[2:2.4:L-2])
            if (x < x_po-2 || x > x_po+poche_l+2)
                translate([x,y_bloc_b]) circle(d=p_grav*1.6,$fn=16);
    }
    dessous(0, L, [[x_po, poche_l]]);
    // la mousse est evidee pour laisser passer la carte : appui sur le SOCLE
    color(C_SOC) translate([0,y_soc_b]) square([L,e_socle]);
    color(C_PCB) translate([x_po-3, y_mou_b]) square([poche_l+6, e_pcb]);
    y_led = y_bloc_b + poche_p - led_c/2 - 0.3;
    color(C_LED) translate([pas_w-led_c/2, y_led]) square([led_c, led_c*0.55]);

    // le cone est limite a +/-42 deg : tout sort au premier contact
    for (s=[-1,1]) rayon([pas_w, y_led+led_c*0.55], [pas_w + s*0.906*(poche_p==0?e_bloc:(e_bloc-poche_p)), 0]);
    rayon([pas_w, y_led+led_c*0.55],[pas_w, 0]);
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

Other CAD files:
mechanical/facade.scad
mechanical/implantation.scad
mechanical/optique_cloison.scad

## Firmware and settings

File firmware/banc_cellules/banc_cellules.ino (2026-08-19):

// Banc "cellule complete" : 4 canaux tactiles + 4 LED appairees (touche N <-> LED N).
// Cible ESP32-S3. Sortie CSV compatible avec scripts/touch_scope.py et touch_log.py.
//
//   CABLAGE
//     electrodes ITO -> GPIO 8, 9, 10, 12   (seuls canaux touch valides sur cette
//                                            carte ; cf. firmware/scan_touch)
//     LED n :  GPIO 15/16/17/18 --[ 100 ohm ]--> anode ; cathode --> GND commun
//
//   Les LED ORANGES/ROUGES/VERTES traditionnelles (seuil ~2 V) se pilotent ainsi
//   directement : (3,3 - 2,0) / 100 = ~13 mA, dans les clous du GPIO.
//   Une BLEUE ou une BLANCHE (seuil ~3 V) n'y arriverait pas : il ne resterait que
//   ~2 mA. Pour celles-la il faut le rail 5 V et un montage ou le GPIO tire le
//   courant (5 V --[R]-- anode [LED] cathode -- GPIO, logique inversee).
//
//   SORTIE SERIE (115200)
//     "# ..."                     entete et evenements
//     "t_ms,ch,raw,delta,snr"     une ligne par canal, ~10 fois par seconde
//
//   COMMANDES (un caractere, sauf la luminosite)
//     b  recalibrer la ligne de base (main eloignee)
//     i  reimprimer l'entete canal->GPIO (sans toucher a la ligne de base)
//     f  LED en FIXE          r  LED en RAMPE 5 s      c  LED en CLIGNOTEMENT
//     t  LED REACTIVES AU TOUCHER (LED n suit la touche n)
//     x  LED eteintes         h  aide
//     L<0-255> + retour ligne : luminosite maximale (ex. "L128")

#include "soc/soc_caps.h"

#if SOC_TOUCH_SENSOR_VERSION == 2   // ESP32-S3 / S2 : la valeur MONTE au toucher
  static const int TOUCH_SIGN = +1;
#else                               // ESP32 classique : elle DESCEND
  static const int TOUCH_SIGN = -1;
#endif

static const uint8_t PINS_TOUCH[] = {8, 9, 10, 12};
static const uint8_t PINS_LED[]   = {15, 16, 17, 18};
static const int     NCH          = sizeof(PINS_TOUCH) / sizeof(PINS_TOUCH[0]);

static const uint32_t CHG_TIMES  = 500;
static const int      OVERSAMPLE = 16;
static const int      BASE_N     = 200;
static const uint32_t WARMUP_MS  = 2000;
static const uint32_t PERIOD_MS  = 100;    // cadence d'emission du CSV
static const uint32_t RAMPE_MS   = 5000;   // periode complete de la rampe
static const uint32_t CLIGN_MS   = 600;    // periode du clignotement

// Seuil de detection, exprime en POURCENTAGE DE LA LIGNE DE BASE.
//
// Un seuil en counts absolus ne marche pas ici : le contact vaut +425 % de la base
// dans le cas defavorable (operateur flottant) et jusqu'a +4000 % relie a la masse,
// alors que le bruit vaut quelques dizaines de counts. Un seuil calé sur le bruit
// (8 sigma ~ 280 counts, soit 0,7 % de la base) est franchi par la derive thermique
// et par une main qui passe a 20 cm — l'electrode detecte la PROXIMITE bien avant
// le contact. En relatif, contact et approche se separent sans ambiguite.
// Reglable par "S<n>", n en DIXIEMES DE POUR CENT (S50 = 5 %). Le dixieme de %
// est necessaire : toute la discrimination entre contact et approche se joue
// sous 10 % de la base, un pas de 1 % n'y laisserait que dix positions utiles.
static float SEUIL_PCT = 0.05f;            // 5 % de la base
static const float SEUIL_SIGMA = 8.0f;     // plancher de bruit, jamais dominant
static const float SEUIL_MINI  = 150.0f;
static const float HYSTERESIS  = 0.6f;     // relachement a 60 % du seuil

// Suivi de ligne de base. La base derive en permanence avec la TEMPERATURE et
// l'HYGROMETRIE : sur quelques heures l'ecart depasse largement le bruit, et un
// seuil calcule une fois pour toutes finit par declencher tout seul. On reajuste
// donc la base en continu, avec une constante de temps longue (~60 s), et
// UNIQUEMENT quand le canal n'est pas touche — sinon un doigt maintenu serait
// absorbe dans la base et la touche se relacherait d'elle-meme.
static const float    TRACK_ALPHA = 0.0017f;   // ~60 s a 10 mesures/s
// Un contact tres long peut signifier que la base a ete prise alors qu'un objet
// etait a proximite — mais sur un instrument il peut tout aussi bien s'agir d'une
// NOTE TENUE, d'une pedale ou d'un bourdon. On se contente donc de SIGNALER, une
// seule fois, sans jamais relacher : une note qui s'arrete toute seule est bien
// pire qu'un avertissement, et un re-etalonnage automatique absorberait la valeur
// touchee dans la base, faussant la detection au relachement.
static const uint32_t BLOQUE_MS   = 60000;

enum ModeLed { LED_ETEINT, LED_FIXE, LED_RAMPE, LED_CLIGNOTE, LED_TACTILE };
static ModeLed mode       = LED_TACTILE;
static uint8_t luminosite = 200;

static float    base[NCH], sigma[NCH], seuil[NCH];
static bool     touche[NCH];
static uint32_t debutTouche[NCH];
static bool     signale[NCH];       // avertissement "contact tres long" deja emis

static void printMeta();

static float readAvg(uint8_t pin) {
  uint32_t acc = 0;
  for (int i = 0; i < OVERSAMPLE; i++) acc += touchRead(pin);
  return (float)acc / OVERSAMPLE;
}

// La calibration bloque la boucle ~7 s. Sans signal visuel, les LED restent
// figees dans leur dernier etat et l'utilisateur croit que la commande n'a rien
// fait. On les fait donc clignoter ensemble pendant toute l'operation : c'est un
// motif qu'aucun mode normal ne produit.
static void ledsOccupees() {
  uint8_t v = (millis() / 200) % 2 ? luminosite / 3 : 0;
  for (int c = 0; c < NCH; c++) analogWrite(PINS_LED[c], v);
}

static void calibrate() {
  Serial.println(F("# prechauffage... (LED clignotantes = calibration en cours)"));
  for (int c = 0; c < NCH; c++) analogWrite(PINS_LED[c], 0);
  uint32_t tw = millis();
  while (millis() - tw < WARMUP_MS) {
    for (int c = 0; c < NCH; c++) (void)readAvg(PINS_TOUCH[c]);
    ledsOccupees();
    delay(5);
  }
  Serial.println(F("# calibration : NE PAS TOUCHER — ni electrodes, ni pinces, ni fils"));
  for (int c = 0; c < NCH; c++) {
    double s = 0, s2 = 0;
    for (int i = 0; i < BASE_N; i++) {
      float v = readAvg(PINS_TOUCH[c]);
      s += v; s2 += (double)v * v;
      ledsOccupees();
      delay(2);
    }
    base[c] = s / BASE_N;
    double var = s2 / BASE_N - (double)base[c] * base[c];
    sigma[c] = var > 0.25 ? sqrt(var) : 0.5f;
    seuil[c] = max(max(SEUIL_PCT * base[c], SEUIL_SIGMA * sigma[c]), SEUIL_MINI);
    touche[c] = false;
    debutTouche[c] = 0;
    signale[c] = false;
  }
  for (int c = 0; c < NCH; c++) analogWrite(PINS_LED[c], 0);
  Serial.println(F("# calibration terminee"));
  printMeta();
}

static void printMeta() {
  Serial.println(F("# ch,gpio,base,sigma"));
  bool sature = false;
  for (int c = 0; c < NCH; c++) {
    Serial.printf("# %d,%u,%.1f,%.2f\n", c, PINS_TOUCH[c], base[c], sigma[c]);
    if (base[c] >= 4194303.0f - 1.0f) sature = true;
  }
  Serial.printf("# seuil = %.2f %% de la base\n", SEUIL_PCT * 100.0f);
  for (int c = 0; c < NCH; c++)
    Serial.printf("# seuil ch%d = %.0f counts (LED %u)\n", c, seuil[c], PINS_LED[c]);
  if (sature) {
    Serial.println(F("# !! canal sature (0x3FFFFF) : la mesure n'aboutit pas."));
    Serial.println(F("#    -> electrode absente, broche tiree, ou canal non valide."));
  }
  Serial.println(F("# t_ms,ch,raw,delta,snr"));
}

// Recalcule les seuils depuis les bases deja mesurees : pas besoin de refaire une
// calibration pour changer la sensibilite en cours d'essai.
static void majSeuils() {
  for (int c = 0; c < NCH; c++) {
    seuil[c] = max(max(SEUIL_PCT * base[c], SEUIL_SIGMA * sigma[c]), SEUIL_MINI);
    touche[c] = false;
  }
  Serial.printf("# seuil = %.2f %% de la base\n", SEUIL_PCT * 100.0f);
  for (int c = 0; c < NCH; c++)
    Serial.printf("# seuil ch%d = %.0f counts\n", c, seuil[c]);
}

static void aide() {
  Serial.println(F("# b=recalibrer  i=entete  h=aide"));
  Serial.println(F("# LED : f=fixe  r=rampe 5s  c=clignote  t=tactile  x=eteint"));
  Serial.println(F("# luminosite : L0..L255 suivi d'un retour ligne (ex. L128)"));
  Serial.println(F("# seuil      : S1..S2000 = DIXIEMES de % de la base (S50 = 5 %)"));
  Serial.println(F("#   plancher : le seuil ne descend jamais sous max(8 sigma, 150"));
  Serial.println(F("#   counts) — en dessous, le curseur n'a plus d'effet"));
  Serial.println(F("# la ligne de base suit les derives (temperature, hygrometrie),"));
  Serial.println(F("# sauf pendant un contact : une note tenue n'est JAMAIS relachee"));
  Serial.println(F("# d'office — un contact > 60 s est seulement signale"));
}

// Niveau commun aux LED non tactiles, calcule sur l'horloge : aucun delay, la
// boucle doit rester libre pour echantillonner le tactile.
static uint8_t niveauCommun() {
  uint32_t t = millis();
  switch (mode) {
    case LED_FIXE:  return luminosite;
    case LED_RAMPE: {                       // triangle : montee puis descente
      uint32_t p = t % RAMPE_MS;
      uint32_t demi = RAMPE_MS / 2;
      uint32_t v = (p < demi) ? p : (RAMPE_MS - p);
      return (uint32_t)luminosite * v / demi;
    }
    case LED_CLIGNOTE: return (t % CLIGN_MS) < (CLIGN_MS / 2) ? luminosite : 0;
    default: return 0;
  }
}

static void majLeds() {
  if (mode == LED_TACTILE) {
    for (int c = 0; c < NCH; c++) analogWrite(PINS_LED[c], touche[c] ? luminosite : 0);
  } else {
    uint8_t v = niveauCommun();
    for (int c = 0; c < NCH; c++) analogWrite(PINS_LED[c], v);
  }
}

static void nommerMode() {
  const char *n = mode == LED_FIXE     ? "fixe"
                : mode == LED_RAMPE    ? "rampe 5 s"
                : mode == LED_CLIGNOTE ? "clignotement"
                : mode == LED_TACTILE  ? "tactile (LED n suit touche n)"
                                       : "eteint";
  Serial.printf("# mode LED : %s, luminosite %u\n", n, luminosite);
}

// "L128\n" -> luminosite 128. Accumule les chiffres jusqu'au retour ligne.
static void lireCommandes() {
  static char quoi   = 0;              // 'L' luminosite, 'S' seuil, 0 = aucun
  static int  valeur = 0;
  while (Serial.available()) {
    int c = Serial.read();
    if (quoi) {
      if (c >= '0' && c <= '9') { valeur = min(valeur * 10 + (c - '0'), 9999); continue; }
      if (quoi == 'L') { luminosite = (uint8_t)min(valeur, 255); nommerMode(); }
      else             { SEUIL_PCT = constrain(valeur, 1, 2000) / 1000.0f; majSeuils(); }
      quoi = 0;
      continue;                        // le caractere de fin est consomme
    }
    switch (c) {
      case 'L': case 'l': quoi = 'L'; valeur = 0; break;
      case 'S': quoi = 'S'; valeur = 0; break;
      case 'b': case 'B': calibrate();                  break;
      case 'i': case 'I': printMeta();                  break;
      case 'h': case 'H': aide();                       break;
      case 'f': case 'F': mode = LED_FIXE;     nommerMode(); break;
      case 'r': case 'R': mode = LED_RAMPE;    nommerMode(); break;
      case 'c': case 'C': mode = LED_CLIGNOTE; nommerMode(); break;
      case 't': case 'T': mode = LED_TACTILE;  nommerMode(); break;
      case 'x': case 'X': mode = LED_ETEINT;   nommerMode(); break;
      default: break;
    }
  }
}

void setup() {
  Serial.begin(115200);
  delay(400);
  Serial.println(F("\n# --- banc cellules : 4 touch + 4 LED ---"));
#if SOC_TOUCH_SENSOR_VERSION == 2
  Serial.println(F("# touch v2 (S2/S3) : valeur croissante au toucher"));
  touchSetConfig(CHG_TIMES, TOUCH_VOLT_LIM_L_0V5, TOUCH_VOLT_LIM_H_2V2);
#else
  Serial.println(F("# touch v1 (ESP32) : valeur decroissante au toucher"));
#endif
  for (int c = 0; c < NCH; c++) { pinMode(PINS_LED[c], OUTPUT); analogWrite(PINS_LED[c], 0); }
  aide();
  calibrate();
  nommerMode();
}

void loop() {
  lireCommandes();
  majLeds();                       // rafraichi a chaque tour : rampe fluide

  static uint32_t dernier = 0;
  if (millis() - dernier < PERIOD_MS) { delay(2); return; }
  dernier = millis();

  uint32_t t = millis();
  for (int c = 0; c < NCH; c++) {
    float raw   = readAvg(PINS_TOUCH[c]);
    float delta = TOUCH_SIGN * (raw - base[c]);

    // Hysteresis : on declenche au seuil, on relache plus bas, pour eviter le
    // battement quand le doigt effleure la limite.
    bool avant = touche[c];
    if (!touche[c] && delta > seuil[c])                 touche[c] = true;
    else if (touche[c] && delta < seuil[c] * HYSTERESIS) touche[c] = false;
    if (touche[c] != avant) {
      if (touche[c]) { debutTouche[c] = t; signale[c] = false; }
      Serial.printf("# ch%d %s\n", c, touche[c] ? "TOUCHE" : "relache");
    }

    if (!touche[c]) {
      // Derive lente absorbee ; le seuil suit la base puisqu'il en est un %.
      base[c] += (raw - base[c]) * TRACK_ALPHA;
      seuil[c] = max(max(SEUIL_PCT * base[c], SEUIL_SIGMA * sigma[c]), SEUIL_MINI);
    } else if (!signale[c] && t - debutTouche[c] > BLOQUE_MS) {
      // On SIGNALE seulement : ce peut etre une note tenue tout a fait legitime.
      signale[c] = true;
      Serial.printf("# ch%d touche depuis %lu s — note tenue, ou base prise pres "
                    "d'un objet ? recalibrer (b) si le canal semble bloque\n",
                    c, (unsigned long)(BLOQUE_MS / 1000));
    }

    Serial.printf("%lu,%d,%.1f,%.1f,%.1f\n", t, c, raw, delta, delta / sigma[c]);
  }
}

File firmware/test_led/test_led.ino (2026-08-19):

// Banc d'identification de LED inconnues (ESP32-S3).
//
// MODE AUTO AU DEMARRAGE : la sequence tourne en boucle sans rien demander, pour
// pouvoir recabler / ressouder / retourner la LED en regardant le resultat en
// direct. C'est le mode a utiliser tant qu'on ne sait pas ce qu'on a.
//
//   CABLAGE DU MODE AUTO — la LED se met ENTRE LES DEUX BROCHES :
//
//       GPIO15 ---[ resistance 100-220 ohm ]---[ LED ]--- GPIO17
//
//   Rien a la masse, rien au 3V3. Le banc alterne le sens en permanence :
//   la LED s'allume forcement dans une des deux phases, DANS N'IMPORTE QUEL SENS.
//   Plus de question de polarite — et le serie annonce quelle phase eclaire,
//   ce qui donne l'anode.
//
// Commandes serie (115200), si on veut sortir de l'auto :
//   s = ALLUMAGE FIXE (pour observer une diffusion) : appuis successifs =
//       sens 1 -> sens 2 -> eteint. C'est le mode a utiliser des que la LED est
//       identifiee et qu'on veut regarder la lumiere, pas la faire clignoter.
//   m = SONDE Vf : mesure en continu la tension de seuil de la LED touchee, et
//       annonce la famille de couleur. Sert a TRIER un lot de LED inconnues.
//
//       CABLAGE DE LA SONDE :
//           GPIO15 ---[ 100 ohm ]---+--- pointe 1 --> anode LED
//                                   |
//                                 GPIO3 (mesure)      cathode LED --> GND (pointe 2)
//
//       Le seuil depend de la chimie de la puce, donc de la couleur :
//         ~1,8-2,2 V  rouge          ~2,2-2,6 V  jaune / vert traditionnel
//         ~2,7-3,1 V  BLEU, BLANC, vert InGaN (meme puce bleue ; l'oeil separe
//                     le blanc du bleu, le phosphore faisant le reste)
//       LED a l'envers ou pointe qui ne touche pas = circuit ouvert = ~3,3 V.
//
//   a = revenir au mode auto (defaut)
//   1 = LED simple, rampe sur PIN_SIMPLE (anode via resistance, cathode a GND)
//   2 = adressable SK6812/WS2812 sur PIN_DATA (VDD 5 V, masse commune)
//   3 = RGB 4 pattes, un canal a la fois
//   0 = tout eteindre        h = aide
//
// Reconnaitre une LED a 2 pattes, en mode auto :
//   Les deux sens ont une signature visuelle : sens 1 = UN ECLAIR LONG (anode du
//   cote GPIO15), sens 2 = TROIS CLIGNOTEMENTS COURTS (anode du cote GPIO17).
//   Le motif qui allume la LED donne donc directement le sens, sans port serie.
//
//   - allumee dans UNE SEULE phase, couleur fixe ....... monochrome
//   - allumee dans LES DEUX phases, couleur differente . bicolore antiparallele
//   - allumee et changeant de couleur TOUTE SEULE ...... RGB auto-clignotante
//     (un CI est integre, la sequence est figee, il n'y a rien a piloter)
//   - rien dans aucune phase .......................... continuite a verifier
//     AVANT de suspecter la LED : resistance et deux liaisons a l'ohmmetre.
//     Ces boitiers minuscules se soudent mal sur du fil volant.
//
// !! Tension selon la couleur. Rouge/jaune/vert traditionnel : seuil ~2 V, 3,3 V
//    suffit. Blanche/bleue/verte InGaN : seuil ~3,0-3,2 V — en 3,3 V il ne reste
//    presque rien aux bornes de la resistance, la LED reste quasi eteinte et on
//    croit a tort qu'elle est morte. Pour celles-la, passer au 5 V.

// Broches libres : 4/5 = I2C, 8/9/10/12 = electrodes touch, 19/20 = USB.
static const uint8_t PIN_A      = 15;   // mode auto + bicolore : un cote de la LED
static const uint8_t PIN_B      = 17;   // mode auto + bicolore : l'autre cote
static const uint8_t PIN_SIMPLE = 15;   // mode 1 : anode via resistance
static const uint8_t PIN_DATA   = 16;   // mode 2 : DIN adressable
static const uint8_t PIN_R = 15, PIN_G = 16, PIN_BL = 17;   // mode 3
static const uint8_t PIN_MESURE = 3;    // mode m : ADC1, broche libre sur la carte
static bool sonde = false;

static const bool RGB_CATHODE_COMMUNE = true;

// Mode par defaut : lumiere continue, sens indifferent — c'est celui qui sert a
// TRIER un lot a l'oeil. L'alternance rapide (4 ms) fait que la LED est allumee
// la moitie du temps quel que soit son sens de branchement, et l'oeil la voit fixe.
static bool modeCouleur = false;
static bool autoMode = true;
static uint8_t fixe = 0;   // 0 = eteint, 1 = sens 1, 2 = sens 2

static void aide() {
  Serial.println(F("\n--- banc LED ---"));
  Serial.println(F("CABLAGE AUTO : GPIO15 --[100-220 ohm]--[LED]-- GPIO17"));
  Serial.println(F("               rien a la masse ; le sens n'a pas d'importance"));
  Serial.println(F("c = COULEUR : lumiere continue, sens indifferent — pour trier un lot"));
  Serial.println(F("a = SENS/POLARITE (defaut) : eclair long = anode cote GPIO15,"));
  Serial.println(F("                    3 clignotements = anode cote GPIO17"));
  Serial.println(F("s = allumage FIXE   0 = eteindre   h = aide"));
  Serial.println(F("m = sonde Vf (tri d'un lot) : 15 --[100 ohm]--+-- anode ; GPIO3 sur le +"));
  Serial.println(F("1 = LED simple sur 15    2 = adressable sur 16   3 = RGB 4 pattes"));
}

static void toutEteindre() {
  for (uint8_t p : {PIN_A, PIN_B, PIN_DATA, PIN_G}) {
    pinMode(p, OUTPUT);
    digitalWrite(p, LOW);
  }
  neopixelWrite(PIN_DATA, 0, 0, 0);
}

// Une phase : `haut` a 3,3 V, `bas` a 0 -> le courant va de `haut` vers `bas`.
// Les deux sens ont une SIGNATURE VISUELLE differente, pour qu'on lise l'anode
// sans avoir besoin du port serie :
//   sens 1 = UN ECLAIR LONG        -> anode du cote GPIO15
//   sens 2 = TROIS CLIGNOTEMENTS   -> anode du cote GPIO17
static void phase(uint8_t haut, uint8_t bas, int impulsions, int duree) {
  pinMode(haut, OUTPUT);
  pinMode(bas, OUTPUT);
  digitalWrite(bas, LOW);
  for (int i = 0; i < impulsions; i++) {
    digitalWrite(haut, HIGH);
    delay(duree);
    digitalWrite(haut, LOW);
    if (i + 1 < impulsions) delay(duree);
  }
}

// Allumage continu pleine puissance, pour observer une diffusion.
static void allumageFixe() {
  fixe = (fixe + 1) % 3;
  autoMode = false;
  pinMode(PIN_A, OUTPUT);
  pinMode(PIN_B, OUTPUT);
  if (fixe == 0) {
    digitalWrite(PIN_A, LOW); digitalWrite(PIN_B, LOW);
    Serial.println(F("fixe : eteint"));
  } else if (fixe == 1) {
    digitalWrite(PIN_A, HIGH); digitalWrite(PIN_B, LOW);
    Serial.println(F("fixe : sens 1 (GPIO15 -> GPIO17)"));
  } else {
    digitalWrite(PIN_A, LOW); digitalWrite(PIN_B, HIGH);
    Serial.println(F("fixe : sens 2 (GPIO17 -> GPIO15)"));
  }
  Serial.println(F("  bleue/blanche faiblarde ? c'est le seuil ~3 V : passer au 5 V"));
  Serial.println(F("  (5 V --[100 ohm]-- anode [LED] cathode -- GND, sans GPIO)"));
}

// Nomme la famille de couleur d'apres la tension de seuil mesuree.
static const char *famille(int mv) {
  if (mv > 3150) return "rien (circuit ouvert, LED a l'envers, ou pointe qui ne touche pas)";
  if (mv > 2650) return "BLEU / BLANC / vert InGaN";
  if (mv > 2250) return "jaune / vert traditionnel";
  if (mv > 1550) return "ROUGE";
  if (mv > 300)  return "infrarouge, ou LED speciale";
  return "court-circuit";
}
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

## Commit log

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2026-06-13 Méca : modèle 3D paramétrique de la façade (OpenSCAD)
    Empilement plexi + grille espaceur (puits de lumière) + PCB (anneaux
    capacitifs + SK6812 centrale). Vues éclatée/assemblée/dessus rendues.
    Layout : écran 3,2″, 4 encodeurs, grille 4×4, rangées fonctions/transport.
    [facade.scad]
2026-06-13 Méca : façade refondue sur la VISION (clavier piano) + côtes paramétriques
    - Layout = surface de contrôle VISION (VST §3) : clavier PIANO 27 touches
    (16 blanches notchées + 11 noires), 5 encodeurs, 8 boutons, écran 3,2".
    Remplace l'hypothèse 4x4 (hors-sujet ergo).
    - Côtes paramétriques (module cote_h/cote_v) auto-lues des variables,
    rendues au-dessus du modèle (W, H, clavier, blanche/pitch, noire, écran, enc).
    - Façade calculée ~368x160 mm (format clavier large).
    [facade.scad]
2026-06-13 Écran re-figé : 4,0" 480×320 ILI9488 SPI (module commerce simple)
    Remplace le 3,2" 320×240. 480×320 dépasse la cible cahier (320×240) ;
    4,0" = pixels plus gros que 3,5" → plus lisible. Connectique SPI ~6 fils,
    piloté directement par le cerveau (pas de puce écran dédiée). Tactile XPT2046
    du module non utilisé (écran non tactile). 800×480 RGB écarté (FPC/RGB trop
    complexe vs dispo magasin). Maj ARCHITECTURE.md, VARIANTE_CAPACITIVE.md, modèle
    (écran paysage 85×56).
    [facade.scad]
2026-06-13 Méca : boutons fonction mécaniques (PB86) + ruban capacitif
    - 8 boutons de fonction = mécaniques traversants (PB86, Ø12) au lieu de pads
    capacitifs → clic sur transport, libère le budget canaux capacitifs.
    - Ajout ruban capacitif (slider tactile natif ESP32-S3) au-dessus du clavier,
    paramétrique (longueur/position). Seules les 27 touches + ruban restent
    capacitifs (~32 canaux / 42 dispo).
    - Façade H 160→172 pour la bande ruban. Côte ruban ajoutée.
    [facade.scad]
2026-06-13 Méca : corrige les boutons fonction → tact carré illuminé (Option 1)
    Erreur précédente (PB86 ronds). Les boutons convenus (ETUDE_PRIX_TOUCHES
    Option 1, décidée 2026-06) = tact switch carré 12×12 THT + cap translucide
    + LED WS2811 RGB (bus 1-fil). Modélisés en caps carrés translucides illuminés,
    mécaniques, traversant le plexi. +8 RGB sur le bus LED.
    [facade.scad]
2026-06-13 Méca : boutons fonction = PB86 réels (corps 12×17, cap illuminé)
    Le PB86 (réf A0/A1/A2) est un poussoir corps rectangulaire 12×17 mm PCB-mount
    4 broches, cap translucide, LED intégrée mono/bi-couleur (pas RGB, hors bus
    SK6812). Modélisés en caps 12×17 illuminés traversant le plexi. Corrige les
    deux essais précédents (rond générique puis carré 12×12 RGB).
    [facade.scad]
2026-06-13 Méca : blanches 20→17 mm (clavier 296, façade W=320)
    -3 mm de largeur sur les touches blanches (capacitif piano). Pitch 18,5.
    Façade resserrée à 320 mm. Ruban et reste inchangés.
    [facade.scad]
2026-06-13 Méca : boîtier 3D (parois + fond + connecteurs, profondeur ~31 mm)
    Ajout layer_box() paramétrique : parois box_wall, cavité box_cavity=22 mm
    sous le PCB (modules ESP32 + connecteurs), fond, perçages USB-C + 2× MIDI TRS
    sur la tranche arrière. Gate show_box. Vue boîtier fermé + commande README.
    [facade.scad]
2026-06-13 Méca : connectique tranche arrière (USB-C, MIDI IN/OUT, CV/GATE/CLK/RST)
    7 connecteurs : USB-C (alim+USB-MIDI+flash) + MIDI IN/OUT + CV GATE CLK RST
    (6 jacks 3,5 mm). Vue arrière dédiée. CV/gate = ajout analogique (implique
    un DAC pour le CV + GPIO pour gate/clock/reset, à intégrer côté archi).
    [facade.scad]
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2026-06-13 Méca : re-layout avec le vrai module écran (PCB 108×62 / actif 84×56)
    Écran figé ILI9488 4,0". Modèle : footprint PCB 108×62 derrière + fenêtre
    active 84×56 (cutout plexi) centrée. Contrôles reculés à droite du PCB,
    enc pitch 40→33, boutons 24→20 → tout tient en W=320. Côtes PCB+actif.
    BOM : écran ILI9488 figé, implication boîtier résolue.
    [facade.scad]
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2026-06-13 Méca : profondeur recalée sur cotes réelles (~25 mm) + vues à jour
    Entrefer avant 3→7 mm (dégage le corps EC11 ~6,5 + PB86 + écran) ; cavité
    sous PCB 22→12 mm (3× ESP32 + connecteurs PJ-320A board-edge). Profondeur
    totale ~25 mm. Conséquence actée : 2 PCB (électrodes capacitives près du
    plexi + PCB principal en bas). cap PB86 13 mm. Vues éclatée/boîtier/profil
    régénérées (layout écran 108×62, ruban, PB86 12×17).
    [facade.scad]
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2026-06-14 Méca : interrupteurs d'affichage par couche (show_pcb/spacer/plexi/box)
    Section Customizer [Affichage] : cases à cocher pour masquer chaque couche
    et mieux voir les détails. Assemblage conditionné par les booléens.
    [facade.scad]
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2026-06-14 Méca : coupe d'une cellule touche dans le plexi épais (étude)
    cellule_plexi.scad : électrode cuivre au fond d'une poche fraisée au dos,
    membrane avant 1,5 mm, LED centrale, rainure câblage. Plexi 10 mm. Vue en
    coupe paramétrique (cut/show_dims) pour valider les épaisseurs.
    [cellule_plexi.scad]
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2026-06-26 Méca : variante électrode ITO pleine surface (cellule_plexi paramétrique)
    cellule_plexi.scad devient paramétrique via elec_mode :
    - "ring" : anneau cuivre + trou central (LED par le trou) — comportement actuel.
    - "ito" : film ITO transparent PLEINE surface, membrane pleine (LED traverse
    l'électrode, pas de hot-spot central) + languette de contact.
    Rendus cellule.png (anneau) + cellule_ito.png (ITO), README à jour.
    [cellule_plexi.scad]
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2026-08-15 BOM : la conception demande un sixieme encodeur
    nidmi-seq-vst/CONCEPTION.md §2 donne une molette dediee a chacun des deux niveaux
    de navigation, Row et Pas, qui ne sont jamais pretees. Sans elles, changer de
    niveau demandait un raccourci a deux mains pour un geste constant en composition.
    Electriquement acquis : PCNT offre 4 unites par puce et les encodeurs sont
    repartis sur deux ESP32, soit 8 places pour 6 — repartition a recalculer en
    B(3)/C(3) au lieu de B(3)/C(2).
    Mecaniquement a recaler, et c'est le seul point ouvert : le pas de 33 mm entre
    encodeurs sur une facade de 320 mm, et la fenetre plexi.
    La BOM cesse donc d'etre entierement figee : le point est marque en rouge plutot
    que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
2026-08-20 Étude LED : guide de lumière à éclairage latéral (gravure au dos)
    LED sur la tranche, propagation par réflexion totale interne, gravure Dremel
    comme structure d'extraction. Gravure au DOS meilleure qu'en face avant : la
    face avant reste lisse donc la réflexion totale y est préservée, et le halo se
    regarde à travers de l'acrylique poli.
    - Cross-talk optique faible : une gravure s'allume en face de sa LED, presque
    pas à côté. Répond à l'une des deux contraintes qui fixent le pas du clavier.
    - La gravure masque l'électrode -> l'impression en seconde surface prévue pour
    cacher le bus bar devient inutile.
    - Tension à mesurer : plaquer l'ITO contre la face arrière met le gu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
2026-08-20 Méca : clavier piano paramétrique, géométrie de facteur (irrégulière)
    facade.scad plaçait les noires sur la limite entre deux blanches — ce n'est pas
    un clavier de piano. Nouveau modèle dédié avec la vraie géométrie.
    Modèle : dans le groupe do-ré-mi (3 blanches, 2 noires) les talons de blanche
    sont égaux entre eux ; dans le groupe fa-sol-la-si (4 blanches, 3 noires) ils le
    sont aussi, mais d'une autre valeur. D'où les décalages par rapport à la ligne
    de pas : -1,25 / +1,25 pour do# et ré#, -1,87 / 0 / +1,87 pour fa#, sol# et la#.
    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
    [clavier_piano.scad]
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2026-08-20 Méca : vues lisibles du clavier + caches en L (bug) + noires élargies
    - vue_plan : rendu à plat opaque, seul moyen de vérifier les proportions à
    l'oeil en comparant à un vrai clavier. Les rendus précédents étaient en
    acrylique translucide, illisibles.
    - Caches refaits en PROFIL EN L (mur vertical devant le PCB + lèvre par-dessus
    les touches). Ils étaient modélisés en blocs pleins, occupant le volume des
    touches et les masquant — défaut révélé en cherchant à les visualiser.
    - Vues dédiées clavier_pcb.png (caches masqués, PCB de tranche visibles) et
    clavier_assemble.png : assemblés, les caches cachent les PCB, c'est leur rôle,
    donc aucune vue unique ne mont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
    [clavier_piano.scad]
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2026-08-20 Méca : cotes de piano sourcées + vues par plaque + estimation de découpe
    Cotes vérifiées sur références plutôt que déduites (mathpages, quadibloc,
    PianoReport) :
    - blanche 23,5 mm, noire 13,7 mm A LA BASE -> black_ratio 0,583. La noire est
    tronconique (~9,5 au sommet) ; sur une façade plate c'est la base qui fait la
    largeur apparente.
    - Talons : des talons tous égaux sont mathématiquement impossibles (3W=3w+2B et
    4W=4w+3B n'ont de solution commune que pour B=0). L'optimum des facteurs est
    W-2B/3 pour do-ré-mi et W-3B/4 pour fa-sol-la-si, écart B/12 — c'est ce que le
    modèle faisait déjà. La "correction" du commit précédent était fausse.
    Nouveau paramètre `pie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
    [clavier_piano.scad]
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2026-08-20 Méca : retour au bloc plein — l'électrode sépare les touches, pas la matière
    Erreur corrigée : le plexi était découpé sous les noires « pour séparer les
    électrodes ». Sur un clavier capacitif, ce qui sépare les touches c'est le dessin
    de l'ELECTRODE et les gardes ; le plexi n'est que diélectrique et guide de
    lumière, et rien ne bouge. La découpe ne créait donc que des porte-à-faux et des
    amorces de fissure dans une matière cassante.
    Référence : l'Arturia MicroFreak fait exactement cela — clavier capacitif plat,
    blanches séparées par de simples reliefs peu profonds, noires sur une couche
    légèrement surélevée, aftertouch par mesure de la surface de contact.
    - s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
    [clavier_piano.scad]
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2026-08-20 Méca : implantation fonctionnelle — l'écran remplit l'espace libéré
    Disposition d'après nidmi-seq-vst/CONCEPTION.md §2 (qui prime : « la simulation
    fait foi », et VISION_ERGO_HARMONIE.md §3 est périmé à 5 encodeurs).
    Six molettes Row · Pas · Valeur · Vélo · Durée · Master, groupées par fonction :
    - Row et Pas (navigation) à GAUCHE de l'écran ;
    - Valeur, Vélo, Durée (attributs du pas) à DROITE ;
    - Master isolé à l'extrémité de la rangée de boutons — transversal, « jamais
    prêté ». L'y mettre l'écarte des attributs sans coûter de profondeur,
    contrairement à une rangée dédiée (essayée, +28 mm).
    Huit boutons en trois groupes : 3 vues · SHIFT · 4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
    [implantation.scad]
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2026-08-20 BOM : CrowPanel Advance 7.0-HMI retenu — et les « 11 broches libres » démystifiées
    Modèle : CrowPanel Advance 7.0-HMI ESP32 AI Display, 34,90 $. ESP32-S3 avec 8 Mo
    PSRAM / 16 Mo flash = exactement le N16R8 déjà spécifié -> aucun changement de
    plateforme.
    Les « 11 broches libres » annoncées sont trompeuses : « libre » y signifie sans
    rôle de démarrage, pas inutilisée. Croisement fait :
    - IO7, IO17, IO18, IO21 sont des lignes de données de l'écran ;
    - IO15/IO16 sont le bus I2C (GT911, RTC, rétroéclairage) ;
    - restent RÉELLEMENT IO2, IO4, IO5, IO6, IO8, au prix du haut-parleur, du micro,
    de la microSD et du buzzer — sans usage ici.
    Bilan cerveau : l'I2C passe (aucu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
2026-08-20 Étude LED : cloisons entre touches — trait de scie + lamelle noire, mesuré
    Montage retenu : trait de scie TRAVERSANT entre blanches, bloc uni dans la partie
    cachée (peigne), film collé par-dessus qui unifie la surface et bloque la
    poussière — une fente ouverte sur un instrument joué se remplit de crasse.
    Mesure : trait nu -> « un tout petit peu » de lumière passe ; trait + lamelle
    noire -> rien du tout.
    Deux prédictions théoriques corrigées par la mesure :
    1. une lame d'air nue ne réfléchit PAS la lumière guidée (la normale d'une paroi
    verticale est horizontale, la lumière guidée la frappe sous l'angle critique)
    -> c'est l'ABSORPTION qui fait la barrière, à to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
    [optique_cloison.scad]
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2026-08-20 Méca : la fente occupe la moitié de la touche — un seul pont large
    Correction de géométrie : la fente qui reçoit la dent du PCB ne traverse pas
    presque toute la largeur avec deux petits ponts latéraux, elle occupe LA MOITIÉ
    de la touche. L'autre moitié reste pleine et forme UN SEUL PONT LARGE.
    Mécaniquement bien meilleur : moins de concentration de contrainte qu'avec deux
    ponts étroits, ce qui compte en matière cassante. Et la dent du PCB, désormais
    large de ~9 mm, a la place d'accueillir sa LED et ses pistes sans risquer de
    casser à l'insertion.
    L'objection optique ne tient pas : le dos ne reçoit presque rien, la LED regarde
    l'avant et le FR4 arrête ce qui part en arrièr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
    [coupe_cellule.scad]
2026-08-20 Méca : poche au dos + PCB à plat — le peigne n'est jamais sectionné
    Correction de géométrie. Rien ne traverse le bloc à l'arrière : la découpe est
    une POCHE FRAISÉE DANS LA FACE INFÉRIEURE, sur la moitié de la largeur de chaque
    touche. Il reste 4 mm de matière au-dessus sur 10 — c'est toute cette épaisseur
    qui retient la touche au dos, plus besoin de ponts étroits ni de congés au pied.
    Ma coupe en long précédente tranchait le bloc de part en part et montrait donc un
    peigne sectionné : c'était faux.
    Le PCB arrière est POSÉ À PLAT au fond, dans une découpe de la mousse, une LED
    sous chaque poche éclairant vers le haut. Circuit ordinaire, aucune insertion par
    la tr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
    [coupe_cellule.scad]
2026-08-20 Méca : cloison à mi-épaisseur, et la coupe B passe par la moitié pleine
    Deux corrections de géométrie, toutes deux venues de l'utilisateur.
    1. LA CLOISON DU MILIEU N'ENTAME QUE LA MI-ÉPAISSEUR (5 mm sur 10). Suffisant
    pour bloquer la lumière entre les deux zones, et surtout rien n'a besoin
    d'être soutenu au milieu de la touche : ni cache, ni PCB ne peuvent y passer.
    Je la dessinais traversante, ce qui aurait sectionné la touche en son milieu.
    2. LA COUPE EN LONG DOIT PASSER PAR LA MOITIÉ PLEINE. La fente arrière n'occupant
    que la moitié de la largeur, une coupe par la moitié ouverte montrait un
    peigne sectionné — ce qu'il n'est pas. La fente et la dent du PC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
    [coupe_cellule.scad]
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2026-08-20 Méca : fente arrière partielle elle aussi, et PCB en appui sur le socle
    Deux corrections, même principe que la cloison du milieu.
    1. LA FENTE ARRIÈRE N'ENTAME QUE 7 mm SUR 10, par le dessous. Rien ne traverse :
    la matière du dessus reste continue et retient la touche au dos sur toute sa
    largeur. La demi-largeur n'est donc plus une nécessité mécanique — elle peut
    être élargie si l'optique le demande.
    Aucune découpe ne traverse désormais le bloc ; seuls les traits de scie entre
    blanches traversent, et ils s'arrêtent au dos.
    2. LE PCB PREND APPUI SUR LE SOCLE, à travers une découpe de la mousse, et non
    sur la mousse. Une mousse se comprime : la distance LED-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
    [coupe_cellule.scad]
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2026-08-20 Skill : demander avant de dessiner, et procéder par couches
    Nouvel article 3, tiré de cinq interprétations fausses successives sur
    l'assemblage du clavier. Chaque fois : un modèle complet construit à partir d'une
    phrase, un rendu de plusieurs minutes, et un aller-retour nécessaire de toute
    façon pour corriger. La seule fois où la question a été posée avant de dessiner,
    le résultat était juste du premier coup.
    Deviner n'est pas plus rapide. Et le point d'ambiguïté récurrent de ce projet est
    toujours le même : est-ce que ça traverse ou pas, et par quel plan on coupe.
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
